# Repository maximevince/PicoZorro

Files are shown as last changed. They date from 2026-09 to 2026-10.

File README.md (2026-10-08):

# PicoZorro

An RP2350 microcontroller on the Amiga **Zorro II** bus. PIO state machines
speak the bus protocol, XRDY inserts wait states while the firmware fetches
the data, and the card's registers appear in the Amiga's address space
through Autoconfig. No CPLD, no FPGA, no level shifters. Open hardware,
open firmware, open drivers.

The first card is the **PicoZorro One**: Ethernet, a USB host port and an
MP3 decoder for an A2000-class Zorro II slot. Its through-hole version, the
**PicoZorro One TH**, is built from off-the-shelf modules and a handful of
through-hole parts, so that anyone with a soldering iron can make one.

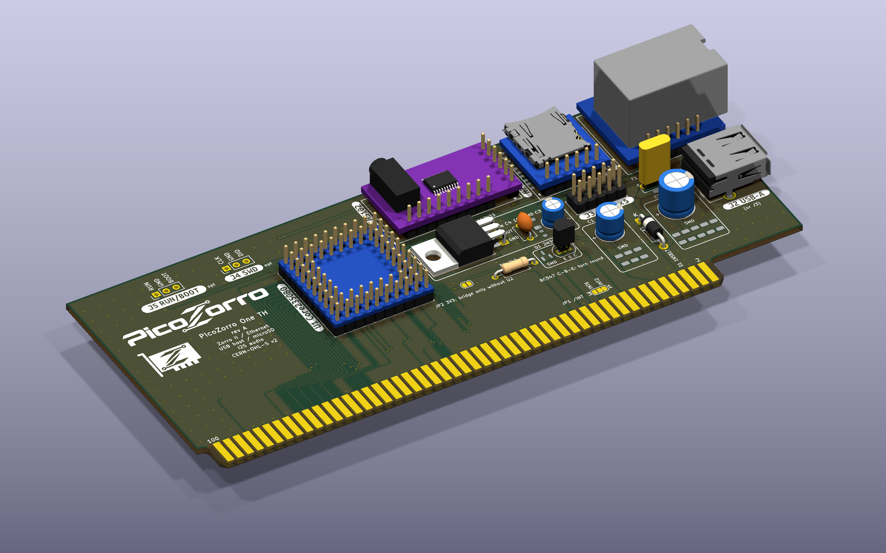
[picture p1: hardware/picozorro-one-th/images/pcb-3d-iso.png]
PicoZorro One TH, rev A


| What | How | Amiga side |
|---|---|---|
| Ethernet 10/100 | W5500 module on SPI | `picozorro.device`, a SANA-II driver (Roadshow, AmiTCP, ...) |
| USB host (full speed) | the RP2350's USB port | `picozorrousb.device` for Poseidon |
| MP3 / MP2 decoding | minimp3 on the card | `mpega.library`, a drop-in replacement for the 68k one |
| Boot ROM | the drivers served from the card | nothing to install: Kickstart loads them at boot |
| Firmware updates | A/B partitions in the module's flash | `pzflash` on the Amiga |

## One TH: two builds, one board

The One TH PCB carries two parts lists. Every through-hole part has an SMD
alternate on the same nets, in the same footprint area, and only one of
the two is ever fitted. Same Gerbers, same firmware, same Amiga software.

| DIY build (all through-hole) | JLC build (SMD set assembled by JLCPCB) |
|---|---|
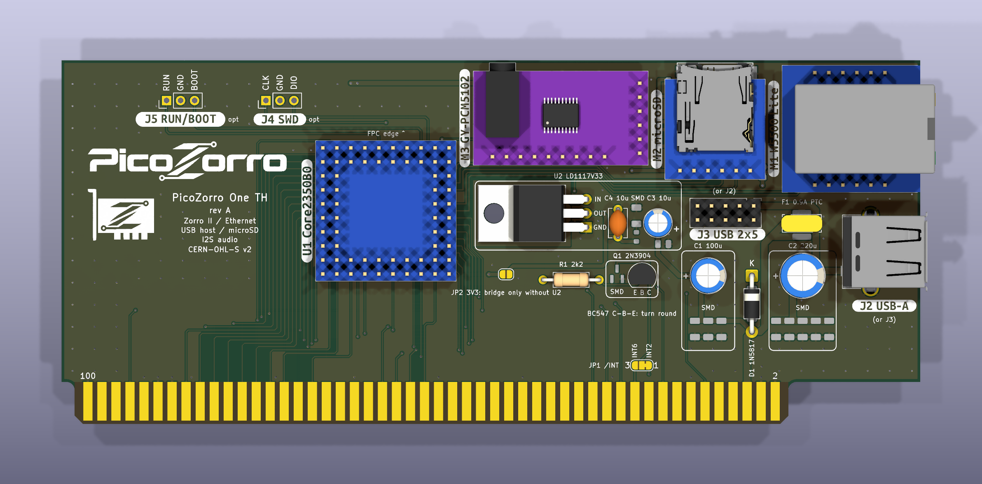
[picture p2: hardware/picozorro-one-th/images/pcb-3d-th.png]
One TH, DIY build
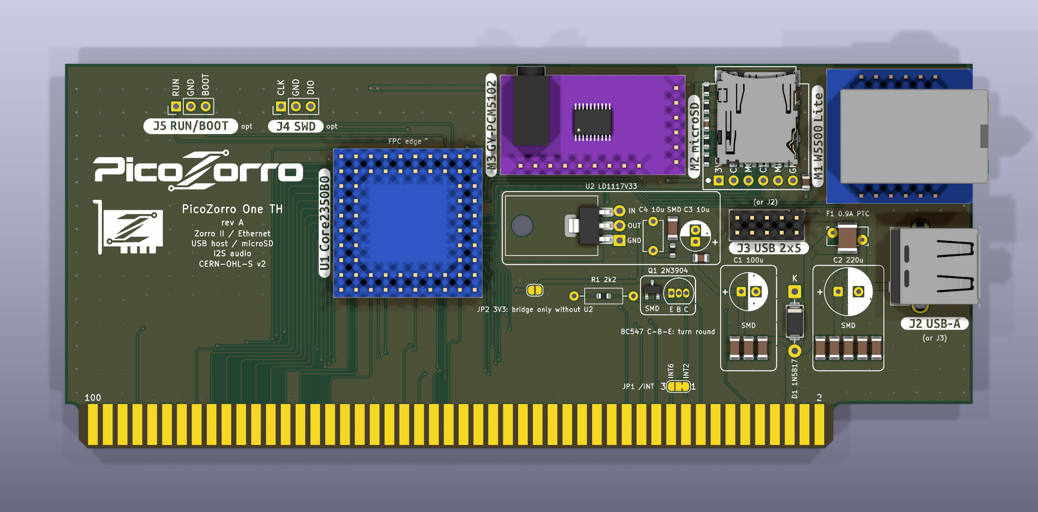
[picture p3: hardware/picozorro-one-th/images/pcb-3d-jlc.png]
One TH, JLC build
|  |  |
| KiCad's default variant. You solder everything: 1N5817, radial PTC, 2N3904, axial resistor, LD1117V33 in TO-220, electrolytics, a microSD breakout. | KiCad variant `JLC`. JLCPCB places SS14, 1812 PTC, MMBT3904, 0603 resistors, an AMS1117-3.3 (SOT-223) and banks of 22 uF MLCCs, plus a Hirose push-push microSD socket. You solder only the modules on their headers and the USB connector (J2 or J3). |
| Parts list: `fab/picozorro-one-th-parts.csv` | BOM and placement: `fab/jlc/picozorro-one-th-bom-jlc.csv`, `fab/jlc/picozorro-one-th-cpl-jlc.csv` |

Both builds take the same bought modules (Core2350B0, W5500 "Lite", the
optional GY-PCM5102 DAC). The silk frames each through-hole / SMD pair
under one label, so the board reads the same either way. Order options,
the full part-by-part table and the LCSC numbers are in
`hardware/picozorro-one-th/README.md` and `fab/order-notes.txt`.

## Status

- Firmware and drivers run on a prototype (a Core2350B module on a carrier
  board) in an Amiga: Ethernet, USB mass storage, MP3 playback.
- The **PicoZorro One TH** board is designed, routed and passes ERC/DRC.
  It has **not been built yet**. Do not order boards until this says so.
- The default firmware build is the One's image (features `xrdy-direct`,
  `int-nfet`, `usb-host`); the One TH and the One SMD share one pin map
  and one image. The four pins that differ from the prototype
  (microSD chip select, I2S) are unused, and the text log on GPIO46 lands
  on the DAC's bit-clock pin, which is harmless while no DAC is fitted.
- microSD and the I2S DAC are on the board for later; no firmware uses
  them yet.

## Repository

| Path | What |
|---|---|
| `hardware/picozorro-one-th/` | KiCad project, fabrication files, parts list and design notes of the One TH |
| `hardware/lib/` | the PicoZorro KiCad library (the Zorro II edge connector) |
| `hardware/EDGE_CONNECTOR.md`, `hardware/PINMAP.md` | edge-connector orientation with its evidence; the GPIO map |
| `firmware/` | RP2350 firmware in Rust on embassy: `pz-core` (Autoconfig, register window, network model, host tests), `pz-hal`, `pz-app` (the `picozorro` image, `hello`, `nic-demo`, `bus-listen`) |
| `amiga/` | the Amiga drivers, `mpega.library`, `pzflash`, the boot ROM, test and diagnostic tools; built with bebbo's GCC in docker |
| `tools/` | firmware image tools: update file, boot image, flashing |
| `docs/` | the register interface (`REGISTERS.md`, `REGISTERS-USB.md`, `REGISTERS-MPEG.md`), firmware updates (`UPDATE.md`), Zorro II electrical facts |

## From a bare board to a network

1. Build the card: `hardware/picozorro-one-th/README.md` (parts list,
   fabrication files, what to check before the first power-up).

   Steps 2 and 3 can be skipped: each
   [release](https://github.com/maximevince/PicoZorro/releases) carries
   `picozorro-install.uf2`, `picozorro.pzf` and the Amiga software, built
   by CI (`.github/workflows/build.yml`).
2. Build the Amiga software once, it goes into the firmware's boot image:

       make -C amiga toolchain   # once: pulls the image, fetches NDK 3.2 and the Poseidon headers
       make boot                 # drivers + boot ROM -> firmware/boot.img

3. Build and install the firmware, module on the bench, not in the Amiga:

       make fw-uf2               # firmware/picozorro-install.uf2

   Hold BOOTSEL while plugging the module's USB into the PC and copy
   `picozorro-install.uf2` onto the USB drive that appears. With an SWD
   probe, `make fw-install` does the same over SWD. This writes the A/B
   partition layout, so later updates come from the Amiga
   (`docs/UPDATE.md`), no cable needed. The UF2 route has not been
   exercised on a module yet; the SWD route has.
4. Card in the slot, Amiga on. Kickstart finds the card (manufacturer 2011,
   product $5A), loads `picozorro.device`, `picozorrousb.device` and
   `mpega.library` from it. Point your TCP/IP stack at `picozorro.device`
   unit 0 and Poseidon at `picozorrousb.device`: `amiga/README.md`.

Other targets: `make` (host tests + every firmware binary), `make amiga`,
`make fw-uf2 BIN=hello` (a first-light image as UF2), `make check-one-th`
(ERC + DRC). Needs: rustup (stable; the toolchain file adds the target),
arm-none-eabi-gcc (the MP3 decoder is C), picotool, probe-rs with RP2350
support for SWD, cargo-binutils for the update and install files; for `make amiga`:
docker, lha (or 7z), curl. Details in `firmware/README.md` and `amiga/README.md`.

## Safety

The card sits on the CPU bus of a machine that is not made any more.
Open-collector lines (XRDY, /INT2, /INT6) are never driven high. The
edge-connector orientation is documented with its evidence in
`hardware/EDGE_CONNECTOR.md`; check it against your board before powering
anything.

## Why the RP2350 sits on the 5 V bus without level shifters

The Zorro II bus is 5 V TTL. The RP2350's GPIO0-39 are fault-tolerant pads:
Raspberry Pi specifies them to 5.5 V **as long as IOVDD (the chip's 3.3 V)
is powered**. With IOVDD at 0 V the same pad is only rated to 3.63 V, and the
datasheet says a pad above that with IOVDD off will be damaged. So the whole
question is the first milliseconds after switch-on: can the bus be above
3.63 V before the card's 3.3 V regulator has come up?

Reasoning first: the bus drivers and pull-ups are fed from the same +5 V
rail that feeds the card's regulator, so no bus line can be ahead of that
rail. Below regulation an LDO just passes its input minus a drop, so IOVDD
follows the rail closely. The datasheet's limit only bites if the regulator
*delays* its start by more than the time the rail needs to travel from where
the LDO can start (about 2.3 V) to 3.63 V.

Then measured, with a logic analyser's analog channels:

- An Amiga's Zorro +5 V rises to 5.1 V in 3.4 ms; **2.3 V to 3.63 V takes
  about 1 ms**, 3.63 V to 4.2 V another 0.5 ms.
- The Core2350B's regulator (ME6217, 3.3 V), hit with a hard 5 V step on its
  input as the worst case: **3V3 reaches 3 V about 50 us later.**

50 us against 1 ms is a 20x margin, and on the real ramp the regulator does
not even see a step. IOVDD is therefore always above 1.8 V when the bus
passes 3.63 V and above 2.5 V when it passes 4.2 V, which is what the
datasheet's rating table asks for. The silicon on the module is an A4
stepping, the one Raspberry Pi qualified as 5 V tolerant; the erratum that
made A2 parts leak (RP2350-E9) is fixed from A3 on.

What this does **not** cover: hot-plugging a card into a live machine, or a
card whose 3.3 V rail is dead while the bus is up. Both put 5 V on unpowered
pads. Don't.

## Licence

Copyleft on purpose: forks stay open.

- Firmware, tools and the Amiga software: **GPL-3.0-or-later**
  (`LICENSES/GPL-3.0-or-later.txt`). The Rust dependencies (embassy and
  friends, MIT / Apache-2.0) are compatible. Vendored code keeps its own
  licence: `firmware/vendor/`.
- Hardware (`hardware/`): **CERN-OHL-S-2.0**, strongly reciprocal
  (`LICENSES/CERN-OHL-S-2.0.txt`).
  Three of the 3D models in `hardware/picozorro-one-th/3d/` embed parts of
  the KiCad library and are CC BY-SA 4.0 with KiCad's exception
  (`3d/SOURCES.txt`).
- Documentation: **CC BY-SA 4.0** (`LICENSES/CC-BY-SA-4.0.txt`).

Copyright Maxime Vincent.

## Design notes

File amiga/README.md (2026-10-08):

# Amiga software

Drivers, library and tools for the PicoZorro card, plain 68000 code for
AmigaOS 2.04 (V37) and up.

| Component | What it is |
|---|---|
| `picozorro.device` | SANA-II network driver for the card's Ethernet, for Roadshow, AmiTCP and other SANA-II stacks. `s2test` checks it command by command without a network (`ENV:PZNET` = `loop`). |
| `picozorrousb.device` | USB host-controller driver for Poseidon (legacy `IOUsbHWReq` interface): a root hub with one port, control, bulk and interrupt transfers. `usbtest` enumerates a device without Poseidon; `stortest` reads (and optionally writes) a USB stick through Poseidon's `usbscsi.device`. |
| `mpega.library` | Drop-in `mpega.library` 2.x: MP3 / MP2 decoded on the card, the PCM returned as the original library returns it, for players that use it. `mpegtest` drives it as a player does. |
| `pzflash` | Firmware update from the Amiga, see `docs/UPDATE.md`. |
| `bootrom` | The card's boot ROM (`boot.bin`, 256 bytes at most): Kickstart runs it at boot and it loads the drivers and the library from the card, so they need no files on disk. `tools/mkboot.py` puts it and the modules into the firmware's boot image (`make boot` at the top). |
| `pztest` | Finds the card and checks its scratch register with word and byte accesses. |
| `pztools/pzbench` | Zorro II bandwidth to the card's register window, per access pattern. |
| `pztools/pzload` | CPU load meter (window, optional log file). |
| `pztools/memdump` | Copies a range of the address space to a file (expansion ROMs, the card's registers). |
| `pztools/devinfo` | Mount parameters of every filesystem device. |
| `pztools/memcheck` | Walks exec's free memory lists and task lists without validating calls, for tracking down memory corruption. |

`common/` holds what the drivers share: `compiler.h` (register arguments)
and the developer links below.

## Building

The tree builds with bebbo's m68k-amigaos-gcc and vasm from a docker image
pinned by digest (`common/gcc.mk`). Once:

    make toolchain

pulls the image and fetches into `.toolchain/` what it does not carry: the
NDK 3.2 R4 from Aminet (`http://aminet.net/dev/misc/NDK3.2.lha`, for the
SANA-II and Roadshow headers; needs `lha` or `7z`) and Poseidon's headers from
`github.com/rondoval/poseidon-backport` at a pinned commit. Then:

    make            # everything
    make clean

A local bebbo install works too: `make AMIGA_GCC=m68k-amigaos-gcc
AMIGA_VASM=vasmm68k_mot`. `make DEBUG=1` in a driver's directory builds it
with log lines on the serial port. `make PROF=1` in `picozorrousb.device`
builds the driver with E-clock timestamps around every interrupt IN report;
`pzusbprof` (built there too) prints them, `pzusbprof reset` zeroes them.

## Installing

With the card's boot ROM on (the default with a boot image in the
firmware), Kickstart loads `picozorro.device`, `picozorrousb.device` and
`mpega.library` from the card at boot; `pzflash BOOTROM ON|OFF` switches it
from the next reset. Installed from disk instead, or to run a newer build:

- `picozorro.device` to `DEVS:Networks/`. Roadshow: an interface file such
  as `DEVS:NetInterfaces/PicoZorro` with
  `device=picozorro.device`, `unit=0`, `configure=dhcp`. Other stacks take
  the same device name and unit 0.
- `picozorrousb.device` to `DEVS:USBHardware/`; select it, unit 0, in
  Poseidon's Trident prefs. `usbtest` opens it from `DEVS:`.
- `mpega.library` to `LIBS:`.
- `pzflash`, `pztest` and the tools anywhere in the path.

The drivers look for the card through expansion.library (manufacturer
2011, product $5A) and take its interrupt on /INT2. With the card's
interrupt on /INT6, set `ENV:PZNET` and `ENV:PZUSB` to `pz 6`
(`SetEnv SAVE PZNET "pz 6"`). `ENV:PZUSB` also takes `minpoll=N` after the
backend (`pz minpoll=4`): the floor for the poll interval of interrupt
endpoints in ms, default 10, 0 for none.

## Developer backends

Besides the card on the Zorro bus (backend `pz`), the drivers can reach the
card's registers, or a stand-in, over other links: `bp` (the register
window over a serial line, `common/bpclient.c` and `common/serlink.c`, to a
module running `picozorro` with the `uart-backplane` feature), `uae` (a
lower SANA-II device under FS-UAE for picozorro.device, a UDP tunnel for
picozorrousb.device), `ser` (picozorrousb.device's tunnel over a serial
line) and `loop` (picozorro.device, frames come straight back). They are
selected with `ENV:PZNET`, `ENV:PZUSB`, `ENV:PZMPEGA` and `pzflash BP`, and
let the drivers be developed against FS-UAE or a bench PC; the test bed
itself is not published yet.

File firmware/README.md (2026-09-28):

# PicoZorro firmware (Rust, embassy)

The firmware of the PicoZorro cards: an RP2350B serves the Zorro II bus from
PIO and core 1, and runs the Ethernet chip, the USB host and the MPEG audio
decoder on core 0. Cargo workspace:

| Crate | What |
|---|---|
| `pz-core` | `no_std`, no dependencies: Autoconfig ROM and slave (`autoconfig`, `slave`), register window (`window`), network model (`nic`: rings, STATS, MCAST), USB window (`usb`), MPEG registers (`mpeg`), firmware update registers (`update`), boot ROM and boot stream (`boot`), pin map (`pins`: one map for every board), MAC rule (`mac`). Runs on the host: `cargo test-host`. |
| `pz-hal` | embassy-rp pieces the images share: `chip` (the Ethernet chip on SPI1, features `nic-w5500` / `nic-enc28j60` / `nic-poll`, which `pz-app` forwards), `usb::cdc_with_reset` (CDC ACM plus the picotool reset interface), `usb_host` (the RP2350 as USB host for Poseidon, feature `usb-host`), `backplane` (see "Developer features"). |
| `pz-app` | The RP2350B images, below. |

Images (`pz-app` binaries):

| Binary | What |
|---|---|
| `picozorro` | The card's firmware. Core 1: the bus slave (`zbus.rs`, from RAM). Core 0: the Ethernet chip if one answers on SPI1 (none: bus slave only, link down, TX frames dropped), the USB host or the USB log, the MPEG decoder, the firmware update and boot stream tasks, a text log on GPIO46 (115200 8N1). |
| `hello` | First light without a probe: `log` over USB CDC, chip stepping, package, OTP chip ID and MAC, LED heartbeat, picotool reset interface. |
| `nic-demo` | Ethernet chip check on SPI1 (W5500 by default, ENC28J60 with `nic-enc28j60`): DHCP, ping, TCP echo on port 7, defmt over RTT. |
| `bus-listen` | Passive bus listener for a card's first power-up in an Amiga: drives nothing on the bus, reports the bus pins and /AS statistics once per second over the UART and USB CDC. |

## Build

Needs rustup (the toolchain file installs stable with the
`thumbv8m.main-none-eabihf` target) and `arm-none-eabi-gcc` for the MPEG
decoder (minimp3 is C).

    cargo build --release                       # every image, default features
    cargo test-host                             # pz-core's tests on the host

The default features build the PicoZorro One's image: XRDY from the GPIO,
/INT through its transistor, the USB port as host. The One TH and the One
SMD share one pin map and one image.

For bring-up, the same image with the USB port as a CDC log instead of the
USB host (`usb-log`):

    cargo build --release --bin picozorro --no-default-features \
        --features nic-w5500,mpeg,oc240,xrdy-direct,int-nfet,usb-log

The ELFs land in `target/thumbv8m.main-none-eabihf/release/`.

`build.rs` embeds a boot image if there is one (`firmware/boot.img`, or the
path in `PZ_BOOT_IMG`), made by `tools/mkboot.py` from the Amiga modules;
without one the card has no boot ROM. `PZ_VERSION` overrides the version
string (default: crate version and git short hash).

## Flash

With an SWD probe (Raspberry Pi Debug Probe, J-Link, ...) and probe-rs 0.25
or later (`cargo install probe-rs-tools --locked`), `cargo run` flashes and
streams the defmt log over RTT:

    cargo run --release --bin picozorro [--features ...]

Without a probe, as a UF2 file: hold BOOTSEL while the module powers up,
it shows up as a USB drive, copy the file onto it. `make fw-uf2` (top
level) writes `firmware/picozorro-install.uf2`, which installs `picozorro`
partitioned (`docs/UPDATE.md`); `make fw-uf2 BIN=hello` writes a plain UF2
of any other image. Or over USB with picotool:

    picotool load -f -x -t elf target/thumbv8m.main-none-eabihf/release/picozorro

`-f` reboots an image that has the reset interface (`hello`, `bus-listen`,
`picozorro` with `usb-log`) into BOOTSEL first; otherwise hold BOOTSEL while
the module powers up. picotool needs access to the RP2350's USB device
(VID 2e8a): a udev rule such as

    SUBSYSTEM=="usb", ATTRS{idVendor}=="2e8a", MODE="0660", TAG+="uaccess"

in `/etc/udev/rules.d/99-picotool.rules`, or sudo.

`cargo run`, `picotool load` and a plain UF2 write the image to the start
of flash. The A/B partition layout that firmware updates from the Amiga need
is described in `docs/UPDATE.md`.

## Features (`pz-app`)

Default (the PicoZorro One): `nic-w5500`, `mpeg`, `oc240`, `xrdy-direct`,
`int-nfet`, `usb-host`. The other features are alternatives for other
wiring or for bring-up; `usb-log` and `nic-enc28j60` replace a default, so
they go with `--no-default-features` and the rest of the list.

| Feature | What |
|---|---|
| `nic-w5500` | W5500 Ethernet chip on SPI1. |
| `nic-enc28j60` | ENC28J60 instead (`nic-demo`; use with `--no-default-features`). |
| `nic-poll` | W5500 without /INT: the RX size is polled every 500 us; frees GPIO39. |
| `xrdy-direct` | XRDY driven from GPIO27 (the PicoZorro One). Without it: an on-board gate pulls XRDY, the PIO drives /ARM. |
| `int-nfet` | /INT through a transistor (N-MOSFET or NPN): GPIO45 push-pull, high asserts (the PicoZorro One). Without it: an open-drain buffer, low asserts. |
| `mpeg` | MPEG audio decoder for mpega.library (`docs/REGISTERS-MPEG.md`). Needs `arm-none-eabi-gcc`. |
| `usb-host` | The USB port as host for Poseidon (`docs/REGISTERS-USB.md`). Not with `usb-log`. |
| `usb-prof` | `usb-host` plus a timing profile and flight recorder of USB transfers, read over SWD. |
| `write-guard` | `usb-host` refuses writes to the mass-storage sticks listed in `pz_hal::usb_host`. |
| `usb-log` | The USB port as a device instead of `usb-host`: CDC ACM text log plus the picotool reset interface, for bring-up. |
| `oc240` | clk_sys 240 MHz at 1.15 V (above the RP2350's 150 MHz rating). Without `oc240` / `oc300`: 150 MHz. |
| `oc300` | clk_sys 300 MHz at 1.25 V. |
| `bus-prof` | Core 1 cycle counts per bus cycle and loop pass in the log. |
| `bench-host` | Developer build, see below. |
| `uart-backplane` | Developer build, see below. |

## Developer features

`bench-host`, `uart-backplane` and pz-hal's `backplane` module are links
that let the firmware run without an Amiga: `bench-host` has core 1 play
the Amiga driver for network tests from a PC, `uart-backplane` serves the
register window over UART0 (GPIO0/1) so that FS-UAE or a PC tool can drive
the card's models. Neither image is for a card in an Amiga (GPIO0/1 are bus
data lines). The test bed they connect to is not published yet.

## embassy

The embassy crates come from embassy git main, for the RP2350 USB host
driver that no release has yet, through a fork
(`https://github.com/maximevince/embassy`) with embassy-rp fixes for the
USB host and BufferedUart. The workspace `Cargo.toml` swaps them in with
`[patch.crates-io]`; the crates keep their crates.io version requirements.
On main, embassy-net runs on the xarxa stack: sockets have no buffers of
their own and take packets from a global pool.

`vendor/embassy-net-wiznet` is main's W5500 driver plus PicoZorro's
additions (MAC filter switch, PHY state, interrupt wake-up count, recovery
of a chip that lost its set-up), see its `CHANGELOG.md`. `vendor/minimp3`
is lieff/minimp3, unchanged. `pz-app/memory.x` and `build.rs` follow
embassy's `examples/rp235x`.

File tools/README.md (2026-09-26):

# Tools

PC-side helpers for building and installing PicoZorro (Python 3, POSIX sh).

| Tool | What it does |
|---|---|
| `mkpzf.py` | Makes a firmware update file (`.pzf`) from the firmware ELF, for `pzflash` on the Amiga (`make fw-pzf`, `docs/UPDATE.md`). With `--bin --no-tbyb`, the plain image for an SWD install; with `--uf2 pt.bin`, the install UF2 for a drop on the module in BOOTSEL mode (`make fw-uf2`). Needs `rust-objcopy` (cargo-binutils). |
| `mkboot.py` | Builds the firmware's boot image from the boot ROM (`amiga/bootrom/boot.bin`) and the Amiga drivers it loads at boot (`make boot`). |
| `pz_install.sh` | Installs the firmware with the A/B partition table, so it can be updated from the Amiga afterwards (`make fw-install`), over SWD with `probe-rs`. Needs `picotool` for the partition table. Without a probe, `make fw-uf2` writes the same content as a UF2 file. |

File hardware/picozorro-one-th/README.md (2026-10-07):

# PicoZorro One TH

The PicoZorro One is the Zorro II network and USB card of the PicoZorro
project. The One TH is its through-hole version: bought modules and a
handful of through-hole parts on a bare two-layer PCB. Every through-hole
part also has an SMD alternate on the same board, so the same PCB can be
assembled by JLCPCB instead (see "Two builds" below).

- RP2350B: a Waveshare Core2350B0 module (B0 variant, no PSRAM) on four
  2x8 pin strips. Its PIO state machines speak the Zorro II bus directly.
- Ethernet: a W5500 "Lite" module (USR-ES1, WIZnet WIZ850io pinout) on SPI1.
- USB host: the RP2350's own USB port, to a type A receptacle or a PC-style
  2x5 internal header.
- Optional: microSD on SPI1 (a breakout, or a soldered socket on the JLC
  build) and a GY-PCM5102 I2S DAC breakout.

3D render of the component side, DIY build

## Status

Rev A. The schematic and the routed board pass KiCad ERC and DRC with zero
violations, DRC with schematic parity (`make check-one-th` at the top of the
repository). **The board has not been built or tested in an Amiga. Do not
order boards yet.** The open points are listed at the end of this file.

## Two builds: DIY through-hole and JLC-assembled

One PCB, two builds. The **DIY build** (KiCad's default variant) fits every
part through-hole, soldered by hand. The **JLC build** (KiCad variant `JLC`)
has JLCPCB place an SMD set, almost all JLC Basic parts; the builder then
solders only the modules on their headers and J2 (or J3).

Each through-hole part and its SMD alternate sit on the same nets and share
the footprint area; the two are never both fitted. The SMD alternate of a
part has the part's number times 100 plus 1, 2, ... as its reference (D101 is
D1's, C101-C103 are C1's bank), because KiCad cannot give one symbol two
footprints. The board hides those references; silk frames group each pair
under one label, and the JLC files name them "D1 (SMD)".

3D render of the component side, JLC build

## Files

| Path | What |
|---|---|
| `picozorro-one-th.kicad_pro`, `.kicad_sch`, `.kicad_pcb`, `.kicad_dru` | KiCad 10 project with the variant `JLC`; the edge-connector symbol and footprint come from `../lib` |
| `fab/gerbers/`, `fab/picozorro-one-th-gerbers.zip` | Gerber and Excellon drill files, the same for both builds |
| `fab/picozorro-one-th-parts.csv` | parts list of the DIY build (the SMD alternates show DNP) |
| `fab/jlc/picozorro-one-th-bom-jlc.csv`, `fab/jlc/picozorro-one-th-cpl-jlc.csv` | JLC BOM (the SMD set with LCSC numbers; the through-hole alternates as DNP) and placement file (SMD set only, rotations corrected for JLC) |
| `fab/order-notes.txt` | the options to pick in the order form, and what the builder solders in each build |
| `3d/` | STEP models of the modules and the PTC that the board references; origins and licences in `3d/SOURCES.txt` |
| `images/` | schematic (PDF, PNG), copper and silkscreen views, 3D renders: `pcb-3d-th.png` (DIY build), `pcb-3d-jlc.png` (JLC build, same view), `pcb-3d-iso.png` (DIY build, isometric) |

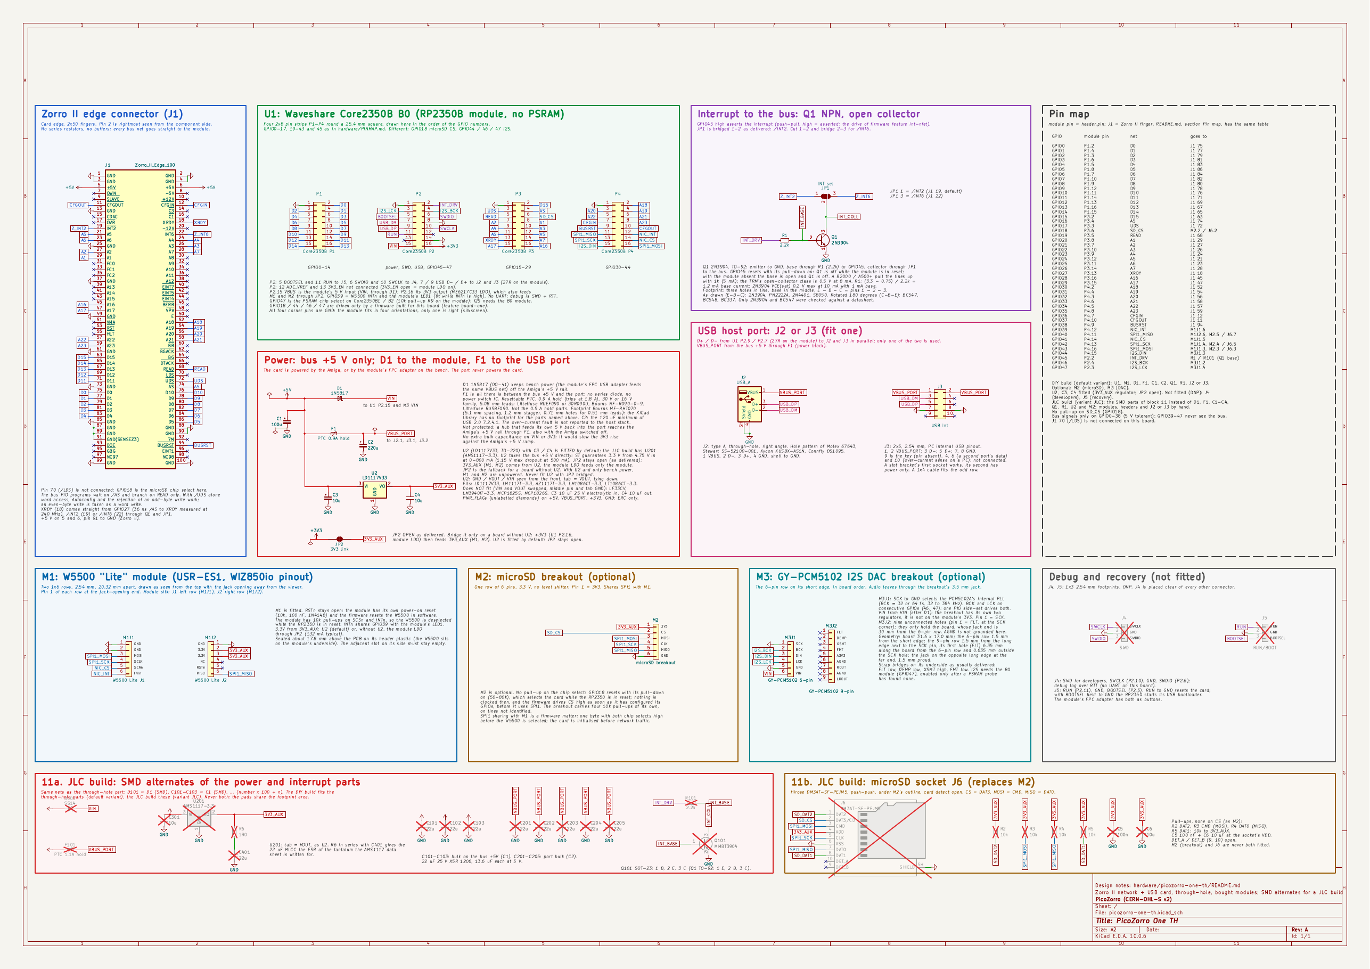
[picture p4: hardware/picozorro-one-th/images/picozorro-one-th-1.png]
Schematic


## What the builder solders

DIY build, everything by hand. The last column names the SMD alternate the
JLC build fits instead (LCSC part number in brackets; JLC Basic parts unless
marked Extended).

| Ref | Part | Value / type | Package | Fitted (DIY) | JLC build alternate |
|---|---|---|---|---|---|
| U1 (P1-P4) | Waveshare Core2350B0 module (no PSRAM) | - | four 2x8 2.54 mm pin strips | yes | same, by hand |
| M1 | W5500 "Lite" module (USR-ES1, WIZ850io pinout) | - | two 1x6 2.54 mm rows | yes | same, by hand |
| M2 | microSD breakout, 3.3 V, no level shifter | - | one 1x6 2.54 mm row | optional | J6, Hirose DM3AT-SF-PEJM5 push-push socket (C114218, Extended), with R2-R5 and C5, C6 |
| M3 | PCM5102A DAC breakout "GY-PCM5102" | - | 1x6 row (signals) + 1x9 row (holding only) | optional | same, by hand (optional) |
| D1 | Schottky diode | 1N5817 | DO-41, 10.16 mm | yes | D101, SS14, SMA (C2480) |
| F1 | resettable PTC fuse, 30 V (or 16 V) family | 0.9 A hold, e.g. Littelfuse RUEF090 | radial, 5.08 mm leads | yes | F101, 1.1 A hold, 1812, Littelfuse 1812L110/33MR (C142747, Extended) |
| C1 | electrolytic capacitor, bus +5 V | 100 uF | radial, D6.3 mm, 2.5 mm pitch | yes | C101-C103, 3 x 22 uF 25 V X5R 1206 (C12891) |
| C2 | electrolytic capacitor, USB port | 220 uF | radial, D8 mm, 3.5 mm pitch | yes | C201-C205, 5 x 22 uF 25 V X5R 1206 (C12891) |
| U2 | 3.3 V regulator for 3V3_AUX | LD1117V33 | TO-220, lying down | yes | U201, AMS1117-3.3, SOT-223, tab = VOUT (C6186) |
| C3 | U2 input capacitor | 10 uF 25 V electrolytic | radial, D5 mm, 2 mm pitch | yes | C301, 10 uF 25 V X5R 0805 (C15850) |
| C4 | U2 output capacitor | 10 uF | disc, 5 mm pitch | yes | R6 1.0 ohm 0603 (C22936) in series with C401 22 uF 1206 (C12891) |
| Q1 | NPN transistor | 2N3904 | TO-92, E-B-C | yes | Q101, MMBT3904, SOT-23, 1 B / 2 E / 3 C (C20526) |
| R1 | resistor, GPIO45 to Q1 base | 2.2 k | axial, DIN0207, 10.16 mm | yes | R101, 2.2 k 0603 (C4190) |
| J2 | USB 2.0 type A receptacle, right angle | Molex 67643 pattern | through-hole | one of J2 / J3 | same, by hand |
| J3 | PC internal USB header | 2x5, pin 9 absent | 2.54 mm header | one of J2 / J3 | same, by hand |
| J4 | SWD header: SWCLK / GND / SWDIO | - | 1x3 2.54 mm | no (developers) | same |
| J5 | recovery header: RUN / GND / BOOTSEL | - | 1x3 2.54 mm | no (recovery) | same |

The JLC build adds, with J6 only: R2-R5, 10 k 0603 pull-ups on DAT2, CMD
(MOSI), DAT0 (MISO) and DAT1 (C25804); C5 100 nF 0603 (C14663) and C6
10 uF 0805 (C15850) at J6's VDD.

U1 must be the B0 variant in both builds: on the B1 / B2 modules GPIO47 is
the PSRAM chip select, and this board needs GPIO47 for the I2S word clock.
The microSD chip select (GPIO18) works on any variant.

The parts lists are `fab/picozorro-one-th-parts.csv` (DIY) and
`fab/jlc/picozorro-one-th-bom-jlc.csv` (JLC).

F1 alternatives: Littelfuse RUEF090 or 30R090U, Bourns MF-R090-0-9,
Littelfuse RUSBF090 (0.07-0.12 ohm new, 0.22 ohm at most after a trip;
holds 0.57-0.61 A at 60 C). Not the 0.5 A hold parts: they hold 0.36 A at
50 C and drop up to 0.59 V. The footprint is KiCad's
`Fuse_Bourns_MF-RHT070` (5.1 mm lead spacing with the 1.2 mm stagger of a
radial PTC's leads, 0.71 mm holes for 0.51 mm leads); the KiCad library
has no footprint for the parts named above.

Q1 alternatives: the footprint is three holes in line, base in the middle,
emitter - base - collector as pins 1-2-3.

| Part | Pin order 1-2-3 | Fits |
|---|---|---|
| 2N3904, PN2222A, 2N4401, S8050 | E-B-C | as drawn |
| BC547, BC548, BC337 | C-B-E | rotated 180 degrees (silkscreen: "BC547 C-B-E: turn round") |

Only the 2N3904 and the BC547 were checked against a data sheet; check the
others before fitting.

U2 alternatives (pin order GND / VOUT / VIN seen from the front, tab =
VOUT): LD1117V33, LM1117T-3.3, AZ1117T-3.3, LM1086CT-3.3, LT1086CT-3.3.
They do not fit with VIN and VOUT swapped, middle pin GND, tab GND: LF33CV,
LM3940IT-3.3, MCP1825S, MCP1826S. The silkscreen names the three holes.
C3 is an electrolytic: mind its polarity.

## Solder jumpers

| Jumper | As delivered | Change |
|---|---|---|
| JP1 | bridged 1-2 by a trace: Q1 collector to /INT2 (J1 pin 19) | cut 1-2 and bridge 2-3 for /INT6 (J1 pin 22) |
| JP2 | **open** in both builds: U2 (DIY) or U201 (JLC) supplies 3V3_AUX | fallback for a board without U2: bridge it, and the module's 3V3 (U1 P2.16) feeds 3V3_AUX. Never bridge it with U2 or U201 fitted |

## Pin map

The PicoZorro GPIO map (`../PINMAP.md`) applies to GPIO0-17, 19-43 and 45.
Four pins differ on this board:

| GPIO | Module pin | Shared map | This board |
|---|---|---|---|
| 18 | P3.6 | /LDS | microSD chip select |
| 44 | P4.15 | /ARM | I2S data (DIN) |
| 46 | P2.4 | UART0 TX | I2S bit clock (BCK) |
| 47 | P2.3 | not connected / PSRAM chip select | I2S word clock (LCK), B0 module only |

The whole map:

| GPIO | Signal | Goes to |
|---|---|---|
| 0-15 | D0-D15 | J1 |
| 16 | /AS | J1 74 |
| 17 | /UDS | J1 72 |
| 18 | SD_CS | M2 pin 2 / J6 DAT3 |
| 19 | READ | J1 68 |
| 20-26 | A1-A7 | J1 |
| 27 | XRDY | J1 18, direct |
| 28-35 | A16-A23 | J1 |
| 36 | /CFGIN | J1 12 |
| 37 | /CFGOUT | J1 11 |
| 38 | /BUSRST | J1 94 |
| 39 | NIC_INT | M1 INTn (the module's LED1 is on the same pin, lit while INTn is high) |
| 40 | SPI1 MISO | M1, M2 / J6 DAT0 |
| 41 | NIC_CS | M1 SCSn |
| 42 | SPI1 SCK | M1, M2 / J6 CLK |
| 43 | SPI1 MOSI | M1, M2 / J6 CMD |
| 44 | I2S_DIN | M3 |
| 45 | INT_DRV | R1 / R101, Q1 / Q101 base |
| 46 | I2S_BCK | M3 |
| 47 | I2S_LCK | M3 |

Bus signals use only GPIO0-38 (5 V tolerant); GPIO39-47 never see the bus.
The bus nets go straight from the edge fingers to the module pins: no series
resistors, no buffers. XRDY comes from GPIO27 directly (36 ns from /AS to
XRDY measured at 240 MHz). The edge connector (J1) has +5 V on pins 5 and
6, all GND pins connected and pin 91 tied to GND.

There is no UART: debug is SWD with RTT on J4.

**/LDS (J1 pin 70) is not connected.** The bus PIO programs wait on /AS and
branch on READ only; the strobes are two bits of the sampled word, used by
the register model to tell word from byte access. With /UDS alone, word
access, Autoconfig (its writes are /UDS-only bytes on D15-D8) and the
rejection of an odd-byte write (/UDS high) work; an even-byte write cannot be
told from a word write and is taken as a word write.

**GPIO47 and the module variant.** On the Core2350B B1 / B2 modules the PSRAM
chip select sits directly on GPIO47 with a 10 k pull-up (R9); R11 (0 R) only
links the net to header pin P2.3. Driving GPIO47 there selects the PSRAM
during flash access. I2S therefore needs the B0 module, and the firmware
must not drive GPIO47 unless a PSRAM probe has found none.

### Firmware

The default firmware build is this board's image: its features
`xrdy-direct` (GPIO27 pulls XRDY) and `int-nfet` (GPIO45 push-pull, high
asserts /INT) match the bus side. The One TH and the One SMD share one pin
map and one image. GPIO18 / 44 / 46 / 47 may only be driven by a firmware
built for this board. The microSD and I2S
drivers are not written yet. When they are:

- SPI1 is shared. The SD card releases its data output one clock after its
  chip select rises, so the firmware clocks one byte with both chip selects
  high before selecting the W5500; each device gets its own SCK rate.
- An SD card that has not been put into SPI mode still listens to the
  command line. The firmware initialises the card before network traffic
  starts; a card inserted later sees W5500 traffic first.
- I2S is enabled only after a PSRAM probe has found none.

## Power

```
J1 +5V --+-- C1 --GND
         |
         +-- D1 -->|-- VIN ---- U1 P2.15 (VBUS: module LDO input)
         |                 +--- M3 VIN
         |
         +-- F1 ---+--- VBUS_PORT --- J2.1, J3.1, J3.2
         |         +--- C2 --GND
         |
         +-- C3 --- U2 --- C4 --- 3V3_AUX --- M1, M2 / J6

U1 P2.16 (3V3, module LDO output) --- JP2 (open; bridged only without U2) --- 3V3_AUX
```

JLC build: D101, F101 and U201 (C301 at its input, R6 + C401 at its output)
in place of D1, F1 and U2 (C3, C4); the bulk is two MLCC banks, C101-C103 on
the bus +5 V for C1 and C201-C205 on VBUS_PORT for C2 (40.9 and 68.2 uF
effective at 5 V). JP2 stays open in both builds.

- **D1** (Schottky) keeps bench power off the Amiga's +5 V rail: the
  module's FPC USB adapter feeds the same VBUS net.
- **F1** (PTC) is all there is between the bus +5 V and the USB port, as on
  PC motherboards (Intel 815E reference board; Intel, "Power Delivery Design
  Issues for Hi-Speed USB on Motherboards") and the fuse-only hobby host
  boards. No series diode (with a Schottky the port sat at about 4.45 V), no
  power switch IC.
- The card is powered by the Amiga, or by the FPC adapter on the bench. The
  port never powers the card.
- Not protected: a hub that feeds its own 5 V back into the port reaches the
  Amiga's +5 V rail through F1, also with the Amiga switched off. USB 2.0
  section 7.2.1 forbids a device to source current on its upstream port.

Port voltage from a 5.0 V rail at 500 mA: 5.0 - 0.06 (F1 new, 0.11 after a
trip) = 4.94 V (4.89 V). USB 2.0 Table 7-7 asks for 4.75 V at a high-power
port, so the rail may sag to 4.86 V. Section 7.2.1.2.1 asks for
resettable over-current protection below 5.0 A: F1 trips at 1.8 A (Intel's
guide sizes a single-port fuse at 1.5 A trip or more). The fault is not
reported to the host stack: there is no pin for it.

### Bulk: C1 and C2

USB 2.0 section 7.2.4.1 asks for no less than 120 uF of low-ESR capacitance
on the downstream VBUS "per hub", to keep the power of the other ports
within 330 mV when a device is plugged in (load model 10 uF with 44 ohm).
This card has one port: the only other load on that VBUS is the card's own
+5 V entry (D1 to VIN, U2) and, behind it, the Amiga rail. So both stay: C1
at the entry, C2 at the port, F1 between them (on a microsecond scale the
PTC is a plain resistor that isolates the two).

A hot-plug simulation (1 m cable, assumed rail and ESR values, not a
measurement) puts the entry droop at 0.23 / 0.15 V (PTC 0.1 / 0.3 ohm) with
the JLC build's ceramic banks, the smallest of the arrangements tried at
0.3 ohm, matched only by a low-ESR polymer 220 uF at the entry (0.22 /
0.17 V). The DIY build's two electrolytics give 0.43 / 0.29 V; a single
ordinary electrolytic at the entry (0.15 ohm ESR) 0.61 / 0.45 V, worse than
either split. The port itself dips 0.4 to 3 V for microseconds whatever is
fitted: no arrangement holds it within 330 mV with a stick plugged straight
in. Both builds lay the two groups out alike: the electrolytic on top, its
MLCC row under it in the 15 mm band.

### 3.3 V

3V3_AUX (M1, M2 / J6) has its own regulator, **U2, fitted in both builds**;
JP2 stays open and the module's LDO feeds only the module. The loads: M1
132 mA typical (W5500 data sheet section 5.4; the WIZ850io module 141 mA),
M2 up to 100 mA, the maximum averaged over 1 s in SPI mode (SD Physical
Layer Simplified Specification v3.01, Table 3-4 note 7; SanDisk's manual
gives 65 mA read and 75 mA write at most). The simplified specification
gives no peak or inrush figure. That is about 0.22 A typical, 0.24-0.27 A
at those ceilings. M3 is not on this rail: its VIN comes from VIN and it has
its own two regulators.

U2 takes the bus +5 V directly, not behind D1. DIY build: LD1117V33. ST
guarantees 3.235-3.365 V out for Vin 4.75-10 V at 0-800 mA (TJ 0-125 C,
LD1117 data sheet DocID2572 Rev 38, Table 6), dropout 1.15 V at most at
500 mA: it regulates from 4.45 V, a 0.30 V margin at the bus's 4.75 V
minimum. The JLC build fits U201, an AMS1117-3.3 (SOT-223, the same pin
order, tab = VOUT) under U2's footprint, its tab on the same 3V3_AUX copper
area. Its only guaranteed dropout is 1.3 V at 800 mA, so it needs 4.60 V: a
margin of about 0.15 V. R6 (1.0 ohm) in series with C401 (22 uF) at its
output gives the ceramic the ESR of the tantalum the AMS1117 data sheet is
written for. Dissipation in either build: (5.25 V - 3.3 V) x 0.3 A = 0.59 W
at most.

- C3, 10 uF at the input in both builds (DIY: 25 V radial electrolytic;
  JLC: C301, 0805 X5R): one value that satisfies the LD1117 (100 nF), the
  LM1117 and AZ1117 (10 uF) and the AMS1117 application circuit (10 uF). C4,
  10 uF at the output (ST's figure; ST gives no ESR window).
- With U2 fitted and the card on bench power only, M1 and M2 are unpowered
  while the module runs.

The module's regulator is the fallback (JP2 bridged on a board without
U2), not the default: the ME6217C33M5G data sheet gives 800 mA as a typical
IOUT(max) (and as the absolute maximum), no minimum, and notes it may not be
reached because of package dissipation; it gives no thermal resistance. Its
sibling ME6207 rates the SOT-23-5 package at 250 mW. The W5500 alone puts
0.25-0.41 W into it, with an SD card 0.45-0.66 W. Measured with a thermal
camera, module plus W5500 on the module's 3V3, room 20 C: nothing on the
module above 40 C (no SD card in that measurement).

There is no extra bulk capacitance on VIN or 3V3: it would slow the 3V3
rise against the Amiga's +5 V ramp.

## /INT driver

Q1, an NPN transistor, drives the interrupt line open collector: emitter to
GND, base through R1 (2.2 k) to GPIO45, collector through JP1 to /INT2
(default) or /INT6. GPIO45 high asserts the interrupt. GPIO45 resets with
its pull-down on, so Q1 is off while the module is in reset; with the module
absent the base is open and Q1 is off. GPIO45 is not 5 V tolerant, so it
cannot pull the bus line itself.

Sizing: a B2000 and an A500+ pull both lines up with 1 k (5 mA at 5 V); the
Technical Reference Manual's open-collector drive class is 0.5 V at 8 mA,
so the driver must sink at least 8 mA. R1 gives (3.3 - 0.75) / 2.2 k =
1.2 mA of base current. The 2N3904 is specified at VCE(sat) 0.2 V maximum
for 10 mA with 1 mA into the base, the BC547 at 0.25 V maximum (0.09 V
typical) for 10 mA with 0.5 mA: both operating points are covered with
margin.

A transistor and not a MOSFET: the through-hole MOSFETs hobby shops carry
(2N7000, BS170) have gate thresholds up to 3 V and are not specified at
3.3 V drive; the one that is (TN0702) is a distributor-only part. Small NPN
types are sold everywhere.

Simulated with ngspice (vendor models, 1 k to 10 k pull-ups, 4.75 to
5.25 V, 0 to 70 C, GPIO45 down to 3.0 V, R1 +5 %): /INT sits below 90 mV
with a 2N3904 and below 40 mV with a BC547B, also at a forced 8 mA;
GPIO45 sources 1.15 mA at most. Assertion takes under 125 ns into 1 nF.
Release is the pull-up RC plus the transistor's storage time: 0.25 to
0.5 us for the 2N3904, 1.4 to 2.2 us for the BC547B, so 10 k with 500 pF
reaches 2.0 V after 3.2 us (2N3904) or 4.9 us (BC547B). The 2N3904 is the
default for that reason.

## Modules

**M1, W5500 Lite.** Two 1x6 rows, 2.54 mm pitch, 20.32 mm apart; module
23.0 x 25.0 mm; pin 1 of each row at the jack-opening end, 6.4 mm from that
edge; the jack overhangs that edge by 2.5-2.7 mm. Seen from the top with the
jack opening away from the viewer (module silk J1 left, J2 right, jack
HR961160C):

| Left row (J1) | | Right row (J2) | |
|---|---|---|---|
| 1 GND | GND | 1 GND | GND |
| 2 GND | GND | 2 3.3V | 3V3_AUX |
| 3 MOSI | GPIO43 | 3 3.3V | 3V3_AUX |
| 4 SCLK | GPIO42 | 4 NC | - |
| 5 SCNn | GPIO41 | 5 RSTn | not connected |
| 6 INTn | GPIO39 | 6 MISO | GPIO40 |

RSTn stays open: the module has its own power-on reset (10 k, 100 nF,
1N4148) and the firmware resets the chip in software. The module has 10 k
pull-ups on SCSn and INTn, so the W5500 is deselected while the RP2350 is
in reset.

**M2, microSD breakout.** One 1x6 row: 3V3 (pin 1, to 3V3_AUX), CS (GPIO18),
MOSI (GPIO43), CLK (GPIO42), MISO (GPIO40), GND. Board 18 x 18 mm (18.1 mm
over its scored edges); the socket, 13.7 mm wide, overhangs the edge
opposite the pin row by 3 mm and the card enters from there. No pull-up on
the chip select: GPIO18 resets with its pull-down on (about 50-80 k), which
selects the card while the RP2350 is in reset; nothing is clocked then, and
the firmware drives the chip select high as soon as it has configured its
GPIOs, before it uses SPI1. The breakout carries four 10 k pull-ups of its
own, on lines not identified.

**J6, microSD socket (JLC build).** A Hirose DM3AT-SF-PEJM5 push-push socket
(KiCad `Connector_Card:microSD_HC_Hirose_DM3AT-SF-PEJM5`) under M2's
outline, on M2's nets, the card entering over the top edge as with M2: CS =
DAT3 (GPIO18), MOSI = CMD, CLK, MISO = DAT0, VDD = 3V3_AUX. 10 k pull-ups R2
(DAT2), R3 (CMD / MOSI), R4 (DAT0 / MISO), R5 (DAT1), none on CS; C5 100 nF
and C6 10 uF at VDD. Card detect (pins 9, 10) is not connected: no GPIO is
free. M2 and J6 are never both fitted.

**M3, GY-PCM5102.** The 6-pin row on its short edge: SCK to GND (selects the
PCM5102A's internal PLL), BCK to GPIO46, DIN to GPIO44, LCK to GPIO47, GND,
VIN to VIN. Pin 1 is SCK. The 9-pin row (FLT, DEMP, XSMT, FMT, A3V3, AGND,
ROUT, AGND, LROUT from the SCK corner) gets nine unconnected holes: it only
holds the board. Audio leaves through the breakout's 3.5 mm jack. The four
strap bridges on its underside stay as usually delivered: FLT low, DEMP
low, XSMT high, FMT low. BCK and LCK are on consecutive GPIOs so one PIO
side-set drives both; PLL mode accepts BCK = 32 fs or 64 fs from 32 kHz to
384 kHz. Geometry, from a third-party footprint (sstojos,
zynthian-miniature) cross-checked against board photos: board 31.6 x
17.0 mm; the 6-pin row 1.5 mm from the short edge; the 9-pin row 1.5 mm
from the long edge next to the SCK pin, its first hole (FLT) 6.35 mm along
the board from the 6-pin row and 0.635 mm outside the SCK hole.

## USB host port, debug and recovery

- The module's USB pins (D+ on P2.9, D- on P2.7, 27 R on the module) go to J2
  and J3 in parallel; only one of the two is fitted.
- **J2**: through-hole type A, right angle, the hole pattern shared by Molex
  67643, Stewart SS-52100-001, Kycon KUSBX-AS1N and Connfly DS1095. 1
  VBUS_PORT, 2 D-, 3 D+, 4 GND, shell to GND.
- **J3**: 2x5, pin 9 absent (key). 1 and 2 VBUS_PORT, 3 D-, 5 D+, 7 and 8
  GND; 4, 6 (a second port's data) and 10 (over-current sense on a PC) not
  connected. A PC slot bracket's first socket works, its second has power
  only. A 1x4 cable fits the odd row.
- **J4** (SWD): SWCLK (P2.10), GND, SWDIO (P2.6), placed clear of every
  other connector.
- **J5**: RUN (P2.11), GND, BOOTSEL (P2.5). RUN to GND resets the card; with
  BOOTSEL held to GND the RP2350 starts its USB bootloader. The module's FPC
  adapter has both as buttons.

## Mechanical

- Plain rectangle, no nose, bracketless, two layers, 1.6 mm FR-4.
  155.5 x 65.92 mm including the 7.62 mm tongue; the body is 58.3 mm above
  the shoulder, the low-profile PC card envelope.
- Edge connector: 2 x 50 gold fingers at 2.54 mm, orientation and geometry
  in `../EDGE_CONNECTOR.md`. ENIG with a 0.5 x 45 degree bevel on the
  finger edge is recommended; HASL works. The finger area is one open
  solder-mask window by design. JLC's Economic PCBA offers no gold fingers:
  ENIG without the bevel there, or Standard PCBA for hard-gold bevelled
  fingers.
- All parts go on the component side. The pin 1 / 2 end faces the rear panel
  on the Denise; the RJ45 and the USB-A socket go to that end. Tall parts
  sit high on the card, away from the fingers, to clear an accelerator; the
  15 mm band above the fingers holds only lying axial parts and the solder
  jumpers.
- Heights above the PCB: M1 about 17.8 mm (2.54 mm header plastic + 1.6 mm
  PCB + 13.61 mm jack; the header plastic cannot be left out, the W5500 sits
  on the module's underside); U1 on its header plastic (parts on its
  underside); U2 lying down.
- **The tall parts do not clear a neighbouring card.** Free height to the
  next card's PCB is 13.6 mm on the Denise and 18.7 mm in an A2000, before
  that card's solder-side leads. M1 needs the adjacent slot on its side
  empty in every machine.

| Target | Body height | Length | Slot pitch |
|---|---|---|---|
| Enterlogic A-NIC outline | 45.1 | 155.5 | - |
| Denise, low-profile PC card envelope | 58.3 max | about 168 | 15.24 |
| Denise, full-height PC card envelope | 100.6 max | about 171 over the board | 15.24 |
| A2000 and the Zorro II form factor | 114.5 max | 337.19 max | 20.32 |

On the Denise the card's shoulder rests 13.97 mm above the motherboard
(EDAC 745-100-520-206, notched ends), and the card goes into the slot next
to the CPU (CN4). Mini-ITX guarantees only 57 mm of free height over that
slot, which is a 43.0 mm body; the One TH relies on the case for the rest.

## First power-up

1. Before soldering the module: confirm the edge connector's orientation
   against `../EDGE_CONNECTOR.md` on the bare board (pins 2 and 4 are GND,
   pin 6 is +5 V; they sit at the rear/bracket end). Then, with the strips
   soldered and nothing else fitted, check for shorts between +5 V, 3V3
   and GND.
2. On the bench, not in the Amiga: build `hello` as a UF2 (`make fw-uf2
   BIN=hello` at the top of the repository), hold BOOTSEL (J5, or the FPC
   adapter's button) while the module powers up from its FPC adapter, and
   copy `firmware/hello.uf2` onto the USB drive that appears. Its USB CDC
   log shows the chip's stepping and MAC. D1 keeps this bench power off
   the bus pins.
3. First time in the Amiga: `bus-listen` the same way (`make fw-uf2
   BIN=bus-listen`, `firmware/bus-listen.uf2`). It drives nothing on the
   bus and prints the bus pins and the /AS statistics once a second on the
   USB CDC log, so a wrong finger shows up before anything is driven.
4. Then the card's firmware: `make fw-uf2`, drop
   `firmware/picozorro-install.uf2` the same way (or `make fw-install` with
   an SWD probe; `docs/UPDATE.md`), and `pztest` on the Amiga finds the
   card and exercises its scratch register.

## Open points

- U2 / U201 temperature at the full 3V3_AUX load (0.59 W at most, TO-220 or
  SOT-223 on the 3V3_AUX copper area). The ME6217 with M1 and an SD card on
  it applies only to a board without U2 (JP2 bridged): 40 C at most with M1
  alone, and by its data sheet not a sound default.
- The 3V3_AUX rise from U2 / U201 against the module's 3V3 and the Amiga's
  +5 V ramp. Measured only for the bare module: 18.6 us.
- The hot-plug droop figures (Power, Bulk) are a simulation with assumed
  cable, rail and electrolytic ESR values, not a measurement.
- JLC build: U201's loop with R6 + C401 next to C6 and the W5500 module's
  own ceramics (to be checked with a scope on the first board); the port
  droop with the MLCC banks at hot-plug; the CPL rotations (corrections of
  kicad-jlcpcb-tools, to be checked in JLC's DFM preview); the 3V3_AUX rise
  from U201 against the module's 3V3.
- Q101: an MMBT3904 in place of the simulated 2N3904 (a PMBT3904 model was
  among those simulated).
- /LDS: the firmware ignoring /LDS is tested on a Denise (register test,
  network, USB and Autoconfig after a reset unchanged), but not yet with
  the pin physically unconnected.
- Q1 on the bus: the NPN driver is simulated only. The firmware's
  `int-nfet` drive was run against a 2N7002 MOSFET, not an NPN transistor.
- GY-PCM5102: no maker document. Pin order confirmed from the silkscreen;
  the geometry is a third party's footprint that agrees with photo
  measurements to about 0.2 mm, not a measurement on a board.
- F1: the footprint is that of another radial PTC family; any PTC close to
  the rating fits those holes.
- microSD breakout: no maker document. Pin order, 3V3 end, socket overhang,
  board size and socket width are measured; the position of the row and of
  the socket along their edges (socket centred) is assumed; the lines of its
  four pull-ups are unknown.
- Whether R9 / R11 are fitted on the B0 module (expected: yes, so GPIO47
  has a 10 k pull-up and reaches P2.3).
- B2000 pull-ups are from drawing 312726 rev 2 only; the Denise's own /INT
  pull-ups are not measured.
- The free space next to CN4 on the Denise with an accelerator fitted (the
  TF536), at the height where the modules sit. Denise positions were
  measured on a board render; the PC envelope figures are PCI Express (CEM
  3.0 Fig 9-26); A3000 / A4000 limits beyond the form factor are not
  checked; Commodore gives no component-height limits.
- The release time of /INT against Exec clearing INTREQ after the server
  chain is not measured.
- Firmware for microSD and I2S does not exist yet.

## Sources

- Core2350B schematic: https://files.waveshare.com/wiki/Core2350B0/Core2350B.pdf
- WIZ850io: https://docs.wiznet.io/Product/ioModule/WIZ850io
- USR-ES1 manual (copy): https://iarduino.ru/lib/273f9e795d4abeaeecb3b027cae523ba.pdf
- HR961160C jack: https://wmsc.lcsc.com/wmsc/upload/file/pdf/v2/lcsc/2410122008_HANRUN-Zhongshan-HanRun-Elec-HR961160C_C55683.pdf
- ME6217: https://www.lcsc.com/product-detail/C427602.html
- 2N3904: https://www.onsemi.com/pdf/datasheet/2n3903-d.pdf
- BC547: https://www.onsemi.com/pdf/datasheet/bc546-d.pdf
- 2N7000 (why not): https://www.onsemi.com/download/data-sheet/pdf/nds7002a-d.pdf
- 1N5817: https://www.onsemi.com/download/data-sheet/pdf/1n5817-d.pdf
- Intel, Power Delivery Design Issues for Hi-Speed USB on Motherboards: https://www.usb.org/sites/default/files/power_delivery_motherboards.pdf
- Intel 815E Platform Design Guide (reference board sheet 21): https://download.intel.com/design/chipsets/designex/29823401.pdf
- RUEF: https://www.littelfuse.com/assetdocs/resettable-ptc-ruef-datasheet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
- MF-R: https://www.bourns.com/docs/Product-Datasheets/mfr.pdf
- LD1117 (DocID2572 Rev 38, Table 6): https://www.st.com/resource/en/datasheet/ld1117.pdf
- AMS1117: http://www.advanced-monolithic.com/pdf/ds1117.pdf
- ME6217 data sheet V02: https://datasheet.lcsc.com/datasheet/pdf/3d38df48f5744f9f5473666520a2674d.pdf
- ME6207 data sheet V04 (SOT-23-5 dissipation, p. 4): https://datasheet.lcsc.com/datasheet/pdf/bd2fb8a7d19717c941ded5ee758d36c9.pdf
- SD Physical Layer Simplified Specification v3.01 (Table 3-4): https://www.cs.utexas.edu/~simon/378/resources/Part_1_Physical_Layer_Simplified_Specification_Ver_3.01_Final_100518.pdf
- LF33: https://www.st.com/resource/en/datasheet/lfxx.pdf
- PCM5102A: https://www.ti.com/lit/ds/symlink/pcm5102a.pdf
- GY-PCM5102 (community drawing): https://macsbug.wordpress.com/2021/02/19/web-radio-of-m5stack-pcm5102a-i2s-dac/
- GY-PCM5102 footprint (third party): https://github.com/sstojos/zynthian-miniature/blob/main/GY-PCM5102.kicad_mod
- SanDisk SD Card Product Manual v1.9: https://www.convict.lu/pdf/ProdManualSDCardv1.9.pdf
- Kingston SDCIT: https://www.kingston.com/datasheets/SDCIT-specsheet-8gb-32gb_us.pdf
- USB-A receptacle (Stewart SS-52100-001): https://belfuse.com/resources/drawings/stewartconnector/dr-stw-ss-52100-001.pdf
- Intel Front Panel I/O Connectivity Design Guide rev 1.1 (copy): https://cdn.hackaday.io/files/1626526958903168/600569-fpio-dg-rev1p1.pdf
- USB 2.0 specification: https://www.usb.org/document-library/usb-20-specification
- Commodore B2000 schematic 312726 rev 2, A500+ service manual, A500/A2000
  Technical Reference Manual (Zorro II form factor: figures A-4 to A-6)
- PCI Express CEM 3.0 Fig 9-26; Mini-ITX Addendum 2.0 Fig 5; EDAC 745
  series ordering guide p. 2

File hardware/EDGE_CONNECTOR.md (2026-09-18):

# Zorro II card edge: orientation and geometry

A mirrored edge connector puts +5 V on signal pins, so this is written down
with its evidence.

## Orientation
Viewed from the **component side with the fingers pointing down**:
- **pin 2 is the rightmost finger, pin 100 the leftmost**; even pins are on
  the component side;
- odd pins are on the solder side, pin 1 directly behind pin 2;
- the right end is the rear/bracket end of the machine (on the Denise: the
  rear I/O end, where Enterlogic's A-NIC card has its RJ45).

Evidence:
1. Commodore A500/A2000 Technical Reference Manual, appendix A, drawing A-5
   "Amiga 2000 Form Factor" (printed rotated on the page): labelled
   COMPONENT SIDE, it shows PIN 2 165.735 mm from the bracket-end edge and
   PIN 100 further away; the bracket end is on the right when the drawing is
   turned upright.
2. The front copper artwork of Enterlogic's A-NIC card: the two rightmost
   component-side fingers tie straight into the ground pour (pins 2, 4 =
   GND) and the third has a decoupling capacitor next to it (pin 6 = +5 V).
   With pin 100 on the right that pattern would be GND, n/c, n/c.

## Geometry (TRM drawing A-5, mm)
- 50 fingers per side, pitch 2.54, row length 49 x 2.54 = 124.46
- tongue width 129.26 +/- 0.1 (so 2.40 from tongue edge to first/last finger centre)
- tongue depth 7.62; 1.5 x 45 deg corner chamfers; 0.5 x 45 deg edge bevel
- shoulder radius R1.5
- finger width: the drawing shows 1.6; the footprint uses 1.65 mm from the
  mating-board drawing of the TE 2-5530843-2 connector (.065 +/- .002 in),
  and a 1.6 mm board (the EDAC 745 series accepts 1.37 to 1.78 mm). Sources
  and the full dimension table: `lib/README.md`.

## Card outline
Enterlogic's A-NIC, a mini-Zorro card known to fit the Denise, is 155.5 x
54.3 mm, bracketless, with its I/O at the right (rear) end. The PicoZorro
One TH keeps the 155.5 mm length and the I/O end; its body is taller
(58.3 mm above the shoulder, 65.92 mm with the tongue).

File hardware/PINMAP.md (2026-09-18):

# PicoZorro pin map

One GPIO map is shared by the firmware and the boards:
`firmware/pz-core/src/pins.rs` and `firmware/pz-hal/src/chip.rs` hold the
numbers and must match this file. The PicoZorro One TH follows it except on
four pins (GPIO18, 44, 46, 47), listed in the last section.

Rules behind the map:
- 5 V bus signals only on GPIO0-39 (5 V tolerant). GPIO40-47 are 3.3 V only.
- One PIO block sees 32 pins, window base 0 or 16. GPIO16-31 is visible to
  both windows, so strobes and register-select address bits live there.
- D0-15 + strobes + A1-A7 are contiguous from GPIO0, so block A captures the
  whole cycle with one `in pins, 27`.
- A16-A23 + /CFGIN are contiguous, so block B matches the address (and the
  "my turn in the config chain" condition) with one 9-bit compare.
- XRDY sits in the shared window (GPIO27) so block A can observe it.

| GPIO | RP2350B pin | Signal | Zorro pin | Dir | Notes |
|---|---|---|---|---|---|
| 0-15 | 77-80, 1-4, 6-9, 11-14 | D0-D15 | 75,77,79,81,83,86,84,82,80,78,76,71,69,67,65,63 | I/O | driven only in own read cycles |
| 16 | 16 | /AS | 74 | in | |
| 17 | 17 | /UDS | 72 | in | |
| 18 | 18 | /LDS | 70 | in | One TH: microSD chip select |
| 19 | 19 | READ | 68 | in | high = read |
| 20-26 | 20-23, 25-27 | A1-A7 | 29,27,26,24,21,23,28 | in | register select |
| 27 | 28 | XRDY | 18 | OD out | open drain by direction switching, value 0 |
| 28-35 | 36-40, 42-44 | A16-A23 | 45,47,52,54,56,58,57,59 | in | base address compare |
| 36 | 45 | /CFGIN | 12 | in | 9th compare bit |
| 37 | 46 | /CFGOUT | 11 | out | push-pull |
| 38 | 47 | /BUSRST | 94 | in | reset input (not pin 53) |
| 39 | 48 | NIC_INT / LED | - | in | W5500 INTn (push-pull, active low); the Core2350B's LED1 is on the same pin |
| 40 | 49 | NIC_MISO | - | in | SPI1 RX |
| 41 | 52 | NIC_CS | - | out | SPI1 CSn |
| 42 | 53 | NIC_SCK | - | out | SPI1 SCK |
| 43 | 54 | NIC_MOSI | - | out | SPI1 TX |
| 44 | 55 | /ARM | - | out | One TH: I2S data |
| 45 | 56 | /INT | 19 or 22 | out | through a driver only: GPIO45 is not 5 V tolerant. One TH: NPN transistor, high asserts, /INT2 or /INT6 by jumper |
| 46 | 57 | UART0_TX | - | out | debug log, TX only, function F11. One TH: I2S bit clock |
| 47 | 58 | - | - | - | on the Core2350B B1 / B2 the module's PSRAM /CS: never drive it. One TH: I2S word clock (B0 module only) |

Not connected on the card: /OVR, /DTACK, /SLAVE, /OWN, /BR, /BG, /BGACK,
/GBG, FC0-2, E, /VPA, /VMA, /BERR, /HLT, /RST (53), A8-A15, 7M, CDAC, /C1,
/C3, -5 V, -12 V, +12 V. Pin 91 tied to GND (required of Zorro II cards).

## PicoZorro One TH

Four pins differ from the map above
(`picozorro-one-th/README.md` has the board's full table):

| GPIO | Module pin | Shared map | PicoZorro One TH |
|---|---|---|---|
| 18 | P3.6 | /LDS | microSD chip select |
| 44 | P4.15 | /ARM | I2S data (DIN) |
| 46 | P2.4 | UART0 TX | I2S bit clock (BCK) |
| 47 | P2.3 | not connected (PSRAM chip select on B1 / B2 modules) | I2S word clock (LCK), B0 module only |

/LDS is not connected on the One TH. The firmware decides word and byte
access on /UDS alone on every board, so an even-byte write is taken as a word
write. There is no UART: debug is SWD with RTT. XRDY comes straight from
GPIO27, /INT goes through an NPN transistor on GPIO45, W5500 INTn is on
GPIO39. GPIO18 / 44 / 46 / 47 are driven only by a firmware built for this
board.

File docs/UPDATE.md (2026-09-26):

# Firmware updates from the Amiga

The card's firmware is updated from the Amiga, with no cable to a PC: the
module's flash holds two image slots (A/B), `pzflash` writes the new image
into the slot that is not running, and the RP2350's bootrom runs it on trial
until `pzflash` confirms it. An image that is not confirmed is dropped by
the bootrom, and the card boots the old one again.

## In short

On the PC (firmware toolchain, see `firmware/README.md`):

    make fw-pzf                  # firmware/picozorro.pzf

On the Amiga, with the `.pzf` copied over:

    pzflash INFO                 # running version, slot, trial state
    pzflash UPDATE picozorro.pzf # FLASH, ACTIVATE, CONFIRM in one go

`pzflash` is built in `amiga/pzflash` (`make -C amiga`). The module must
have been installed partitioned once (below); `pzflash INFO` says "not
partitioned (no updates)" otherwise.

## How it works

- Flash: an A/B pair of 2 MiB partitions (`firmware/pt.json`: A at 64 KiB,
  B at 2112 KiB), the partition table in sector 0 (made by `picotool
  partition create`). The bootrom maps the booted partition to 0x10000000
  (RP2350 datasheet 5.1.19), so one image runs from either slot;
  `firmware/pz-app/memory.x` limits the image to 2 MiB.
- The module runs from one slot and writes the update into the other,
  with the bootrom's low-level flash functions (storage offsets,
  datasheet 5.4.8.10/11) from a RAM function, interrupts off. The first
  sector (the IMAGE_DEF) is written last, after the rest is in flash and
  the stream's CRC-32 matched; then the whole image is read back through
  the untranslated XIP window (0x1c000000, datasheet 4.4) and its CRC-32
  compared. A partial image never carries a block the bootrom would pick.
- ACTIVATE: `reboot(REBOOT_TYPE_FLASH_UPDATE, .., XIP_BASE + start of the
  new slot)` (datasheet 5.4.8.24; the pico-examples OTA example passes
  the address the same way). The new image carries the try-before-you-buy
  flag (set by `tools/mkpzf.py` in its IMAGE_TYPE item, picobin.h
  `PICOBIN_IMAGE_TYPE_EXE_TBYB_BITS`), so the bootrom runs it on trial
  under the watchdog (datasheet 5.1.17).
- On trial the image says so (STATUS.BUY_PENDING, from `get_sys_info`
  BOOT_INFO, pico-sdk `BOOT_TBYB_AND_UPDATE_FLAG_BUY_PENDING`) and keeps
  the watchdog fed for 120 s. CONFIRM calls `explicit_buy` (datasheet
  5.4.8.4): the bootrom clears the flag and erases the first sector of the
  old slot, so the new image stays. No CONFIRM: the watchdog fires, the
  bootrom prefers the non-TBYB old image, and the module is back where it
  was.
- Across the update reboot the new image keeps the Autoconfig base: the
  old one leaves it in watchdog SCRATCH0/1 (the bootrom uses SCRATCH2-7
  for reboot parameters), the new one starts configured there, so the
  Amiga can talk to it without a reset. The bus build does this only when
  /BUSRST is high at boot and the stash is there; any other boot waits
  for /BUSRST. If the Amiga cannot reach the card after the reboot,
  reboot the Amiga for a fresh Autoconfig.

## First install and recovery

The A/B layout is written once from a PC. Without a probe, as a UF2 file:

    make fw-uf2                  # firmware/picozorro-install.uf2

Hold BOOTSEL while plugging the module's USB into the PC: the RP2350's ROM
bootloader shows up as a USB drive. Copy `picozorro-install.uf2` onto it.
The file writes the partition table at flash offset 0, the image (TBYB
off) into partition A and erases the first sector of B. Its blocks carry
the UF2 family `absolute`, which the bootrom writes at the addresses in the
file whatever the flash held before (datasheet 5.1.18, 5.5.3;
`firmware/pt.json` allows `absolute` downloads in the unpartitioned space,
so this also works on a module that is already partitioned). The bootrom
reboots when the copy is complete and the module starts from A. After that
every update goes through `pzflash`.

With an SWD probe, `make fw-install` (`tools/pz_install.sh`, probe-rs)
writes the same three pieces. The SWD route is the one in use; the UF2
route has not been exercised on a module yet.

`probe-rs run <elf>` (`make fw-run`) and `picotool load <elf>` (`make
fw-load`) write a flat image at offset 0 and so remove the partition table;
the install UF2 or `make fw-install` put table and image back.

A plain UF2 (`make fw-uf2 BIN=hello`, family `rp2350-arm-s`) dropped on a
partitioned module does not land at offset 0: the bootrom stores it in the
A/B partition that would not be chosen at the next boot (datasheet 5.5.3,
5.5.3.1), boots it with a flash update boot, and, as the image carries no
TBYB flag, erases the first sector of the other partition (datasheet
5.1.16). The partition table stays and the dropped image replaces the
running one; a `picozorro` image dropped that way still takes updates from
`pzflash`.

Recovery when no image runs: the RP2350's ROM bootloader is always there.
Hold BOOTSEL while the module powers up and drop `picozorro-install.uf2`
again (or `make fw-install` over SWD). RP2350 chips of stepping A2 (`hello`
prints the stepping) have erratum RP2350-E10: their bootrom does not set up
the flash before it reads the partition table, and UF2 drops onto a
partitioned module can fail. A module without a partition table (new, or
flashed flat) is not affected; on an A2 a partitioned module is reinstalled
over SWD.

## Registers ($C0-$FE of the A16 = 1 window)

Model: `pz_core::update` (host tests). General rules as `docs/REGISTERS.md`
(16-bit, big-endian, byte access refused).

| Offset | Name | Access | Meaning |
|---|---|---|---|
| $C0 | UPD_CTRL | W | command: 1 BEGIN, 2 ABORT, 3 COMMIT, 4 ACTIVATE, 5 CONFIRM, 6 BOOTROM_OFF, 7 BOOTROM_ON |
| $C2 | UPD_STATUS | R | state and flags, below |
| $C4, $C6 | UPD_SIZE | RW | image length in bytes, high word first; set before BEGIN |
| $C8, $CA | UPD_CRC | RW | CRC-32 (zlib) of the image; set before BEGIN / COMMIT |
| $CC | UPD_DATA | W | data port, word k = bytes 2k, 2k+1; an odd last byte on D15-D8 |
| $D0, $D2 | UPD_DONE | R | bytes in flash so far |
| $D4, $D6 | UPD_RESULT | R | CRC-32 of the image as read back from flash |
| $D8 | UPD_SLOT_KB | R | size of a slot in KiB (0: not partitioned) |
| $DA | UPD_ERROR | R | error code when the state is error |
| $E0-$EE | FW_VERSION | R | running firmware, 16 ASCII bytes, NUL-padded |

UPD_STATUS: bits 3-0 state (0 idle, 1 receiving, 2 verifying, 3 ready,
4 rebooting, 5 error); bit 4 SPACE (the data port takes the next 4 KiB
sector); bit 5 BUSY (a command is being carried out: wait until clear);
bit 6 REFUSED (a write was refused since the last BEGIN); bit 8 SLOT_B
(running from B); bit 9 BUY_PENDING (on trial: CONFIRM keeps this image);
bit 10 PARTITIONED (an A/B pair exists: updates possible); bit 11 BOOTROM
(the card's boot ROM is on).

UPD_ERROR: 1 not partitioned, 2 bad size, 3 flash (read-back CRC wrong),
4 CRC mismatch (stream), 5 sequence (command not allowed now), 6 not an
image (no IMAGE_DEF in the first sector), 7 confirm failed, 8 short.

Sequence (what `pzflash` does): SIZE, CRC, BEGIN, wait !BUSY; per 4 KiB
sector: wait SPACE, write the sector's words to DATA; COMMIT, wait !BUSY,
state ready and RESULT = CRC; ACTIVATE, wait for the module to answer
again (FW_VERSION changes, BUY_PENDING set); CONFIRM, wait !BUSY.

SPACE is lock-step on purpose: the next sector only after the last one is
in flash. While the module erases and programs, core 0 has its interrupts
off; over the UART backplane the module's UART loses bytes then, so only
idempotent STATUS polls may fall into that window (they are retried). On
the bus it costs nothing measurable.

## Files and tools

- `.pzf` (`tools/mkpzf.py`): 64-byte header (magic `PZF1`, length, CRC-32,
  flags, the version string found after the image's `PZVERSN:` tag), then
  the image with the TBYB flag set. `make fw-pzf` builds one.
- `pzflash` (Amiga, `amiga/pzflash`): `pzflash [BP [baud [unit [device]]]]
  INFO | FLASH <file> | ACTIVATE | CONFIRM | UPDATE <file> | BOOTROM
  ON|OFF`. Without BP it uses the card on the bus (FindConfigDev, board
  base + $10000); with BP the same registers over the UART backplane. It
  checks the file's CRC before touching the module. BOOTROM switches the
  card's boot ROM, from the next Amiga reset.
- Version string: `PZ_VERSION` at build time, else `<crate version>-<git
  short hash>` (`firmware/pz-app/build.rs`).

## Core 1 and flash

During an erase or program XIP is off, and a flash access from core 1
bus-faults (datasheet 5.4.8.9). embassy-rp's `Flash` avoids that by
pausing core 1 (`flash.rs` `in_ram` -> `pause_core1`), which would stop the
bus slave; so the update path uses the bootrom functions itself and core 1
keeps running. For that, core 1's bus loop must stay in RAM:

- pz-core's bus-path functions and the Autoconfig ROM table are placed in
  `.data.zbus` on the target (`cfg_attr(... link_section)`), so the
  configured fast path stays off XIP even where the inliner keeps a
  function out of line.
- The reset path (Amiga reset or Autoconfig shut-up during an update)
  takes a handshake (`zbus::flash_exclusive` on core 0, `enter_flash_path`
  on core 1): core 1 waits while a flash write is on. The update task
  handles a pending command (an Amiga reset turns into ABORT) before it
  starts another sector.

## Status

The update path is tested over the UART backplane, from a PC and from
FS-UAE. Not verified on the Zorro bus yet: `pzflash` without BP, core 1
serving the bus while core 0 writes flash, an Amiga reset during an
update, and the new image resuming at the stashed base after the update
reboot. Signed images and rollback versions in OTP are not used.

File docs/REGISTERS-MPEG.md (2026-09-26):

# PicoZorro MPEG audio registers, version 1

The contract between the firmware's MPEG decoder and PicoZorro's
`mpega.library`. Implemented and host-tested in `pz_core::mpeg`
(`make fw-test`, Miri clean), served by `picozorro --features mpeg` and
driven by `amiga/mpega.library`; decoding is bit-exact end to end over
the UART link.

## What it does

The Amiga library does what the original mpega.library does on the 68k:
- file or hook I/O;
- ID3 skipping and header / Xing parsing for `MPEGA_STREAM`;
- seek arithmetic and time keeping.

It streams the compressed bytes into the card. The card decodes them with
minimp3 (MPEG-1/2/2.5, layers I, II, III) and hands back **one record per
frame**: the frame's header and its PCM. Output shaping happens on the
card, not the 68k, which cuts register traffic 2 to 4 times:
- rate division (freq_div 2 or 4);
- stereo to mono;
- gain (MPEGA_scale).

One frame per record keeps the original's contract: `MPEGA_decode_frame`
returns exactly one frame, or 0 for a frame that gave no samples.

## Where it sits

- **Window:** offsets $60-$9E of the A16 = 1 window, next to the USB
  registers ($00-$4A, `docs/REGISTERS-USB.md`) and the update registers
  ($C0-$FE, `docs/UPDATE.md`).
- **Access rules:** REGISTERS.md's rules apply. Registers are 16-bit at
  even offsets, big-endian, accessed with `move.w`. A byte access is an
  error (the write is ignored). Unused offsets read $FFFF. Data ports
  carry bytes in memory order.
- **Presence:** MAGIC tells whether the firmware has the decoder.
- **Bus decode:** as the USB window (REGISTERS-USB.md): board base +
  $10000 on the bus, op WINDOW 1 over the UART link.

## Map

| Offset | Name | Access | Meaning |
|---|---|---|---|
| $60 | MAGIC | RO | $4D50 ("MP") |
| $62 | VERSION | RO | $0001 |
| $64 | CTRL | W | command: 1 START, 2 STOP (reads 0) |
| $66 | STATUS | RO | bits 11-8 IN_FREE (free input chunks, 0..8), 7-0 OUT_QUEUED (records, 0..6) |
| $68 | CONFIG | RW | bits 1-0 FREQ_DIV (0: 1, 1: 2, 2: 4), bit 4 MONO; taken at START |
| $6A | SCALE | RW | gain in percent, 1..800 (anything else counts as 100); applies from the next frame decoded (MPEGA_scale) |
| $6C | SESSION | RO | low 16 bits of the session number; every START / STOP / reset opens a new one |
| $70 | IN_LEN | WO | open an input chunk of this many bytes, 0..2048; 0 = end of stream |
| $72 | IN_DATA | WO | input data port |
| $74 | IN_COMMIT | WO | any value: chunk complete |
| $80 | OUT_LEN | RO | bytes in the head record (16 + PCM), 0 = none |
| $82, $84 | OUT_DATA | RO | output data port; both offsets, so `move.l` reads two words |
| $86 | OUT_DONE | WO | any value: drop the head record |
| $90-$9A | STATS | RO | three 32-bit counters, high word first (the high-word read latches the low word) |

## A stream

1. Write CONFIG and SCALE, then CTRL = START.
   - START empties both queues and resets the decoder.
   - Read SESSION after START. A record the firmware finished just as
     START came in can still reach the queue; drop every record whose
     SESSION differs.
2. Feed input chunks while IN_FREE > 0:
   - IN_LEN = n;
   - (n + 1) / 2 words to IN_DATA (the last byte of an odd chunk sits in
     the high byte);
   - IN_COMMIT.

   Start at the first frame header (skip ID3v2 on the Amiga). The
   firmware finds sync by itself after that, but junk costs bus time.
3. After the last byte, a chunk of length 0 marks the end of the stream.
4. Read records while OUT_QUEUED > 0:
   - OUT_LEN, then OUT_LEN / 2 words from OUT_DATA, then OUT_DONE;
   - the record after an END record is the next stream's (none until the
     next START).
5. Seek: CTRL = START again, then feed from the new file position.
6. CTRL = STOP when done: queues empty, decoder idle.

The firmware decodes ahead while it has input and a free output slot.

## Record

A 16-byte header, big-endian words, then the PCM.

| Word | Meaning |
|---|---|
| 0 | FLAGS: bit 15 END (no frame: the input is used up after the end marker), bit 14 LOST (bytes skipped to find sync before this frame) |
| 1 | SAMPLES per channel in this record, after FREQ_DIV (0: the frame gave no samples) |
| 2 | CHANNELS in the PCM, 1 or 2, after MONO |
| 3 | FRAME_BYTES: compressed bytes this frame used |
| 4, 5 | the frame's 4-byte MPEG header as it was in the stream (the library takes norm, layer, mode, bitrate, rate, private / copyright / original from it) |
| 6 | SESSION: the session the record belongs to |
| 7 | reserved, 0 |

**PCM:** planar, as `MPEGA_decode_frame` returns it. First SAMPLES words
of channel 0 (left or mono), then SAMPLES words of channel 1 if CHANNELS
is 2. Signed 16-bit, big-endian.

**When records appear:**
- Every frame the decoder consumes gives a record, so the library can
  count frames for `MPEGA_time` like the original.
- An END record comes once, after the last frame of a stream that got its
  end marker.

## Output shaping (firmware, `pz_core::mpeg::shape`)

- **FREQ_DIV 2 or 4:** each output sample is the mean of 2 or 4 input
  samples. A box filter: cheaper than the original's filterbank, better
  than plain decimation.
- **MONO:** (L + R) / 2.
- **SCALE:** x · scale / 100, saturated to 16 bits.
- **Order:** mono, then rate division, then gain.

## STATS ($90-$9A)

| Offset | Counter |
|---|---|
| $90 | frames: records with samples posted |
| $94 | skipped: records with 0 samples (sync, bit reservoir) |
| $98 | in_errors: input chunks dropped (bad length, queue full, short commit) |

## Sizes

- **Input:** 8 chunks of up to 2048 bytes.
- **Output:** 6 records of up to 16 + 4608 bytes (1152 samples × 2
  channels).
- **Decoder:** minimp3 needs a contiguous buffer. The firmware copies
  chunks into a 16 KiB linear buffer and compacts it as frames are used.

## Not verified

- Real-time playback on the bus: 176 KB/s of PCM at 44.1 kHz stereo,
  against the expected 1-2 MB/s Zorro II path.
- The UART link carries ~15 KB/s, so it tests decoding to a file, not
  playback.

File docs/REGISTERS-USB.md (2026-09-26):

# PicoZorro USB register window, version 1

The contract between the firmware's USB side and `picozorrousb.device`.
Implemented and host-tested in `pz_core::usb` (`make fw-test`). Served by
`picozorro` with the cargo feature `usb-host` (the host engine is
`pz_hal::usb_host`) on the bus, and over the UART link with the
`uart-backplane` feature. Driven by `picozorrousb.device`, backend `pz` on
the bus.

## Where it sits

The second 256-byte window of the 128 KiB board, at A16 = 1 (board base +
$10000; A16 = 0 is `docs/REGISTERS.md`). The
general rules of REGISTERS.md apply unchanged: 16-bit registers at even
offsets, big-endian, `move.w`; byte access is an error (BUS_ERROR, a byte
write is ignored, a byte read has no side effects); unused offsets and
write-only registers read $FFFF; data ports carry bytes in memory order.
Over the UART link the window is chosen per batch with op WINDOW. On the
bus the decode compares A23-A17 once the board is configured and passes
A16 to the firmware with the cycle (`zbus.pio`); before configuration it
compares A23-A16, so the board answers only at $E8xxxx.

## Design: records, not per-slot registers

The window carries transfer records instead of a register block per
transfer slot: a request record (28-byte header + OUT data) goes into a
request queue, a completion record (12-byte header + IN data) comes out of
a completion queue, matched by `seq`. Why: the record is exactly what
Poseidon hands a hardware driver per transfer (device address, endpoint,
type, direction, speed / split routing, max packet size, a setup packet,
a buffer, a NAK timeout), the Amiga driver keeps one code path for every
backend, and the queues are the network window's TX / RX pattern.
Every op goes through the queues: PING, PORT_STATUS, PORT_RESET,
XFER, ABORT, FORGET, RESET_TOGGLE. A streamed bulk IN (request flag
STREAM, below) puts several completion records with one
`seq` into the completion queue, in order, the last one without MORE. A
streamed bulk OUT takes its first record as an XFER and the rest as
XFER_DATA request records with the stream's `seq`, and acknowledges each
written record with a completion record without payload.

## Map (offsets in the A16 = 1 window)

| Offset | Name | Access | Meaning |
|---|---|---|---|
| $00 | MAGIC | RO | $5055 ("PU") |
| $02 | VERSION | RO | $0001 |
| $04 | INT | R, W1C | interrupt status, bits below |
| $06 | INT_ENABLE | RW | same layout as INT |
| $08 | CTRL | W | bit 15 RESET_QUEUES; reads 0 |
| $0A | STATUS | RO | bits below |
| $10 | REQ_LEN | WO | open a request record of this many bytes (28..1052) |
| $12 | REQ_DATA | WO | request data port |
| $14 | REQ_COMMIT | WO | any value: record complete |
| $20 | CPL_LEN | RO | length of the head completion record (12..1036), 0 = queue empty |
| $22 | CPL_DATA | RO | completion data port |
| $24 | CPL_DONE | WO | any value: drop the head completion record |
| $40-$4A | STATS | RO | three 32-bit counters, high word first (snapshot rule of REGISTERS.md) |
| $60-$9E | | | MPEG decoder registers, `docs/REGISTERS-MPEG.md` (when the firmware has the decoder) |
| $C0-$FE | | | firmware update registers, `docs/UPDATE.md` (a separate model, `pz_core::update`, present without a USB model too) |

### INT ($04) and INT_ENABLE ($06)

| Bit | Name | Kind | Set when |
|---|---|---|---|
| 0 | CPL_AVAIL | level | the completion queue is not empty |
| 1 | REQ_FREE | latched | the firmware took a request (a slot came free) |
| 2 | PORT_CHANGE | latched | CONNECTED or LOW_SPEED changed |
| 4 | BUS_ERROR | latched | a rule of this contract was broken |

/INT is shared with the network window: asserted while the board is
configured and either window has (INT & INT_ENABLE) != 0.

### STATUS ($0A)

| Bits | Name | Meaning |
|---|---|---|
| 15 | CONNECTED | a device is on the root port |
| 14 | LOW_SPEED | it is low speed (0 when not connected) |
| 12-8 | REQ_FREE | free request slots, 0..16 |
| 7-0 | CPL_QUEUED | records in the completion queue, 0..16 |

### STATS ($40-$4A)

| Offset | Counter |
|---|---|
| $40 | requests: records committed |
| $44 | completions: records posted |
| $48 | req_errors: request records dropped (bad length, queue full, short commit, REQ_LEN while one is open) |

## Submitting a request

1. REQ_FREE (STATUS) > 0. A driver may keep a credit: the free count it
   last read minus the records it sent since.
2. REQ_LEN = record length. Out of range or no free slot: BUS_ERROR,
   req_errors, nothing opens.
3. ceil(len / 2) words to REQ_DATA (more: BUS_ERROR, ignored).
4. REQ_COMMIT. Fewer words than announced: the record is dropped
   (req_errors).

## Reading completions

Read CPL_LEN; if not 0, ceil(len / 2) words from CPL_DATA, then CPL_DONE
(may come early, the rest is skipped). Completions arrive in any order;
the driver matches them to its requests by `seq` and **ignores a `seq` it
does not know** (a completion racing a queue reset can slip through).
Intended use of /INT: enable CPL_AVAIL; the handler reads records until
CPL_LEN is 0. PORT_CHANGE can replace polling PORT_STATUS for the root
hub's change endpoint.

## Records

All multi-byte fields are big-endian (68000 order). Max data per record:
1024 bytes; the Amiga driver splits longer transfers at multiples of the
endpoint's max packet size and stops early on a short packet.

Request, 28-byte header + `length` bytes of OUT data:

| Off | Size | Field |
|---|---|---|
| 0 | 2 | magic `0x5055` ("PU") |
| 2 | 1 | version, 1 |
| 3 | 1 | op |
| 4 | 2 | seq, echoed in the completion |
| 6 | 1 | device address 0-127 |
| 7 | 1 | endpoint 0-15, bit 7 = IN |
| 8 | 1 | transfer type: 0 control, 1 iso, 2 bulk, 3 interrupt |
| 9 | 1 | flags: bit 0 low speed, bit 1 PRE (low speed behind a full-speed hub), bit 2 no short packet, bit 3 allow runt, bit 4 STREAM (below) |
| 10 | 2 | max packet size |
| 12 | 2 | NAK timeout in ms, 0 = wait until aborted |
| 14 | 2 | length: bytes to transfer (<= 1024); for ABORT the seq to abort |
| 16 | 1 | split hub address (PRE only) |
| 17 | 1 | split hub port (PRE only) |
| 18 | 8 | setup packet (control only); STREAM: bytes 18-21 = total length |
| 26 | 2 | poll interval in ms for interrupt transfers (0 = 1) |

Completion, 12-byte header + `actual` bytes of IN data:

| Off | Size | Field |
|---|---|---|
| 0 | 2 | magic |
| 2 | 1 | version |
| 3 | 1 | op |
| 4 | 2 | seq |
| 6 | 1 | status (below) |
| 7 | 1 | flags: bit 0 MORE, another completion for this request follows (STREAM) |
| 8 | 2 | actual: bytes transferred / payload length |
| 10 | 2 | reserved |

Ops:

| Op | Name | What the firmware does |
|---|---|---|
| 0 | PING | completes with status 0, payload `pzusb` + build info |
| 1 | PORT_STATUS | payload: connected (0/1), speed (0 none, 1 low, 2 full), feature bits (bit 0: STREAM for bulk IN; bit 1: STREAM for bulk OUT; bit 2: the interval field is honoured) |
| 2 | PORT_RESET | bus reset on the root port (drops every cached pipe), then PORT_STATUS payload |
| 3 | XFER | one transfer as described by the header |
| 4 | ABORT | cancels the in-flight request whose seq is in `length`; that request completes with status 15 |
| 5 | FORGET | drops the cached pipes of `device address` (after SET_ADDRESS, after a disconnect) |
| 6 | RESET_TOGGLE | drops the cached pipe of (`device address`, `endpoint`): next transfer starts at DATA0 (after ClearFeature(ENDPOINT_HALT)) |
| 7 | XFER_DATA | the next record of a streamed bulk OUT whose seq is in `seq` (below) |

Status values follow Poseidon's `UHIOERR_*` so the Amiga driver copies
them into `io_Error`: 0 ok, 1 USB offline, 3 host error, 4 stall, 6
timeout (no answer from the device), 7 overflow (more data than asked), 8
CRC / bad response, 10 NAK timeout, 11 bad parameters, 13 babble, 15
aborted. A short IN transfer is status 0 with `actual` < `length`; the
Amiga driver turns that into `UHIOERR_RUNTPACKET` unless allow-runt is set.

Status 6 and status 10 differ: a device that NAKs is there and keeps the
transfer going until its NAK timeout (10); a device that does not answer
at all (gone from its hub port, port disabled or suspended) ends it after
three attempts of the same packet in a row, within a few milliseconds
(6), whatever the NAK timeout, and the shared endpoint is free for the
other transfers again. This holds for every stage of a control transfer,
for bulk in both directions, and for low-speed devices behind a hub. A
stream ends with the record that failed.

### Streamed bulk IN

One request per 1 KiB costs a round trip to the requester per record; on
the bus that round trip (interrupt, driver task, the next request) takes
longer than the transfer itself. With flag STREAM (bulk IN only, when
PORT_STATUS reports the feature) one request covers the whole transfer:
bytes 18-21 hold the total length (32 bits), `length` the size of one
record (a multiple of the max packet size, <= 1024). The firmware reads
record after record and posts each as its own completion with the
request's `seq`; every completion but the last has MORE set. The stream
ends with the completion that completes the total, a short one (the
device sent a short packet), or one with a status other than 0. The NAK
timeout applies to each record. ABORT ends a stream like any request
(last completion: status 15). Completions of one stream arrive in order;
a full completion queue holds the stream back (the device is not asked
for more meanwhile).

### Streamed bulk OUT

The same for writes, when PORT_STATUS reports feature bit 1. The first
request is an XFER to a bulk OUT endpoint with flag STREAM: bytes 18-21
hold the total length, `length` the size of the data this record carries
(a multiple of the max packet size, <= 1024). The rest of the data
follows in XFER_DATA records (op 7) with the same `seq`, address and
endpoint, `length` = the data bytes in the record. Every record but the
last of a stream has the first one's size; the last brings the total.

The firmware writes the records in order and acknowledges each one when
it is on the device: a completion with the stream's `seq`, status 0,
`actual` = bytes written and no payload; every acknowledgement but the
last has MORE. The sender keeps at most two records unacknowledged (the
one being written and one waiting): it sends the first record and one
XFER_DATA, then one XFER_DATA per acknowledgement with MORE. The
completion without MORE ends the stream: status 0 after the last record,
otherwise the error.

- No short packet is sent between records. After the last one a
  zero-length packet goes out only if flag 2 (no short packet) of the
  first request is clear and the total is a multiple of the max packet
  size, as for one record.
- The NAK timeout applies to each record. When the next XFER_DATA does
  not arrive within 5 s the stream ends with status 6.
- ABORT ends a stream like any request (status 15). A root-port event or
  a bus reset ends it with status 15 (1 when the port is disconnected),
  a queue reset of the register window without a completion. After a
  PORT_RESET the stream's last completion follows the PORT_RESET's own,
  once the reset is done (about 60 ms).
- A record that breaks the rules above (size, address, endpoint) ends
  the stream with status 11. So does a sender that runs further ahead
  than two records: the record that has no room is dropped.
- An XFER_DATA whose `seq` has no stream in progress (it was on its way
  when the stream ended) is dropped without a completion; PING counts
  these in `data-dropped`, with the records of the previous case.

### Poll interval

Bytes 26-27 of an interrupt request set the pipe's poll interval in ms,
as the endpoint's bInterval gives it; the firmware clamps it to 1..255
(0 = 1). The request that opens the pipe sets it: an interrupt IN reader
already running for that endpoint, or a cached interrupt OUT pipe, keeps
its first interval. Without PORT_STATUS feature bit 2 the field is
ignored and every interrupt endpoint is polled at 1 ms. The Amiga driver
fills it from Poseidon's `iouh_Interval`.

## Queue reset

CTRL.RESET_QUEUES, /BUSRST and Autoconfig shut-up empty both queues and
void every request the firmware has taken: transfers in flight are
aborted and post no completion. /BUSRST and shut-up also clear
INT_ENABLE and acknowledge the latched bits. STATS survive.

## Sizes

16 request slots and 16 completion slots of 1052 bytes (33 KiB of
RP2350 RAM). 16 = the Amiga driver's in-flight limit (`SLOTS`, one per
waiting interrupt IN endpoint plus control and bulk).

## Not verified

- The 128 KiB decode on a real bus (`zbus.pio`; host tests and the
  RAM check only) and the bus-side cost of the data ports.
- A race of RESET_QUEUES with a completion being posted (one stale record
  can appear; the driver ignores unknown `seq`s). Host tests cover a reset
  between take and post, not the concurrent case.

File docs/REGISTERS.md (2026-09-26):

# PicoZorro register window, version 3 (network)

The contract between the RP2350 firmware (`firmware/pz-core`) and the
Amiga driver (`picozorro.device`). Implemented and host-tested in
`pz_core::nic` / `pz_core::window` (`make fw-test`).

## General

- The window is 256 bytes at the board base assigned by Autoconfig
  (manufacturer 2011, product $5A). The board is 128 KiB (er_Type $C2):
  this window at A16 = 0, the USB / MPEG / update window
  (`docs/REGISTERS-USB.md`) at A16 = 1. A8-A15 are not decoded, so each
  window repeats every 256 bytes across its 64 KiB. Amiga code uses only
  base + $00..$FF and base + $10000..$100FF.
- All registers are 16 bits at even offsets, big-endian as the 68000 sees
  them. Access them with `move.w`. A 68020+ `move.l` to Zorro II space is
  split into two word cycles, high word (lower address) first; that is
  allowed everywhere and is what the order rules below assume.
- **Strobes**: the card looks at /UDS only; /LDS has no effect on any
  board (the One TH does not wire it). /UDS low is a word access, so an
  even-byte access counts as a word access; /UDS high is an odd-byte
  access. No PicoZorro driver issues even-byte accesses; Autoconfig writes
  are /UDS-only.
- **Odd-byte access** on the network registers ($06 and $10-$7E) is an
  error: the write is ignored, the read returns the word without side
  effects, and both set BUS_ERROR. SCRATCH takes an odd-byte write into
  its low byte; an even-byte write to it writes the whole word.
- Unused offsets and write-only registers read $FFFF; writes to unused
  offsets are ignored.
- Data port byte order: word k of a frame carries byte 2k on D15-D8 and
  byte 2k+1 on D7-D0, which is memory order for `move.w (port),(a0)+`. On
  an odd length the last word carries the last byte on D15-D8; its low
  byte is ignored on TX and reads 0 on RX.

## Map

| Offset | Name | Access | Meaning |
|---|---|---|---|
| $00 | MAGIC | RO | $505A ("PZ") |
| $02 | VERSION | RO | $0003: version 2 plus the data alias at $C0-$FE (version 2 reads $0002, version 0 $0001) |
| $04 | SCRATCH | RW | free for tests, byte access allowed (see Strobes) |
| $06 | INT | R, W1C | interrupt status, bits below |
| $08, $0A | BOOT_US | RO | cold start to "slave armed", us, 32 bit |
| $0C, $0E | CYCLES | RO | bus cycles served, 32 bit |
| $10 | INT_ENABLE | RW | same bit layout as INT |
| $12 | CTRL | RW | control, bits below |
| $14 | STATUS | RO | status, bits below |
| $16, $18, $1A | MAC | RO | station address, bytes 0-1, 2-3, 4-5 |
| $20 | TX_LEN | WO | open a TX frame of this many bytes (14..1514, no FCS) |
| $22 | TX_DATA | WO | TX data port |
| $24 | TX_COMMIT | WO | any value: frame complete |
| $30 | RX_LEN | RO | length of the head RX frame, 0 = queue empty |
| $32 | RX_DATA | RO | RX data port |
| $34 | RX_DONE | WO | any value: drop the head RX frame |
| $40-$56 | STATS | RO | six 32-bit counters, table below |
| $60-$76 | MCAST | RW | four multicast addresses, three words each |
| $78 | MCAST_VALID | RW | bits 3-0: entry n is valid (entry n = $60 + 6n) |
| $80 | BOOT_CTRL | WO | 1 = start the boot stream, see Boot ROM and boot stream |
| $82, $84 | BOOT_ADDR | WO | address of the hunk just allocated, 32 bit |
| $86 | BOOT_STAT | RO | bit 15 BUSY: no stream word published yet |
| $88, $8A | BOOT_DATA | RO | the boot stream, one word per read |
| $C0-$FE | DATA | RW | data port alias: a word read anywhere here is an RX_DATA read, a word write a TX_DATA write (VERSION $0003 and later) |

### INT ($06) and INT_ENABLE ($10)

| Bit | Name | Kind | Set when |
|---|---|---|---|
| 0 | RX_AVAIL | level | the RX queue is not empty; writing 1 has no effect |
| 1 | TX_DONE | latched | a committed frame was handed to the NIC (a TX slot came free) |
| 2 | LINK_CHANGE | latched | LINK_UP changed |
| 3 | RX_OVERRUN | latched | a received frame was dropped because the RX queue was full |
| 4 | BUS_ERROR | latched | a rule of this contract was broken (list below) |

Latched bits clear when the driver writes 1 to them. /INT is asserted while
the board is configured and (INT & INT_ENABLE) != 0. The line is level
triggered and shared (/INT2 or /INT6, jumper).

Intended driver sequence: the interrupt server reads INT; if (INT &
enabled) is 0 it returns 0 in D0 (Z set) at once so the next server runs.
Otherwise it clears RX_AVAIL in INT_ENABLE if set, writes the latched bits
it saw back to INT, signals the driver task and returns non-zero. The task
reads frames until RX_LEN is 0, then sets RX_AVAIL in INT_ENABLE again; a
frame that arrived meanwhile raises /INT at once, so none is missed.

### CTRL ($12)

| Bit | Name | Meaning |
|---|---|---|
| 0 | ONLINE | 1: frames are received and sent. 0: RX frames are discarded (not counted), TX_COMMIT drops the frame and counts tx_errors |
| 1 | PROMISC | receive every frame |
| 2 | MULTICAST_ALL | receive every multicast frame |
| 14 | CLEAR_STATS | write 1: all STATS to 0; reads 0 |
| 15 | RESET_FIFOS | write 1: empty both queues, abort an open TX frame; reads 0 |

### STATUS ($14)

| Bits | Name | Meaning |
|---|---|---|
| 15 | LINK_UP | the PHY reports link |
| 14 | SPEED_100 | 100 Mbit/s (else 10) |
| 13 | FULL_DUPLEX | |
| 11-8 | TX_FREE | free TX slots, 0..4 |
| 7-0 | RX_QUEUED | frames in the RX queue, 0..16 |

## Sending a frame

1. Wait for TX_FREE > 0 (STATUS), or for TX_DONE.
2. Write the length to TX_LEN. Out of range (below 14, above 1514) or no
   free slot: BUS_ERROR, nothing opens.
3. Write ceil(len / 2) words to TX_DATA. Extra words are ignored and set
   BUS_ERROR.
4. Write TX_COMMIT. The firmware pads frames shorter than 60 bytes with
   zeros, and the NIC appends the FCS.

A commit with fewer words written than announced drops the frame and
counts tx_errors. TX_LEN while a frame is open drops the open one and
counts tx_errors. TX_DATA or TX_COMMIT without an open frame sets BUS_ERROR.

## Data port alias ($C0-$FE)

From VERSION $0003. Every word offset in $C0-$FE is the data port: a read
behaves exactly as an RX_DATA read, a write exactly as a TX_DATA write
(same frame bookkeeping, same BUS_ERROR rules, byte access is an error).
The alias exists so the driver can move a frame with long and multiple
moves, which only work on ascending addresses:

    movem.l (a1)+,d0-d7      ; 32 bytes from the frame in memory
    movem.l d0-d7,$C0(a0)    ; 16 word writes = 16 TX_DATA writes

    movem.l $C0(a0),d0-d7    ; 16 RX_DATA reads
    movem.l d0-d7,(a1)       ; 32 bytes into memory

A 68020+ splits each long into two word cycles, high word first, so the
word order on the bus is memory order. Measured on a TF536 (68030), a
`movem.l` burst runs back-to-back bus cycles; a word-at-a-time copy from
memory leaves a longer gap after each cycle. Frames are sent and
received in whole words: ceil(len / 2) words, the remainder through
RX_DATA / TX_DATA or the alias, as convenient.

## Receiving a frame

1. Read RX_LEN. 0 means the queue is empty.
2. Read ceil(len / 2) words from RX_DATA. Reads past the end, or with an
   empty queue, return $0000.
3. Write RX_DONE. It may come before all words were read; the rest of the
   frame is skipped. With an empty queue it does nothing.

RX_LEN does not change until RX_DONE. The queue holds 16 frames of up to
1514 bytes; when full, the newest frame is dropped (rx_overrun,
RX_OVERRUN).

Frames delivered: to the station address, broadcast, multicast whose
destination is a valid MCAST entry, every multicast with MULTICAST_ALL,
everything with PROMISC. Filtering is done in the firmware: the W5500's own
MAC filter (Sn_MR.MFEN) blocks all multicast, so the firmware turns it off
whenever PROMISC, MULTICAST_ALL or any MCAST entry is set.

The firmware reads the MCAST words while frames arrive, so the driver
changes an entry only while its MCAST_VALID bit is clear: clear the bit,
write the three words, set the bit.

## STATS ($40-$56)

| Offset | Counter |
|---|---|
| $40 | rx_ok: frames put into the RX queue |
| $44 | tx_ok: frames handed to the NIC |
| $48 | rx_dropped: frames the NIC delivered but the firmware could not take (too long, internal error) |
| $4C | tx_errors: frames dropped on the TX side (short commit, offline, NIC error) |
| $50 | rx_crc: CRC errors, if the NIC reports them (the W5500 datasheet shows no such counter: stays 0 there) |
| $54 | rx_overrun: frames dropped because the RX queue was full |

Each counter is high word at the lower offset. Reading the high word
snapshots the whole counter; the next read of its low word returns the
snapshot's low half, so a `move.l` never tears.

## Boot ROM and boot stream

With a boot ROM, Kickstart loads `picozorro.device`, `picozorrousb.device`
and `mpega.library` from the card at boot. Model: `pz_core::boot`, routed
by `pz_core::window`; stream side: `firmware/pz-app/src/boot_task.rs`;
68k side: `amiga/bootrom/boot.s`; image: `tools/mkboot.py` (`make boot`
writes `firmware/boot.img`, which the firmware embeds at build time,
`PZ_BOOT_IMG` overrides the path). A build without the image has no boot
ROM.

### Autoconfig and ROM mode

The boot ROM is offered when the image has one and it is not switched off
(below). The Autoconfig ROM then reads er_Type $D2 (DIAGVALID, bit 4, on
top of $C2) and er_InitDiagVec $0100; otherwise $C2 and $0000. The
firmware decides at start and again at every /BUSRST, never in between.
$0100 from the board base is window offset 0 through the 256-byte alias.

When the board is configured with the boot ROM offered, it is in **ROM
mode**:

- A read anywhere in the A16 = 0 window returns the ROM word at its
  offset (address & $FF), the whole word whatever the strobes, so a byte
  read finds its byte on the right lane. The registers, $80-$8A included,
  cannot be read. Reads at A16 = 1 are not affected.
- ROM mode ends with the read of the ROM's last word (or of any offset past
  it), with any write to the board in either window, and at /BUSRST or
  shut-up. It comes back at the next configuration.

Kickstart reads the start of the ROM three times, then copies the whole
ROM in ascending order, so its copy ends ROM mode. The drivers write
SCRATCH before they read MAGIC, so a ROM that was not copied does not hide
the registers from them.

### The boot ROM

`amiga/bootrom/boot.s`, at most 256 bytes (the window), an even length,
da_Size equal to that length (`mkboot.py` checks all three). It holds a
DiagArea (da_Config $90 = DAC_WORDWIDE | DAC_CONFIGTIME), a romtag, the
DiagPoint, the loader and the name "PicoZorro boot".

1. Kickstart copies da_Size bytes to RAM and calls DiagPoint (A0 = board
   base, A2 = the copy). DiagPoint adds the copy's address to rt_MatchTag,
   rt_EndSkip, rt_Name, rt_IdString and rt_Init, stores the board base in
   the copy and returns 1, so Kickstart keeps the copy. da_BootPoint points
   at the same `moveq #1,d0 / rts`; Kickstart wants it non-zero.
2. At romboot time Kickstart finds the romtag in the copy and
   InitResidents it. rt_Flags is 0, so InitResident calls rt_Init, the
   loader, with A6 = ExecBase.
3. The loader writes 1 to BOOT_CTRL, waits for BOOT_STAT not BUSY and
   checks the "PB" word. Per module it reads the hunk count; per hunk the
   size and MEMF flags, calls AllocMem and writes the result to BOOT_ADDR
   (`move.l`: $82, then $84). It waits for not BUSY again, then per hunk
   reads the address and the word count and copies that many words from
   BOOT_DATA to the address. It calls CacheClearU (exec V37 and up), reads
   the romtag address and calls InitResident(romtag, 0). A hunk count of 0
   ends the list; rt_Init returns 0.

The 68k side neither parses hunks nor relocates: the firmware does both.
There is no MakeResident: each module's own romtag is initialised with
InitResident, as Kickstart would a resident. The loader gives up on a
timeout (400000 polls of BOOT_STAT), a missing "PB" or an AllocMem that
returns 0 (written to BOOT_ADDR, then it stops). Modules already
initialised stay; hunks already allocated are not freed.

### Registers ($80-$8A)

Served while the board is configured and not in ROM mode. In the
`picozorro` firmware they are there with or without a boot image; without
one BOOT_STAT stays BUSY.

| Offset | Name | Access | Meaning |
|---|---|---|---|
| $80 | BOOT_CTRL | WO | 1 (START): the stream from word 0, the addresses forgotten, a new session. Other values do nothing (but end ROM mode, as any write) |
| $82 | BOOT_ADDR_HI | WO | high word of the next hunk address, latched |
| $84 | BOOT_ADDR_LO | WO | low word: the latched high word and this are the next hunk address, in allocation order; at most 32 per session, more are ignored |
| $86 | BOOT_STAT | RO | bit 15 BUSY: no word published at the read position; bits 14-0 read 0 |
| $88, $8A | BOOT_DATA | RO | the next stream word; a word read moves on by one word. Two offsets so that `move.l` reads two words |

- Write with /UDS high (odd byte): ignored. Odd-byte read of BOOT_DATA:
  the word, without moving on. Neither sets BUS_ERROR.
- BOOT_DATA while BUSY reads $0000 and does not move on: poll BOOT_STAT
  first. BOOT_CTRL and BOOT_ADDR read $FFFF; writes to $86-$8A are ignored.
- A START at any time begins a new session; the old session's addresses
  and stream no longer count (a second boot starts over).
- The stream comes from a 48 KiB buffer in RAM that the boot task on core
  0 fills; it looks for START and new addresses every 200 us.

### Stream format

Big-endian words:

```text
$5042 ("PB")
per module:
  n                         hunk count
  n x (bytes.l, MEMF.l)     the loader AllocMems each and writes the address
                            -- BUSY until all n addresses are in --
  n x (address.l, words.l, words x the hunk's words)
  romtag.l                  address of the module's romtag
0                           no more modules
```

- The firmware publishes "PB" and the first module's header after START;
  once a module's n addresses are in, its hunks, its romtag address and
  the next module's header (or the final 0) together. BUSY is set in
  between: after START and after the addresses.
- address.l repeats the address the loader wrote. The words are the hunk's
  data, relocated: for each RELOC32 entry (target hunk, offset) the
  firmware adds the target hunk's address to the long at that offset. The
  part of a hunk past its data (BSS) is not sent; every hunk's MEMF has
  MEMF_CLEAR, so AllocMem zeroes it.
- MEMF: MEMF_PUBLIC | MEMF_CLEAR, plus MEMF_CHIP or MEMF_FAST from the
  load file's hunk size bits, or its extended flags.
- romtag.l: the address of the romtag's hunk plus its offset there.
  `mkboot.py` takes the $4AFC whose rt_MatchTag is relocated to itself.
- A bad image (relocation outside its hunk, more than 32 hunks, more than
  48 KiB of stream) ends the session; BOOT_STAT stays BUSY and the loader
  times out.

### Boot image

`tools/mkboot.py -o firmware/boot.img boot.bin <modules>` reads the
modules' AmigaOS load files (code, data and BSS hunks; RELOC32,
RELOC32SHORT / DREL32; symbol and debug hunks are skipped) and writes,
big-endian:

```text
"PZB1", modules.w, rom_len.w, rom (rom_len bytes)
per module: hunks.w, romtag_hunk.w, romtag_offset.l
  per hunk: mem_bytes.l, memf.l, data_bytes.l (even), data,
            relocs.l, relocs x (target_hunk.l, offset.l)
```

It refuses a stream over 48 KiB or more than 32 hunks in all. Modules are
streamed in command-line order; `make boot` passes picozorro.device,
picozorrousb.device, mpega.library.

### Switching the boot ROM off

UPD_CTRL BOOTROM_OFF / BOOTROM_ON in the update registers
(`docs/UPDATE.md`; `pzflash BOOTROM OFF|ON`). The setting is kept in flash
and applies from the next /BUSRST; UPD_STATUS bit 11 shows it. Off, the
board configures without DIAGVALID, there is no ROM mode, and the drivers
come from disk.

## Reset

Amiga reset (/BUSRST) and Autoconfig shut-up empty both queues, abort an
open TX frame and clear INT (latched bits), INT_ENABLE, CTRL (offline),
MCAST and MCAST_VALID. STATS, BOOT_US and CYCLES survive; only a firmware
restart clears them.

## MAC address

`52:5a` followed by the low 32 bits of the RP2350 OTP chip ID
(`pz_core::mac`): locally administered, unicast. MAC reads the same
value in every state; there is no way to change it from the Amiga side
(S2_CONFIGINTERFACE with another address is the driver's business).

## Not verified

- Whether the W5500 pads short TX frames itself; the firmware pads anyway.
- Whether the W5500 reports CRC errors at all.

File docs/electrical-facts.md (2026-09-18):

# Electrical facts used by the design (with sources)

Only figures read from the named documents. "NOT FOUND" means the document
is silent; do not fill in.

## RP2350B (datasheet build 2025-07-29, d126e9e; HW design guide Release 3; PCN 28)

| Fact | Value | Where |
|---|---|---|
| 5 V tolerant (FT) pins | GPIO0-39, RUN, SWCLK, SWDIO | Tables 1427-1431, p.1335-1338 |
| NOT 5 V tolerant | GPIO40-47 (ADC), QSPI, USB, XIN/XOUT | same; ADC note p.442/p.1068 |
| FT pin abs max, IOVDD = 3.3 V | -0.5 .. 5.5 V, "IOVDD must be present" | Table 1433 p.1338 |
| FT pin abs max, IOVDD = 0 V | -0.5 .. **3.63 V** | Table 1433 |
| FT VIH operating max | 5.5 V (= abs max, zero margin) | Table 1436 p.1339 |
| VIH / VIL at 3.3 V | 2.0 V / 0.8 V, hysteresis >= 0.2 V | Table 1436 |
| VOH / VOL | >= 2.62 V / <= 0.5 V at the selected 2/4/8/12 mA | Table 1436 |
| Total GPIO source / sink | 100 mA / 100 mA | Table 1436 |
| Pad capacitance, slew numbers, per-pin abs max current | NOT FOUND | |
| Leakage specifically at 5 V | NOT FOUND (IIN <= 1 uA, no test voltage given) | |
| Reset state of GPIO pads | IE=0, ISO=1, pull-down enabled, 4 mA | Table 853 p.787 |
| Erratum E9 (input leakage) | A2 only; fixed in A3 silicon; A4 = production | App. E p.1366, App. C p.1354, PCN 28 |
| Stepping check | CHIP_ID.REVISION: A2=2, A3=3, A4=8; marking `RP2350B0A4` | App. C, 14.4 |
| PIO | 3 blocks x 4 SM, 32 instr/block, 1 instr per clk_sys | 11.2 p.876-879 |
| PIO pin window | 32 pins, GPIOBASE = 0 or 16 only, per block | p.877, p.956 |
| Input synchroniser | 2 clk_sys cycles; per-pin bypass INPUT_SYNC_BYPASS | 11.5.6.3 p.913 |
| Cross-block PIO IRQ flags | visible next cycle, no penalty | p.878 |
| clk_sys max officially supported | 150 MHz (nothing higher documented) | p.13, p.519 |
| Boot time to user code | NOT FOUND (no figure anywhere) | |

Raspberry Pi news post 2025-07-29: "keep IOVDD powered when 5V is applied to
any GPIO pad, otherwise the pad will be damaged."

## Logic parts (TI datasheets, VCC = 3.3 V +/- 0.3 V, -40..85 C)

| Part | Fact | Value |
|---|---|---|
| SN74LVC245A | I/O tolerate 5.5 V; Ioff at VCC = 0, VI/VO = 5.5 V | +/-10 uA max |
| SN74LVC245A | tpd A<->B | 1.5 / 3.8 typ / 6.3 ns |
| SN74LVC245A | ten / tdis (OE) | <= 8.5 / <= 7.5 ns |
| SN74LVC245A | VOH @ -24 mA (3 V) / VOL @ 24 mA | >= 2.2 V / <= 0.55 V |
| SN74LVC245A | "OE should be tied to VCC through a pullup" for Hi-Z at power up | section 8.3 |
| SN74LVC16245A | same family features, Ioff +/-10 uA | |
| SN74LVC1G07 (open drain) | I/O tolerate 5.5 V, Ioff +/-10 uA | |
| SN74LVC1G07 | tpd A->Y | 1.5 / 4.2 ns max |
| SN74LVC1G07 | VOL @ 16 mA / 24 mA (VCC 3 V) | <= 0.4 V / <= 0.55 V |

## Denise load figures (from the Denise schematic)

- XRDY pull-up 470 R to 5 V -> driver sinks 5/470 = 10.6 mA, idles at 5 V.
- /CFGOUT1 pull-down 1 k, receiver SN74LS32 (VIH 2.0 V).

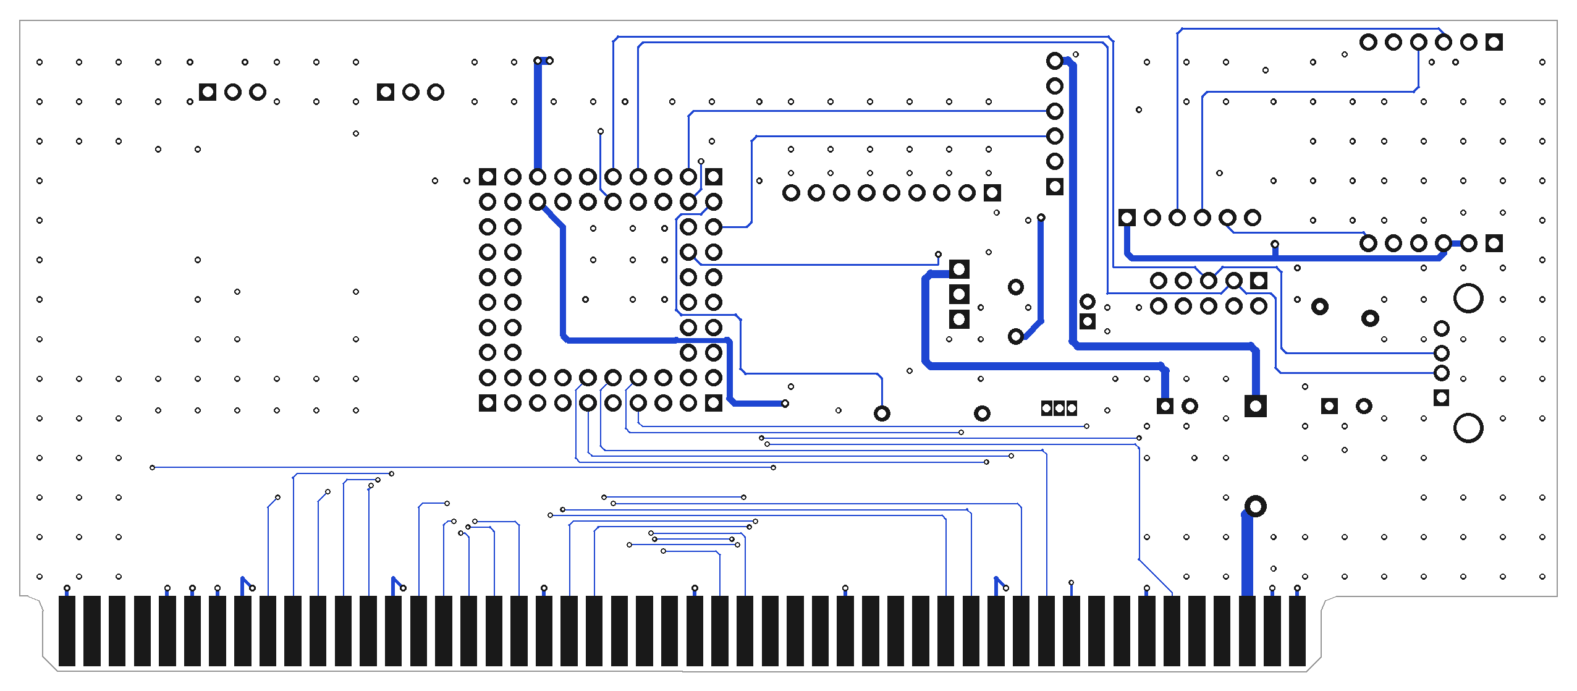
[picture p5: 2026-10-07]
hardware/picozorro-one-th/images/pcb-copper-b.png

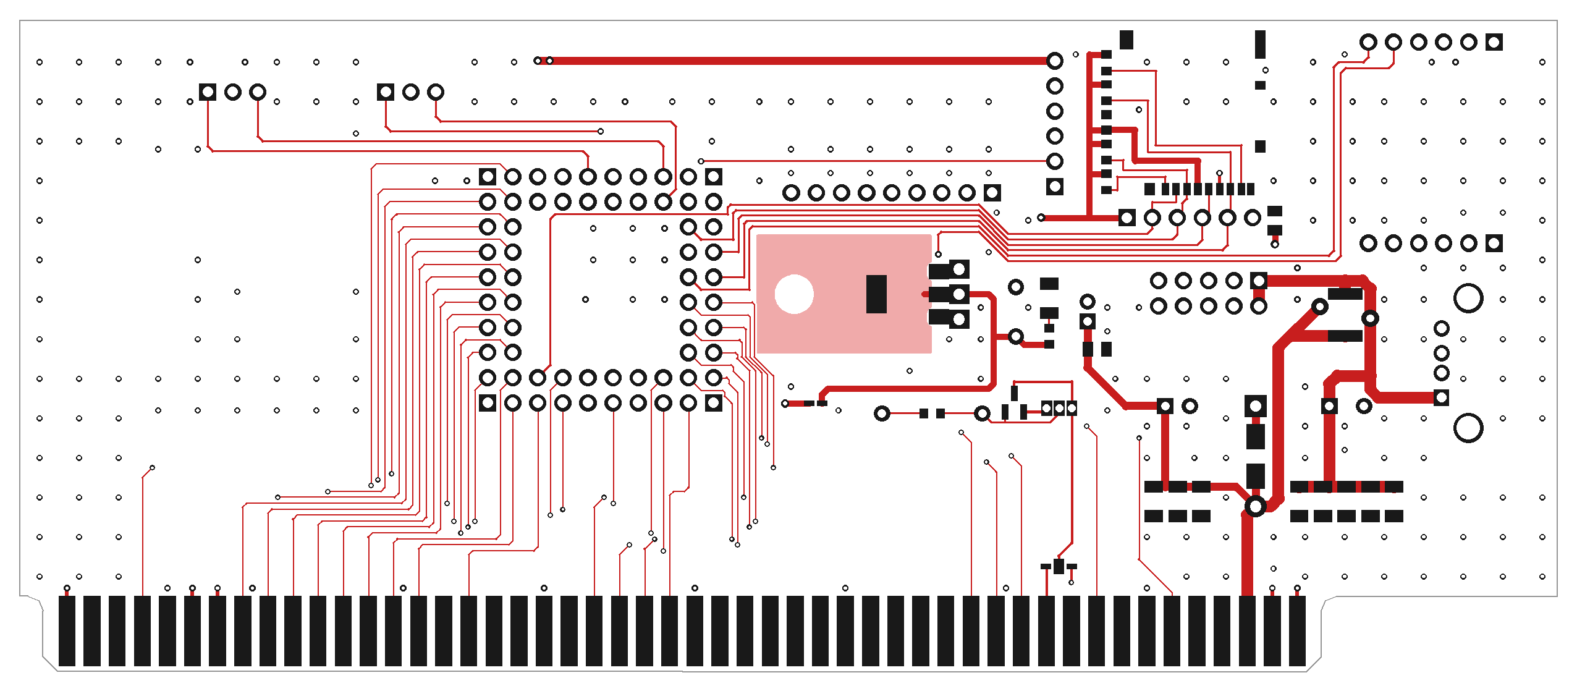
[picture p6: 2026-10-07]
hardware/picozorro-one-th/images/pcb-copper-f.png

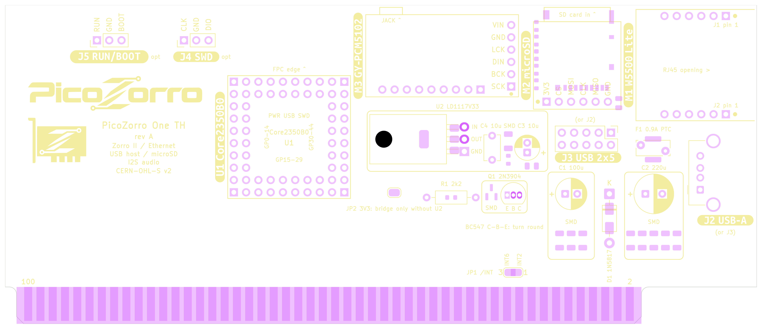
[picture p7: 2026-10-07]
hardware/picozorro-one-th/images/pcb-silk.png

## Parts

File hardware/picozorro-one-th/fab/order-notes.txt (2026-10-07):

PicoZorro One TH rev A - order options
- 2 layers, FR-4, 1.6 mm, 155.5 x 65.92 mm (tongue included)
- edge connector (Zorro II, 2 x 50 fingers at 2.54 mm, hardware/EDGE_CONNECTOR.md): gold fingers,
  0.5 x 45 degree bevel on the finger edge; finish ENIG recommended (README.md, Mechanical), HASL works
- the finger window is one open solder-mask area by design
- vias tented

One board, two builds. Fit one of them, never both parts of a pair (they share the footprint area).

DIY build (no assembly order; parts list picozorro-one-th-parts.csv, the rows without DNP)
  The builder solders everything, all through-hole:
  - D1 1N5817, F1 PTC 0.9 A, C1 100 uF, C2 220 uF, Q1 2N3904, R1 2.2 k
  - U2 LD1117V33 (TO-220, lying, 3V3_AUX regulator), C3 10 uF 25 V electrolytic (U2 input, mind the +),
    C4 10 uF (U2 output)
  - J2 USB-A (or J3, the 2x5 header)
  - U1 Core2350B on P1-P4, M1 W5500 Lite on M1J1 / M1J2; optional M2 microSD breakout, M3 GY-PCM5102 on
    M3J1 / M3J2
  - JP2 stays open (as delivered): U2 supplies 3V3_AUX. Bridge JP2 only on a board without U2 (and never
    with U2 fitted): the module's 3V3 then feeds M1 / M2
  - optional: J4 SWD, J5 RUN/BOOT; JP1 recut for /INT6
  - not fitted: the SMD footprints (D101, R101, F101, C301, Q101, U201, R6, C401, C101-C103, C201-C205, J6,
    R2-R5, C5, C6)

JLC build (PCBA order: jlc/picozorro-one-th-bom-jlc.csv + jlc/picozorro-one-th-cpl-jlc.csv, top side)
  JLC places the SMD set (KiCad variant JLC). Check the part rotations in JLC's DFM preview: the CPL carries
  the corrections of kicad-jlcpcb-tools for SOT-223 (+180) and SOT-23 (-90), none for the others.
  The builder then solders by hand, all through-hole:
  - the modules on their headers: U1 Core2350B (P1-P4), M1 W5500 Lite (M1J1 / M1J2), optional M3 GY-PCM5102
    (M3J1 / M3J2)
  - J2 USB-A (or J3, the 2x5 header)
  - nothing else: JP2 stays open (U201 AMS1117-3.3 with C301 / R6 / C401, fitted by JLC, supplies 3V3_AUX); no M2 (J6 is the microSD socket); the through-hole
    alternates (D1, R1, F1, C1, C2, C3, C4, Q1, U2, M2) stay empty; optional J4 / J5 as in the DIY build
  - Economic PCBA does not offer gold fingers: ENIG without bevel there, or
    Standard PCBA for hard-gold bevelled fingers

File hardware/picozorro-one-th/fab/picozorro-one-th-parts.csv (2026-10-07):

Comment | Designator | Qty | MPN | Manufacturer | Footprint | DNP | LCSC
100u | C1 | 1 |  |  | Capacitor_THT:CP_Radial_D6.3mm_P2.50mm
220u | C2 | 1 |  |  | Capacitor_THT:CP_Radial_D8.0mm_P3.50mm
10u | C3 | 1 |  |  | Capacitor_THT:CP_Radial_D5.0mm_P2.00mm
10u | C4 | 1 |  |  | Capacitor_THT:C_Disc_D5.1mm_W3.2mm_P5.00mm
100n | C5 | 1 | CC0603KRX7R9BB104 | YAGEO | Capacitor_SMD:C_0603_1608Metric | DNP | C14663
10u | C6,C301 | 2 | CL21A106KAYNNNE | Samsung Electro-Mechanics | Capacitor_SMD:C_0805_2012Metric | DNP | C15850
22u | C101,C102,C103,C201,C202,C203,C204,C205,C401 | 9 | CL31A226KAHNNNE | Samsung Electro-Mechanics | Capacitor_SMD:C_1206_3216Metric | DNP | C12891
1N5817 | D1 | 1 | 1N5817 |  | Diode_THT:D_DO-41_SOD81_P10.16mm_Horizontal
SS14 | D101 | 1 | SS14 | MDD (Microdiode Semiconductor) | Diode_SMD:D_SMA | DNP | C2480
PTC 0.9A hold | F1 | 1 | RUEF090 | Littelfuse | Fuse:Fuse_Bourns_MF-RHT070
PTC 1.1A hold | F101 | 1 | 1812L110/33MR | Littelfuse | Fuse:Fuse_1812_4532Metric | DNP | C142747
USB_A | J2 | 1 |  |  | Connector_USB:USB_A_Molex_67643_Horizontal
USB int | J3 | 1 |  |  | Connector_PinHeader_2.54mm:PinHeader_2x05_P2.54mm_Vertical
SWD | J4 | 1 |  |  | Connector_PinHeader_2.54mm:PinHeader_1x03_P2.54mm_Vertical | DNP
RUN/BOOT | J5 | 1 |  |  | Connector_PinHeader_2.54mm:PinHeader_1x03_P2.54mm_Vertical | DNP
DM3AT-SF-PEJM5 | J6 | 1 | DM3AT-SF-PEJM5 | Hirose | Connector_Card:microSD_HC_Hirose_DM3AT-SF-PEJM5 | DNP | C114218
W5500 Lite J1 | M1J1 | 1 |  |  | Connector_PinHeader_2.54mm:PinHeader_1x06_P2.54mm_Vertical
W5500 Lite J2 | M1J2 | 1 |  |  | Connector_PinHeader_2.54mm:PinHeader_1x06_P2.54mm_Vertical
microSD breakout | M2 | 1 |  |  | Connector_PinHeader_2.54mm:PinHeader_1x06_P2.54mm_Vertical
GY-PCM5102 6-pin | M3J1 | 1 |  |  | Connector_PinHeader_2.54mm:PinHeader_1x06_P2.54mm_Vertical
GY-PCM5102 9-pin | M3J2 | 1 |  |  | Connector_PinHeader_2.54mm:PinHeader_1x09_P2.54mm_Vertical
Core2350B P1 | P1 | 1 |  |  | Connector_PinHeader_2.54mm:PinHeader_2x08_P2.54mm_Vertical
Core2350B P2 | P2 | 1 |  |  | Connector_PinHeader_2.54mm:PinHeader_2x08_P2.54mm_Vertical
Core2350B P3 | P3 | 1 |  |  | Connector_PinHeader_2.54mm:PinHeader_2x08_P2.54mm_Vertical
Core2350B P4 | P4 | 1 |  |  | Connector_PinHeader_2.54mm:PinHeader_2x08_P2.54mm_Vertical
2N3904 | Q1 | 1 | 2N3904 |  | Package_TO_SOT_THT:TO-92_Inline
MMBT3904 | Q101 | 1 | MMBT3904 | CJ (Changjiang) | Package_TO_SOT_SMD:SOT-23 | DNP | C20526
2.2k | R1 | 1 |  |  | Resistor_THT:R_Axial_DIN0207_L6.3mm_D2.5mm_P10.16mm_Horizontal
10k | R2,R3,R4,R5 | 4 | 0603WAF1002T5E | UNI-ROYAL | Resistor_SMD:R_0603_1608Metric | DNP | C25804
1R0 | R6 | 1 | 0603WAF100KT5E | UNI-ROYAL | Resistor_SMD:R_0603_1608Metric | DNP | C22936
2.2k | R101 | 1 | 0603WAF2201T5E | UNI-ROYAL | Resistor_SMD:R_0603_1608Metric | DNP | C4190
LD1117V33 | U2 | 1 | LD1117V33 | STMicroelectronics | Package_TO_SOT_THT:TO-220-3_Horizontal_TabDown
AMS1117-3.3 | U201 | 1 | AMS1117-3.3 | Advanced Monolithic Systems | Package_TO_SOT_SMD:SOT-223-3_TabPin2 | DNP | C6186

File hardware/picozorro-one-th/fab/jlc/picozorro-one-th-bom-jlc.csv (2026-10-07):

Comment | Designator | Footprint | LCSC | Qty | MPN | Builder reference | DNP
100n | C5 | C_0603_1608Metric | C14663 | 1 | CC0603KRX7R9BB104 | C5 (JLC build only)
10u | C6,C301 | C_0805_2012Metric | C15850 | 2 | CL21A106KAYNNNE | C6 (JLC build only); C3 (SMD)
22u | C101,C102,C103,C201,C202,C203,C204,C205,C401 | C_1206_3216Metric | C12891 | 9 | CL31A226KAHNNNE | C1 (SMD); C1 (SMD); C1 (SMD); C2 (SMD); C2 (SMD); C2 (SMD); C2 (SMD); C2 (SMD); C401 (JLC build only)
SS14 | D101 | D_SMA | C2480 | 1 | SS14 | D1 (SMD)
PTC 1.1A hold | F101 | Fuse_1812_4532Metric | C142747 | 1 | 1812L110/33MR | F1 (SMD)
DM3AT-SF-PEJM5 | J6 | microSD_HC_Hirose_DM3AT-SF-PEJM5 | C114218 | 1 | DM3AT-SF-PEJM5 | M2 (SMD)
MMBT3904 | Q101 | SOT-23 | C20526 | 1 | MMBT3904 | Q1 (SMD)
10k | R2,R3,R4,R5 | R_0603_1608Metric | C25804 | 4 | 0603WAF1002T5E | R2 (JLC build only); R3 (JLC build only); R4 (JLC build only); R5 (JLC build only)
1R0 | R6 | R_0603_1608Metric | C22936 | 1 | 0603WAF100KT5E | R6 (JLC build only)
2.2k | R101 | R_0603_1608Metric | C4190 | 1 | 0603WAF2201T5E | R1 (SMD)
AMS1117-3.3 | U201 | SOT-223-3_TabPin2 | C6186 | 1 | AMS1117-3.3 | U2 (SMD)
1N5817 | D1 | D_DO-41_SOD81_P10.16mm_Horizontal |  | 1 | 1N5817 | D1 (through-hole, DIY build) | DNP
2.2k | R1 | R_Axial_DIN0207_L6.3mm_D2.5mm_P10.16mm_Horizontal |  | 1 |  | R1 (through-hole, DIY build) | DNP
PTC 0.9A hold | F1 | Fuse_Bourns_MF-RHT070 |  | 1 | RUEF090 | F1 (through-hole, DIY build) | DNP
2N3904 | Q1 | TO-92_Inline |  | 1 | 2N3904 | Q1 (through-hole, DIY build) | DNP
LD1117V33 | U2 | TO-220-3_Horizontal_TabDown |  | 1 | LD1117V33 | U2 (through-hole, DIY build) | DNP
10u | C4 | C_Disc_D5.1mm_W3.2mm_P5.00mm |  | 1 |  | C4 (through-hole, DIY build) | DNP
10u | C3 | CP_Radial_D5.0mm_P2.00mm |  | 1 |  | C3 (through-hole, DIY build) | DNP
100u | C1 | CP_Radial_D6.3mm_P2.50mm |  | 1 |  | C1 (through-hole, DIY build) | DNP
220u | C2 | CP_Radial_D8.0mm_P3.50mm |  | 1 |  | C2 (through-hole, DIY build) | DNP
microSD breakout | M2 | PinHeader_1x06_P2.54mm_Vertical |  | 1 |  | M2 (through-hole, DIY build) | DNP

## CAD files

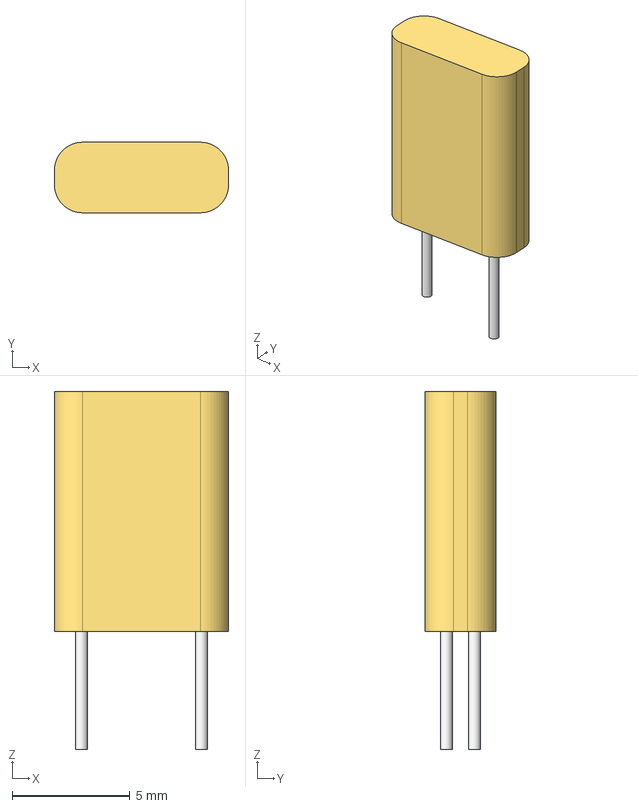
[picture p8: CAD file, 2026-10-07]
hardware/picozorro-one-th/3d/ptc-radial.step
7.40 x 3.00 x 15.2 mm
PTC body
lead x 2

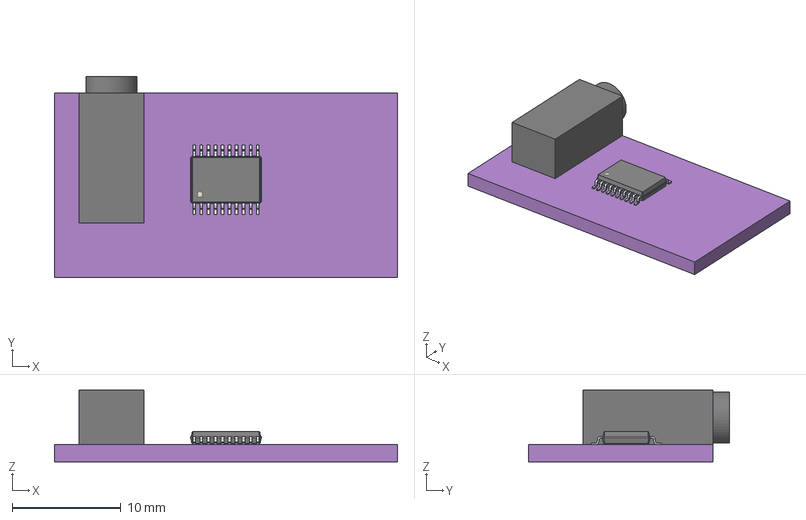
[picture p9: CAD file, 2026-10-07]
hardware/picozorro-one-th/3d/gy-pcm5102.step
31.6 x 18.5 x 6.60 mm
GY-PCM5102 PCB
TSSOP-20_4.4x6.5mm_P0.65mm
3.5 mm jack body
3.5 mm jack barrel

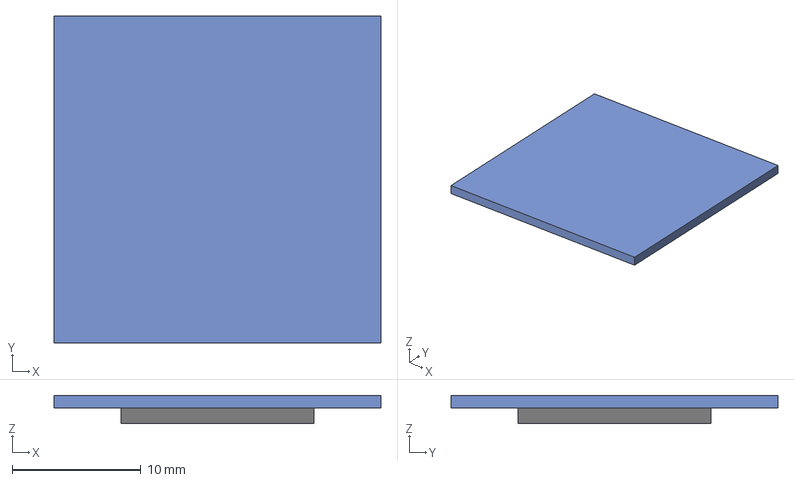
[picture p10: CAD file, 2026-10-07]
hardware/picozorro-one-th/3d/core2350b.step
25.4 x 25.4 x 2.20 mm
Core2350B PCB
parts on the underside

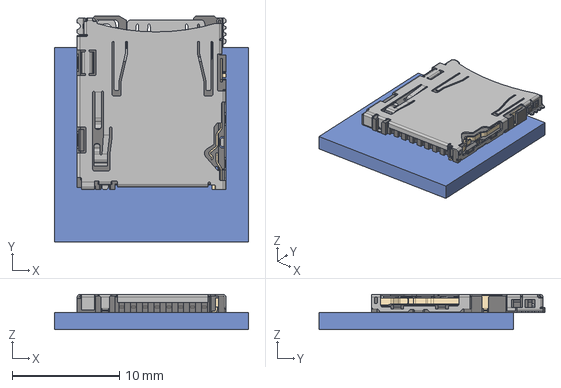
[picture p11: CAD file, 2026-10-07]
hardware/picozorro-one-th/3d/microsd-breakout.step
18.1 x 21.0 x 3.28 mm
microSD breakout PCB
microSD_HC_Hirose_DM3AT-SF-PEJM5

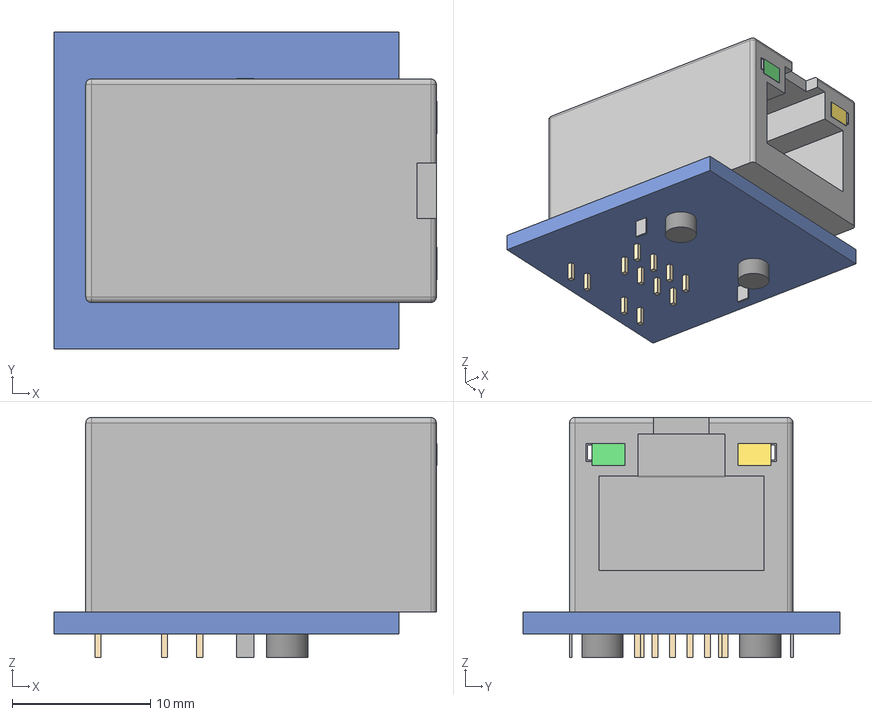
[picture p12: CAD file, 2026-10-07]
hardware/picozorro-one-th/3d/w5500-lite.step
27.8 x 23.0 x 17.4 mm
W5500 Lite PCB
RJ45_Molex_9346520x_Horizontal
LED green
LED yellow

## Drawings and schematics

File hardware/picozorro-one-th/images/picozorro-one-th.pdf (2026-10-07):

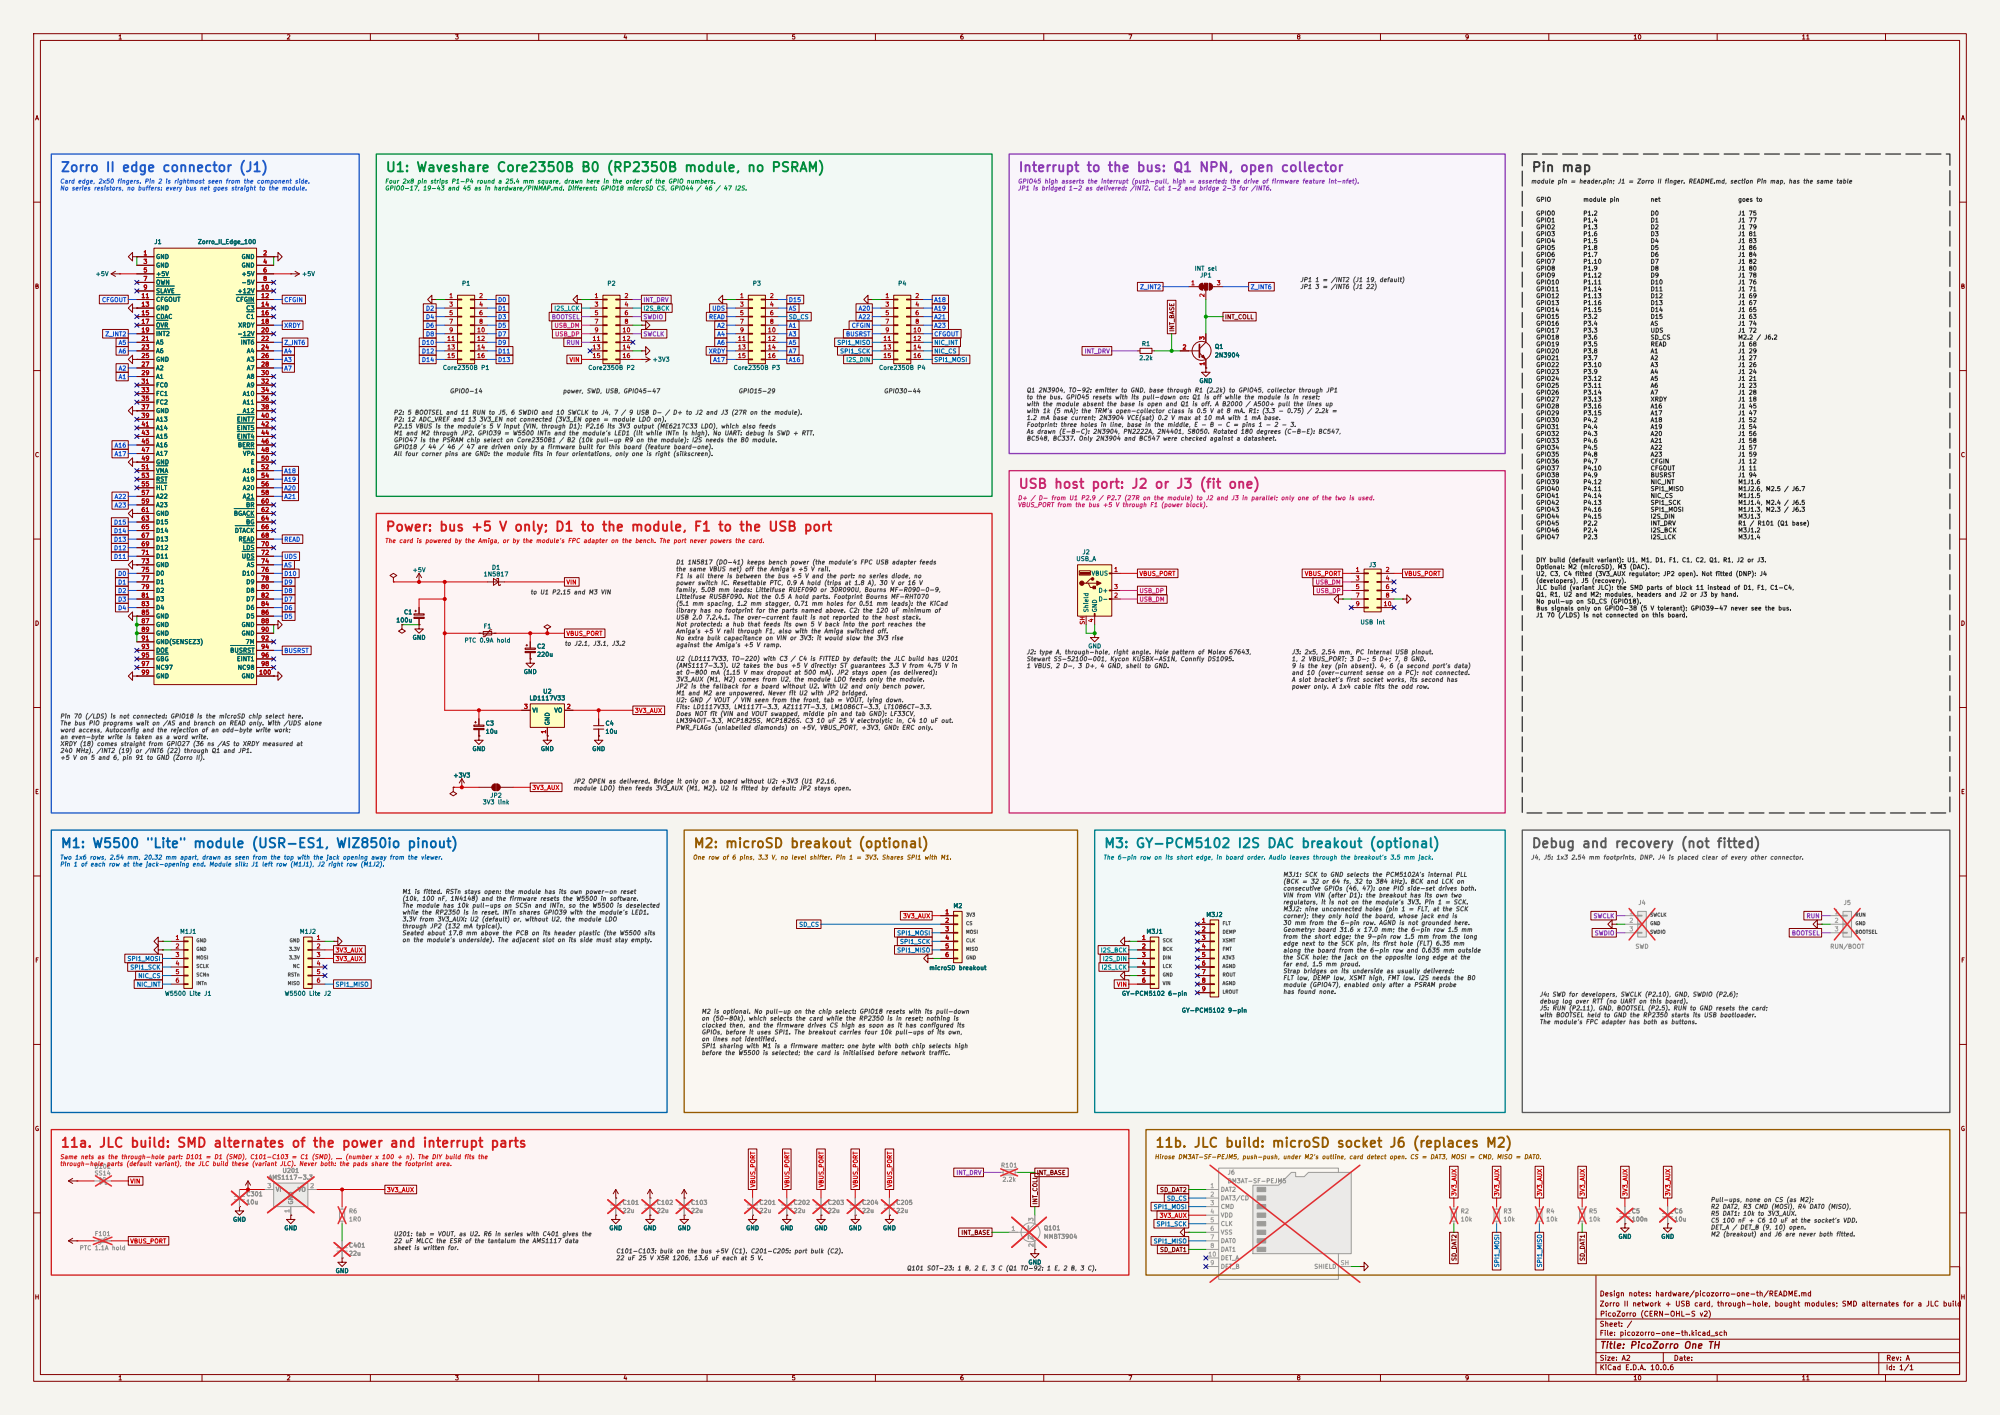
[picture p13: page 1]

Zorro II edge connector (J1)

The card is powered by the Amiga, or by the module's FPC adapter on the bench. The port never powers the card. U1: Waveshare Core2350B B0 (RP2350B module, no PSRAM)

Interrupt to the bus: Q1 NPN, open collector

Card edge, 2x50 fingers. Pin 2 is rightmost seen from the component side. No series resistors, no buffers: every bus net goes straight to the module.

Four 2x8 pin strips P1-P4 round a 25.4 mm square, drawn here in the order of the GPIO numbers. GPIO0-17, 19-43 and 45 as in hardware/PINMAP.md. Different: GPIO18 microSD CS, GPIO44 / 46 / 47 I2S.

BC548, BC337. Only 2N3904 and BC547 were checked against a datasheet. GPIO45 high asserts the interrupt (push-pull, high = asserted: the drive of firmware feature int-nfet). JP1 is bridged 1-2 as delivered: /INT2. Cut 1-2 and bridge 2-3 for /INT6.

module pin = header.pin; J1 = Zorro II finger. README.md, section Pin map, has the same table GPIO

Q1 2N3904, TO-92: emitter to GND, base through R1 (2.2k) to GPIO45, collector through JP1
to the bus. GPIO45 resets with its pull-down on: Q1 is off while the module is in reset; with the module absent the base is open and Q1 is off. A B2000 / A500+ pull the lines up with 1k (5 mA); the TRM's open-collector class is 0.5 V at 8 mA. R1: (3.3 - 0.75) / 2.2k =

P2: 5 BOOTSEL and 11 RUN to J5, 6 SWDIO and 10 SWCLK to J4, 7 / 9 USB D- / D+ to J2 and J3 (27R on the module). P2: 12 ADC_VREF and 13 3V3_EN not connected (3V3_EN open = module LDO on). P2.15 VBUS is the module's 5 V input (VIN, through D1); P2.16 its 3V3 output (ME6217C33 LDO), which also feeds M1 and M2 through JP2. GPIO39 = W5500 INTn and the module's LED1 (lit while INTn is high). No UART: debug is SWD + RTT. GPIO47 is the PSRAM chip select on Core2350B1 / B2 (10k pull-up R9 on the module): I2S needs the B0 module. GPIO18 / 44 / 46 / 47 are driven only by a firmware built for this board (feature board-one). All four corner pins are GND: the module fits in four orientations, only one is right (silkscreen).

1.2 mA base current; 2N3904 VCE(sat) 0.2 V max at 10 mA with 1 mA base. Footprint: three holes in line, base in the middle, E - B - C = pins 1 - 2 - 3. As drawn (E-B-C): 2N3904, PN2222A, 2N4401, S8050. Rotated 180 degrees (C-B-E): BC547,

J2: type A, through-hole, right angle. Hole pattern of Molex 67643, Stewart SS-52100-001, Kycon KUSBX-AS1N, Connfly DS1095. 1 VBUS, 2 D-, 3 D+, 4 GND, shell to GND. D+ / D- from U1 P2.9 / P2.7 (27R on the module) to J2 and J3 in parallel; only one of the two is used. VBUS_PORT from the bus +5 V through F1 (power block).

Power: bus +5 V only; D1 to the module, F1 to the USB port

D1 1N5817 (DO-41) keeps bench power (the module's FPC USB adapter feeds
the same VBUS net) off the Amiga's +5 V rail. F1 is all there is between the bus +5 V and the port: no series diode, no

J4, J5: 1x3 2.54 mm footprints, DNP. J4 is placed clear of every other connector. DIY build (default variant): U1, M1, D1, F1, C1, C2, Q1, R1, J2 or J3. Optional: M2 (microSD), M3 (DAC).

U2, C3, C4 fitted (3V3_AUX regulator; JP2 open). Not fitted (DNP): J4
(developers), J5 (recovery). JLC build (variant JLC): the SMD parts of block 11 instead of D1, F1, C1-C4,

power switch IC. Resettable PTC, 0.9 A hold (trips at 1.8 A), 30 V or 16 V
family, 5.08 mm leads: Littelfuse RUEF090 or 30R090U, Bourns MF-R090-0-9, Littelfuse RUSBF090. Not the 0.5 A hold parts. Footprint Bourns MF-RHT070

Q1, R1, U2 and M2; modules, headers and J2 or J3 by hand. No pull-up on SD_CS (GPIO18). Bus signals only on GPIO0-38 (5 V tolerant); GPIO39-47 never see the bus. J1 70 (/LDS) is not connected on this board.

(5.1 mm spacing, 1.2 mm stagger, 0.71 mm holes for 0.51 mm leads): the KiCad
library has no footprint for the parts named above. C2: the 120 uF minimum of USB 2.0 7.2.4.1. The over-current fault is not reported to the host stack. Not protected: a hub that feeds its own 5 V back into the port reaches the

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

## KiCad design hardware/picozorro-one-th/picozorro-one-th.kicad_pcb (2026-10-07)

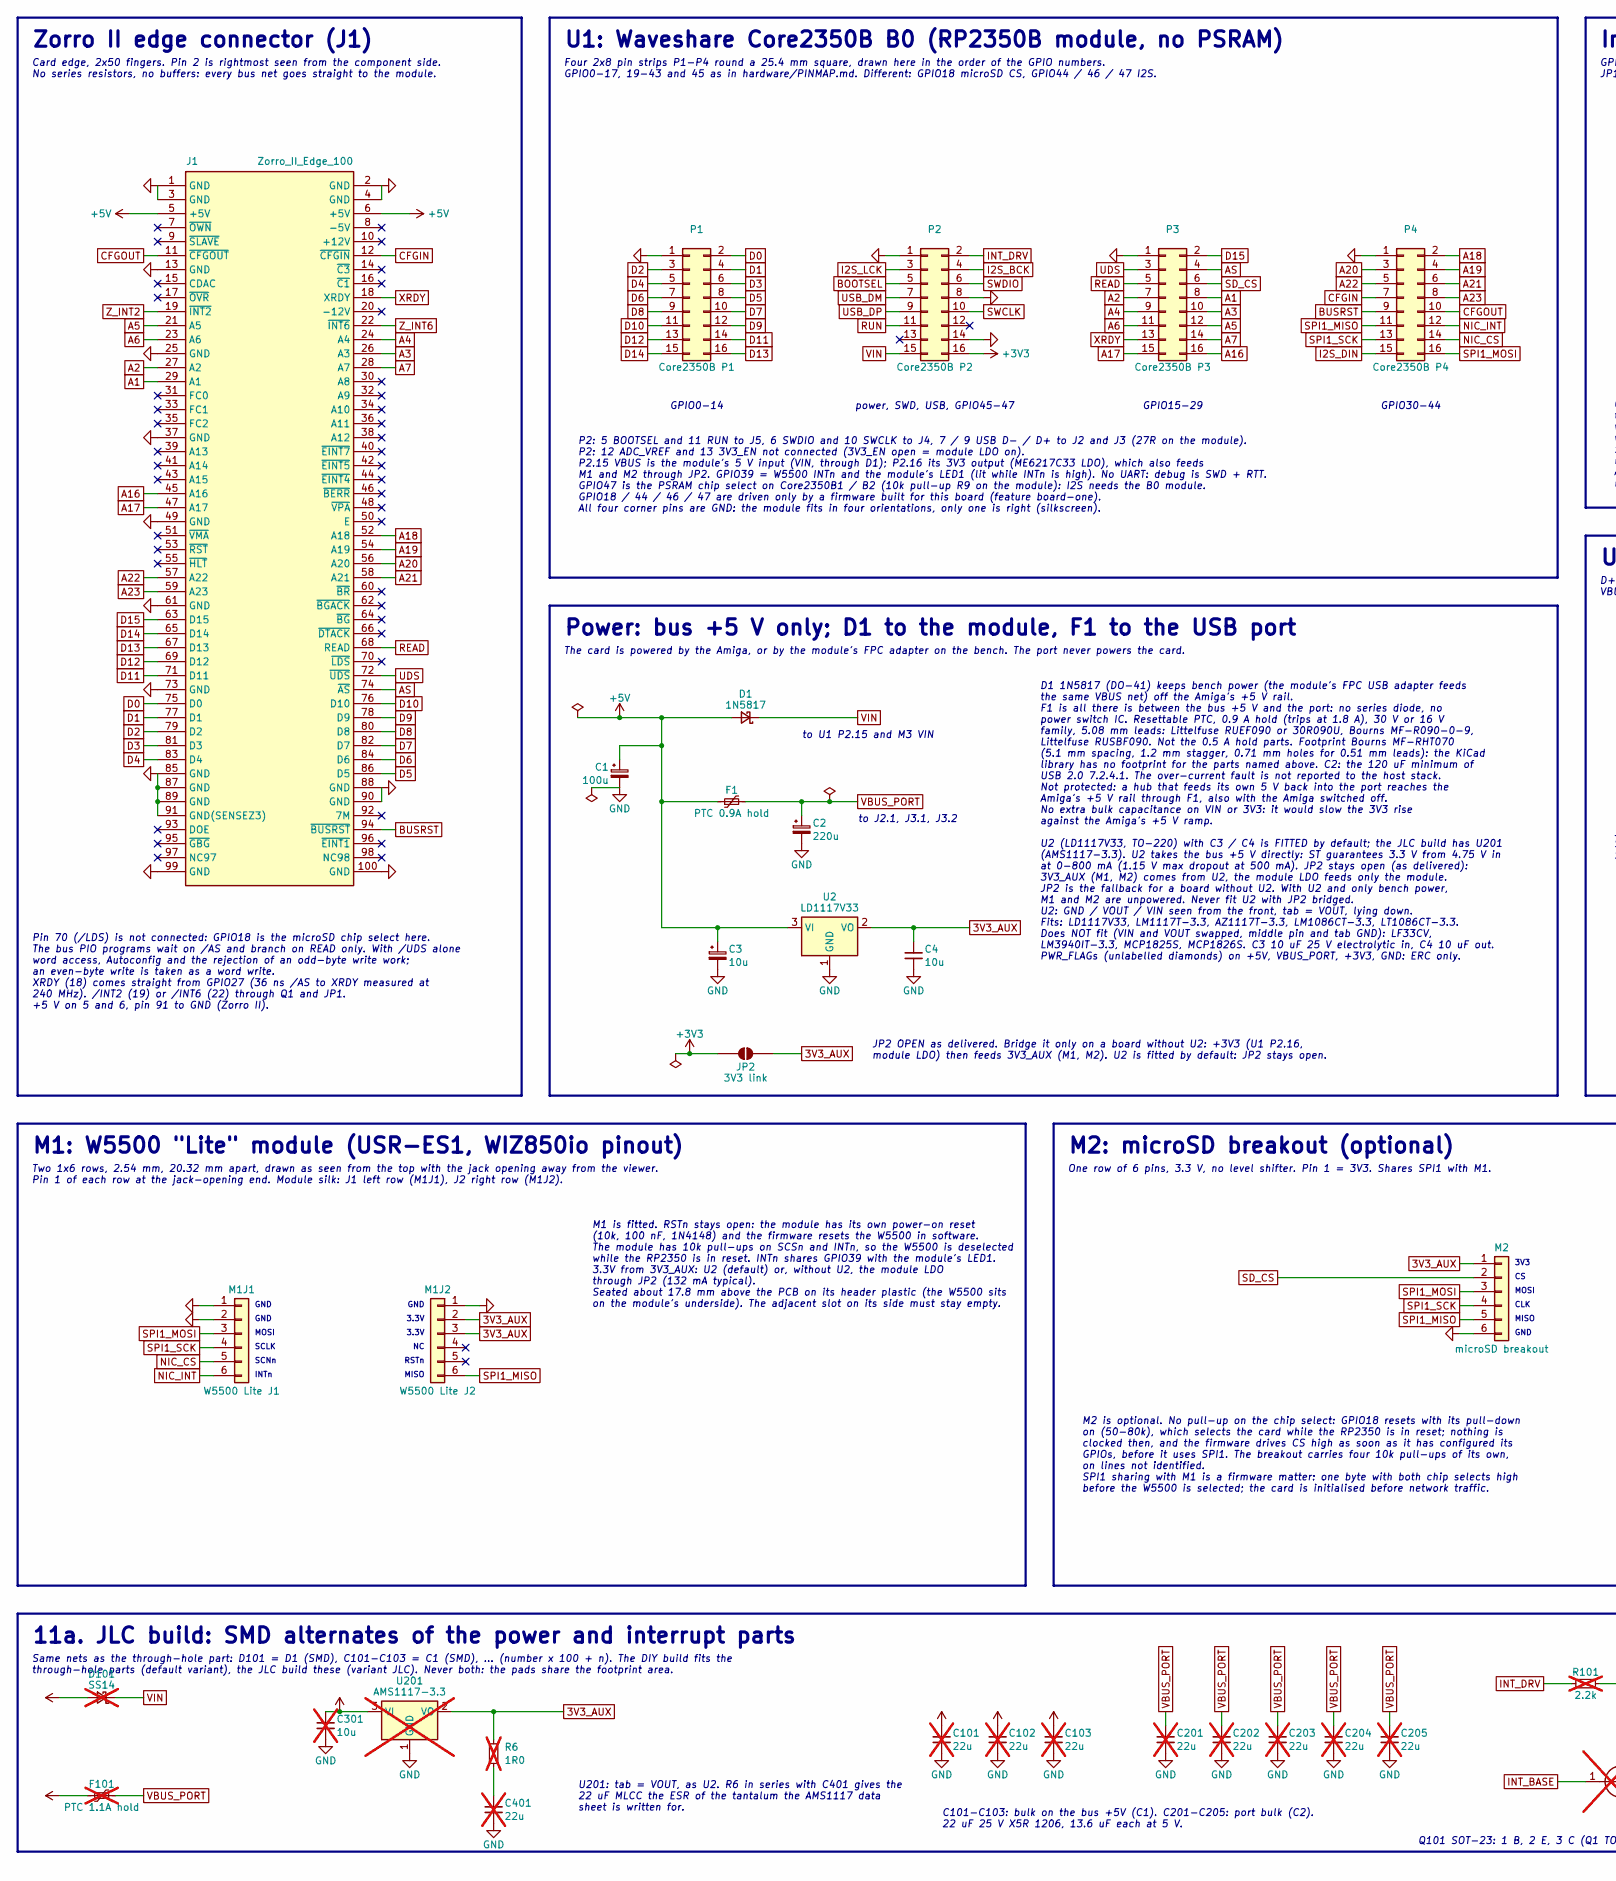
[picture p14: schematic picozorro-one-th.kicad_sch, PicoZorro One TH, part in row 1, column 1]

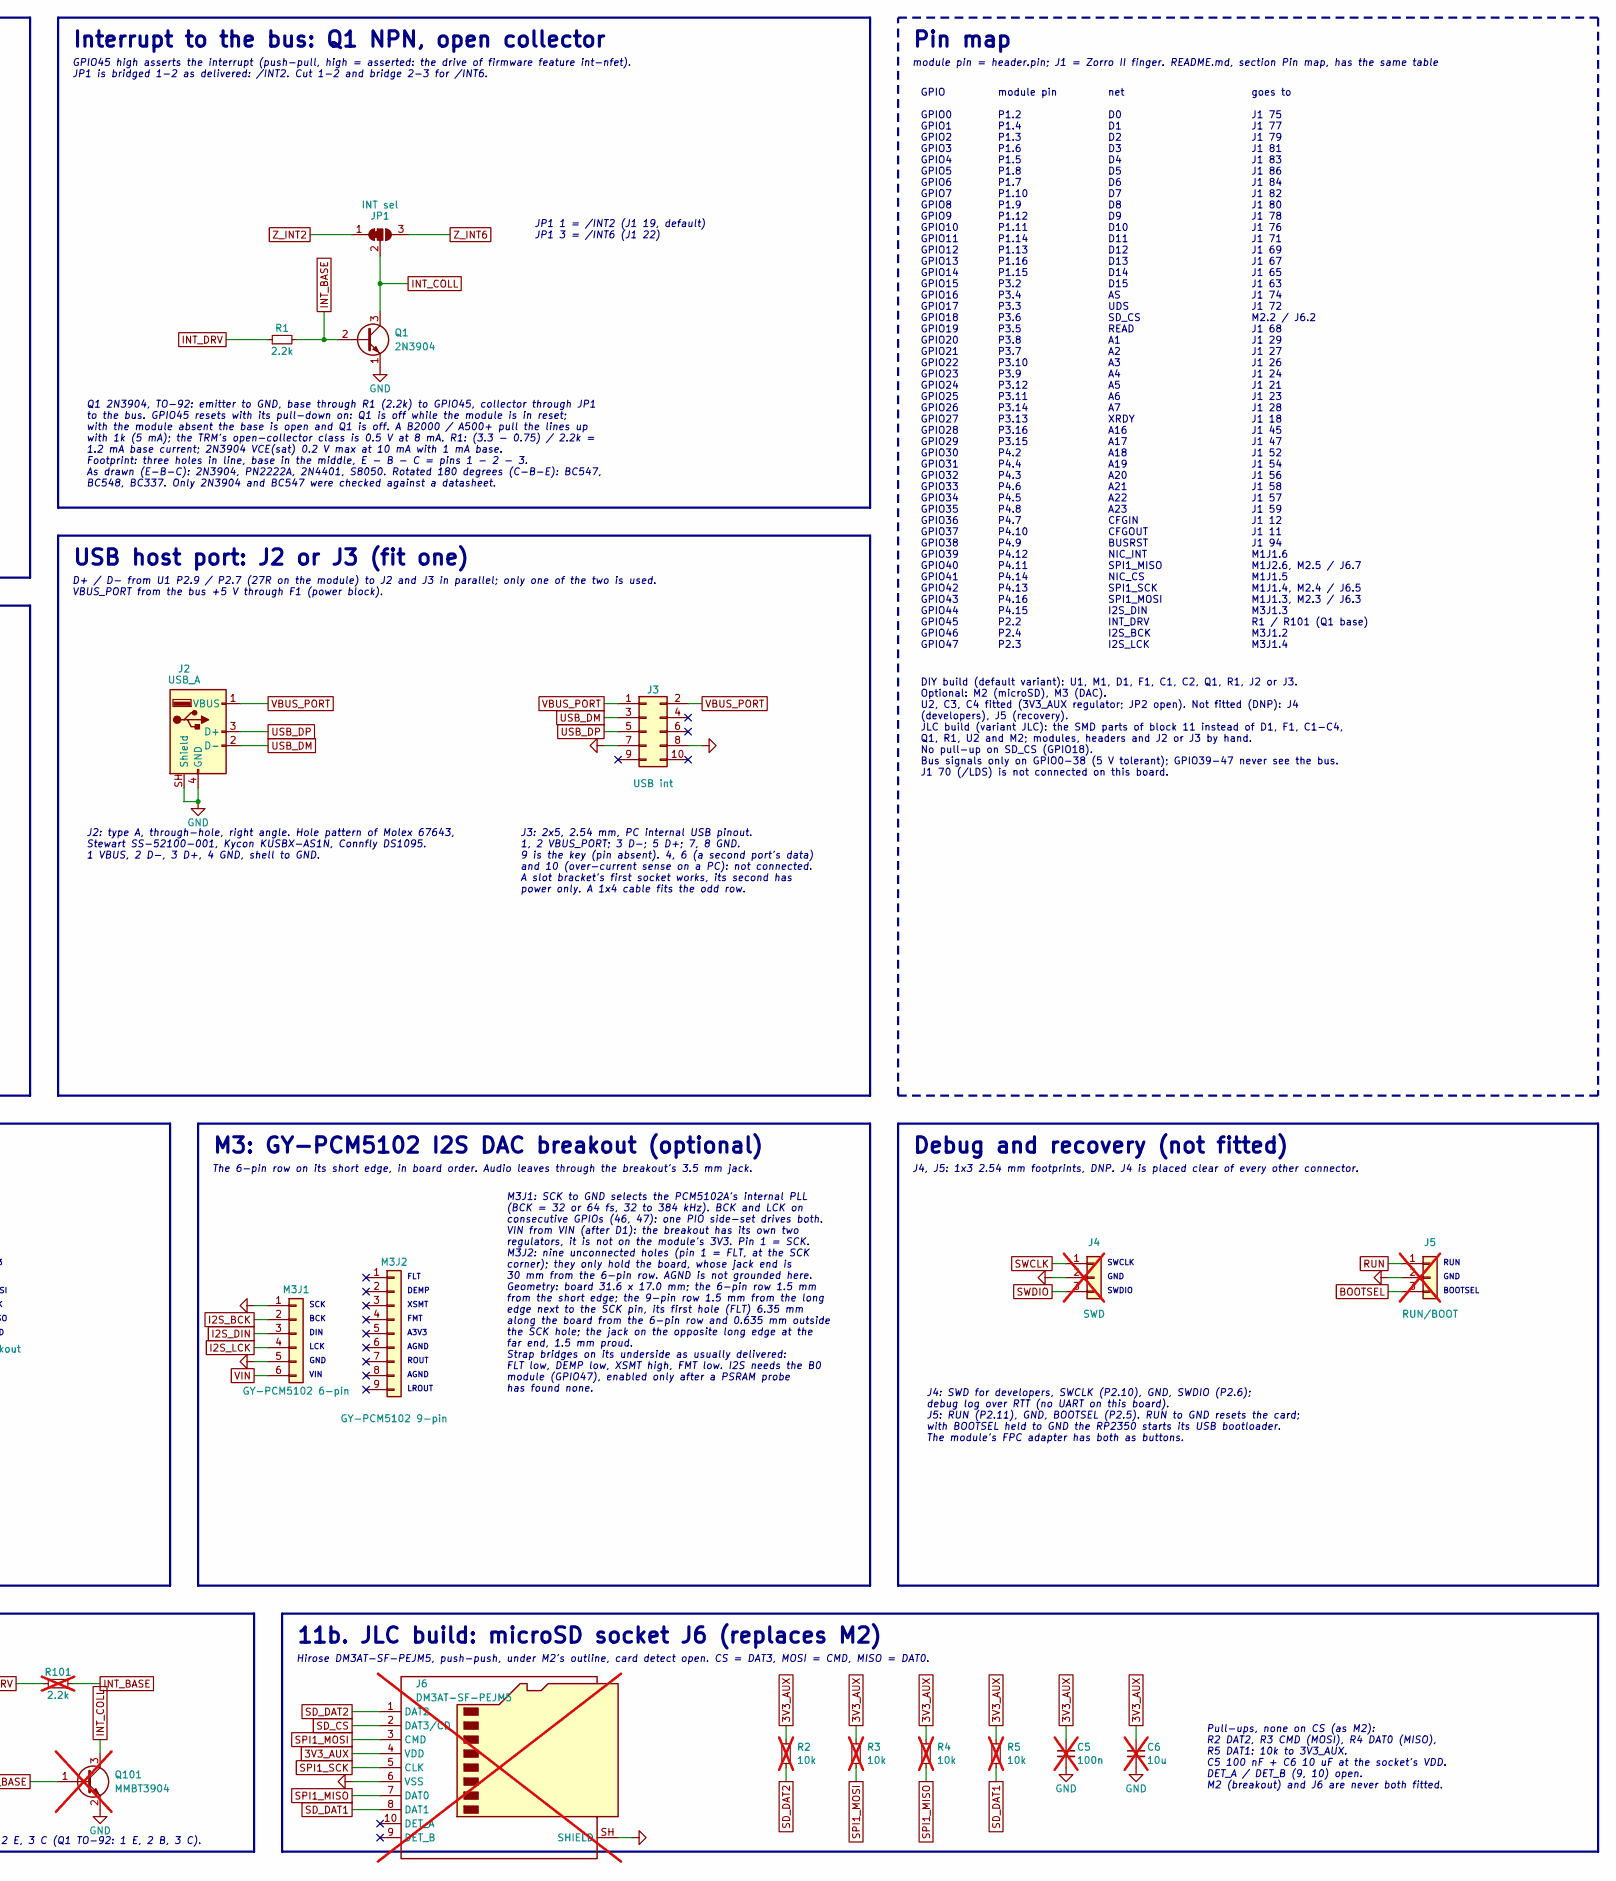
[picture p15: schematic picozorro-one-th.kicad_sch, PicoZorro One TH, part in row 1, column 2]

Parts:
C1: 100u; CP_Radial_D6.3mm_P2.50mm
C2: 220u; CP_Radial_D8.0mm_P3.50mm
C3: 10u; CP_Radial_D5.0mm_P2.00mm
C4: 10u; C_Disc_D5.1mm_W3.2mm_P5.00mm
C5: 100n; C_0603_1608Metric; MPN CC0603KRX7R9BB104; LCSC C14663; not fitted
C6, C301: 10u; C_0805_2012Metric; MPN CL21A106KAYNNNE; LCSC C15850; not fitted
C101, C102, C103, C201, C202, C203, C204, C205, C401: 22u; C_1206_3216Metric; MPN CL31A226KAHNNNE; LCSC C12891; not fitted
D1: 1N5817; D_DO-41_SOD81_P10.16mm_Horizontal; MPN 1N5817
D101: SS14; D_SMA; MPN SS14; LCSC C2480; not fitted
F1: PTC 0.9A hold; Fuse_Bourns_MF-RHT070; MPN RUEF090
F101: PTC 1.1A hold; Fuse_1812_4532Metric; MPN 1812L110/33MR; LCSC C142747; not fitted
J1: Zorro_II_Edge_100
J2: USB_A; USB_A_Molex_67643_Horizontal
J3: USB int; PinHeader_2x05_P2.54mm_Vertical
J4: SWD; PinHeader_1x03_P2.54mm_Vertical; not fitted
J5: RUN/BOOT; PinHeader_1x03_P2.54mm_Vertical; not fitted
J6: DM3AT-SF-PEJM5; microSD_HC_Hirose_DM3AT-SF-PEJM5; MPN DM3AT-SF-PEJM5; LCSC C114218; not fitted
JP1: INT sel; SolderJumper-3_P1.3mm_Bridged12_RoundedPad1.0x1.5mm_NumberL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
JP2: 3V3 link; SolderJumper-2_P1.3mm_Open_RoundedPad1.0x1.5mm
M1J1: W5500 Lite J1; PinHeader_1x06_P2.54mm_Vertical
M1J2: W5500 Lite J2; PinHeader_1x06_P2.54mm_Vertical
M2: microSD breakout; PinHeader_1x06_P2.54mm_Vertical
M3J1: GY-PCM5102 6-pin; PinHeader_1x06_P2.54mm_Vertical
M3J2: GY-PCM5102 9-pin; PinHeader_1x09_P2.54mm_Vertical
P1: Core2350B P1; PinHeader_2x08_P2.54mm_Vertical
P2: Core2350B P2; PinHeader_2x08_P2.54mm_Vertical
P3: Core2350B P3; PinHeader_2x08_P2.54mm_Vertical
P4: Core2350B P4; PinHeader_2x08_P2.54mm_Vertical
Q1: 2N3904; TO-92_Inline; MPN 2N3904
Q101: MMBT3904; SOT-23; MPN MMBT3904; LCSC C20526; not fitted
R1: 2.2k; R_Axial_DIN0207_L6.3mm_D2.5mm_P10.16mm_Horizontal
R2, R3, R4, R5: 10k; R_0603_1608Metric; MPN 0603WAF1002T5E; LCSC C25804; not fitted
R6: 1R0; R_0603_1608Metric; MPN 0603WAF100KT5E; LCSC C22936; not fitted
R101: 2.2k; R_0603_1608Metric; MPN 0603WAF2201T5E; LCSC C4190; not fitted
U2: LD1117V33; TO-220-3_Horizontal_TabDown; MPN LD1117V33
U201: AMS1117-3.3; SOT-223-3_TabPin2; MPN AMS1117-3.3; LCSC C6186; not fitted

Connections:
3V3_AUX: C4.1, C5.1, C6.1, J6.4 (VDD), JP2.2 (B), M1J2.2, M1J2.3, M2.1, R2.1, R3.1, R4.1, R5.1, R6.1, U2.2 (VO), U201.2 (VO)
+3V3: JP2.1 (A), P2.16
+5V: C1.1, C3.1, C101.1, C102.1, C103.1, C301.1, D1.2 (A), D101.2 (A), F1.1, F101.1, J1.5 (+5V), J1.6 (+5V), U2.3 (VI), U201.3 (VI)
A1: J1.29 (A1), P3.8
A2: J1.27 (A2), P3.7
A3: J1.26 (A3), P3.10
A4: J1.24 (A4), P3.9
A5: J1.21 (A5), P3.12
A6: J1.23 (A6), P3.11
A7: J1.28 (A7), P3.14
A16: J1.45 (A16), P3.16
A17: J1.47 (A17), P3.15
A18: J1.52 (A18), P4.2
A19: J1.54 (A19), P4.4
A20: J1.56 (A20), P4.3
A21: J1.58 (A21), P4.6
A22: J1.57 (A22), P4.5
A23: J1.59 (A23), P4.8
AS: J1.74 (~AS), P3.4
BOOTSEL: J5.3, P2.5
BUSRST: J1.94 (~BUSRST), P4.9
CFGIN: J1.12 (~CFGIN), P4.7
CFGOUT: J1.11 (~CFGOUT), P4.10
D0: J1.75 (D0), P1.2
D1: J1.77 (D1), P1.4
D2: J1.79 (D2), P1.3
D3: J1.81 (D3), P1.6
D4: J1.83 (D4), P1.5
D5: J1.86 (D5), P1.8
D6: J1.84 (D6), P1.7
D7: J1.82 (D7), P1.10
D8: J1.80 (D8), P1.9
D9: J1.78 (D9), P1.12
D10: J1.76 (D10), P1.11
D11: J1.71 (D11), P1.14
D12: J1.69 (D12), P1.13
D13: J1.67 (D13), P1.16
D14: J1.65 (D14), P1.15
D15: J1.63 (D15), P3.2
GND: C1.2, C2.2, C3.2, C4.2, C5.2, C6.2, C101.2, C102.2, C103.2, C201.2, C202.2, C203.2, C204.2, C205.2, C301.2, C401.2, J1.1 (GND), J1.2 (GND), J1.3 (GND), J1.4 (GND), J1.13 (GND), J1.25 (GND), J1.37 (GND), J1.49 (GND), J1.61 (GND), J1.73 (GND), J1.85 (GND), J1.87 (GND), J1.88 (GND), J1.89 (GND), J1.90 (GND), J1.91 (GND(SENSEZ3)), J1.99 (GND), J1.100 (GND), J2.4 (GND), J2.SH (Shield), J3.7, J3.8, J4.2, J5.2, J6.6 (VSS), J6.SH (SHIELD), M1J1.1, M1J1.2, M1J2.1, M2.6, M3J1.1, M3J1.5, P1.1, P2.1, P2.8, P2.14, P3.1, P4.1, Q1.1 (E), Q101.2 (E), U2.1 (GND), U201.1 (GND)
I2S_BCK: M3J1.2, P2.4
I2S_DIN: M3J1.3, P4.15
I2S_LCK: M3J1.4, P2.3
INT_BASE: Q1.2 (B), Q101.1 (B), R1.2, R101.2
INT_COLL: JP1.2 (C), Q1.3 (C), Q101.3 (C)
INT_DRV: P2.2, R1.1, R101.1
NIC_CS: M1J1.5, P4.14
NIC_INT: M1J1.6, P4.12
unnamed: C401.1, R6.2
READ: J1.68 (READ), P3.5
RUN: J5.1, P2.11
SD_CS: J6.2 (DAT3/CD), M2.2, P3.6
SD_DAT1: J6.8 (DAT1), R5.2
SD_DAT2: J6.1 (DAT2), R2.2
SPI1_MISO: J6.7 (DAT0), M1J2.6, M2.5, P4.11, R4.2
SPI1_MOSI: J6.3 (CMD), M1J1.3, M2.3, P4.16, R3.2
SPI1_SCK: J6.5 (CLK), M1J1.4, M2.4, P4.13
SWCLK: J4.1, P2.10
SWDIO: J4.3, P2.6
UDS: J1.72 (~UDS), P3.3
USB_DM: J2.2 (D-), J3.3, P2.7
USB_DP: J2.3 (D+), J3.5, P2.9
VBUS_PORT: C2.1, C201.1, C202.1, C203.1, C204.1, C205.1, F1.2, F101.2, J2.1 (VBUS), J3.1, J3.2
VIN: D1.1 (K), D101.1 (K), M3J1.6, P2.15
XRDY: J1.18 (XRDY), P3.13
Z_INT2: J1.19 (~INT2), JP1.1 (A)
Z_INT6: J1.22 (~INT6), JP1.3 (B)

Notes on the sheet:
Zorro II edge connector (J1)
Card edge, 2x50 fingers. Pin 2 is rightmost seen from the component side. No series resistors, no buffers: every bus net goes straight to the module.
Pin 70 (/LDS) is not connected: GPIO18 is the microSD chip select here. The bus PIO programs wait on /AS and branch on READ only. With /UDS alone word access, Autoconfig and the rejection of an odd-byte write work; an even-byte write is taken as a word write. XRDY (18) comes straight from GPIO27 (3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
U1: Waveshare Core2350B B0 (RP2350B module, no PSRAM)
Four 2x8 pin strips P1-P4 round a 25.4 mm square, drawn here in the order of the GPIO numbers. GPIO0-17, 19-43 and 45 as in hardware/PINMAP.md. Different: GPIO18 microSD CS, GPIO44 / 46 / 47 I2S.
GPIO0-14
power, SWD, USB, GPIO45-47
GPIO15-29
GPIO30-44
P2: 5 BOOTSEL and 11 RUN to J5, 6 SWDIO and 10 SWCLK to J4, 7 / 9 USB D- / D+ to J2 and J3 (27R on the module). P2: 12 ADC_VREF and 13 3V3_EN not connected (3V3_EN open = module LDO on). P2.15 VBUS is the module's 5 V input (VIN, through D1); P2.16 its 3V3 output (ME6217C33 LDO), which also feeds M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
Power: bus +5 V only; D1 to the module, F1 to the USB port
The card is powered by the Amiga, or by the module's FPC adapter on the bench. The port never powers the card.
to U1 P2.15 and M3 VIN
to J2.1, J3.1, J3.2
JP2 OPEN as delivered. Bridge it only on a board without U2: +3V3 (U1 P2.16, module LDO) then feeds 3V3_AUX (M1, M2). U2 is fitted by default: JP2 stays open.
D1 1N5817 (DO-41) keeps bench power (the module's FPC USB adapter feeds the same VBUS net) off the Amiga's +5 V rail. F1 is all there is between the bus +5 V and the port: no series diode, no power switch IC. Resettable PTC, 0.9 A hold (trips at 1.8 A), 30 V or 16 V family, 5.08 mm leads: Littelfus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
Interrupt to the bus: Q1 NPN, open collector
GPIO45 high asserts the interrupt (push-pull, high = asserted: the drive of firmware feature int-nfet). JP1 is bridged 1-2 as delivered: /INT2. Cut 1-2 and bridge 2-3 for /INT6.
JP1 1 = /INT2 (J1 19, default) JP1 3 = /INT6 (J1 22)
Q1 2N3904, TO-92: emitter to GND, base through R1 (2.2k) to GPIO45, collector through JP1 to the bus. GPIO45 resets with its pull-down on: Q1 is off while the module is in reset; with the module absent the base is open and Q1 is off. A B2000 / A500+ pull the lines up with 1k (5 mA); the TRM's open-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
USB host port: J2 or J3 (fit one)
D+ / D- from U1 P2.9 / P2.7 (27R on the module) to J2 and J3 in parallel; only one of the two is used. VBUS_PORT from the bus +5 V through F1 (power block).
J2: type A, through-hole, right angle. Hole pattern of Molex 67643, Stewart SS-52100-001, Kycon KUSBX-AS1N, Connfly DS1095. 1 VBUS, 2 D-, 3 D+, 4 GND, shell to GND.
J3: 2x5, 2.54 mm, PC internal USB pinout. 1, 2 VBUS_PORT; 3 D-; 5 D+; 7, 8 GND. 9 is the key (pin absent). 4, 6 (a second port's data) and 10 (over-current sense on a PC): not connected. A slot bracket's first socket works, its second has power only. A 1x4 cable fits the odd row.
Pin map
module pin = header.pin; J1 = Zorro II finger. README.md, section Pin map, has the same table
GPIO GPIO0 GPIO1 GPIO2 GPIO3 GPIO4 GPIO5 GPIO6 GPIO7 GPIO8 GPIO9 GPIO10 GPIO11 GPIO12 GPIO13 GPIO14 GPIO15 GPIO16 GPIO17 GPIO18 GPIO19 GPIO20 GPIO21 GPIO22 GPIO23 GPIO24 GPIO25 GPIO26 GPIO27 GPIO28 GPIO29 GPIO30 GPIO31 GPIO32 GPIO33 GPIO34 GPIO35 GPIO36 GPIO37 GPIO38 GPIO39 GPIO40 GPIO41 GPIO42 GPI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
module pin P1.2 P1.4 P1.3 P1.6 P1.5 P1.8 P1.7 P1.10 P1.9 P1.12 P1.11 P1.14 P1.13 P1.16 P1.15 P3.2 P3.4 P3.3 P3.6 P3.5 P3.8 P3.7 P3.10 P3.9 P3.12 P3.11 P3.14 P3.13 P3.16 P3.15 P4.2 P4.4 P4.3 P4.6 P4.5 P4.8 P4.7 P4.10 P4.9 P4.12 P4.11 P4.14 P4.13 P4.16 P4.15 P2.2 P2.4 P2.3
net D0 D1 D2 D3 D4 D5 D6 D7 D8 D9 D10 D11 D12 D13 D14 D15 AS UDS SD_CS READ A1 A2 A3 A4 A5 A6 A7 XRDY A16 A17 A18 A19 A20 A21 A22 A23 CFGIN CFGOUT BUSRST NIC_INT SPI1_MISO NIC_CS SPI1_SCK SPI1_MOSI I2S_DIN INT_DRV I2S_BCK I2S_LCK
goes to J1 75 J1 77 J1 79 J1 81 J1 83 J1 86 J1 84 J1 82 J1 80 J1 78 J1 76 J1 71 J1 69 J1 67 J1 65 J1 63 J1 74 J1 72 M2.2 / J6.2 J1 68 J1 29 J1 27 J1 26 J1 24 J1 21 J1 23 J1 28 J1 18 J1 45 J1 47 J1 52 J1 54 J1 56 J1 58 J1 57 J1 59 J1 12 J1 11 J1 94 M1J1.6 M1J2.6, M2.5 / J6.7 M1J1.5 M1J1.4, M2.4 / J6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
DIY build (default variant): U1, M1, D1, F1, C1, C2, Q1, R1, J2 or J3. Optional: M2 (microSD), M3 (DAC). U2, C3, C4 fitted (3V3_AUX regulator; JP2 open). Not fitted (DNP): J4 (developers), J5 (recovery). JLC build (variant JLC): the SMD parts of block 11 instead of D1, F1, C1-C4, Q1, R1, U2 and M2;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
M1: W5500 "Lite" module (USR-ES1, WIZ850io pinout)
Two 1x6 rows, 2.54 mm, 20.32 mm apart, drawn as seen from the top with the jack opening away from the viewer. Pin 1 of each row at the jack-opening end. Module silk: J1 left row (M1J1), J2 right row (M1J2).
GND
MOSI
SCLK
SCNn
INTn
3.3V
RSTn

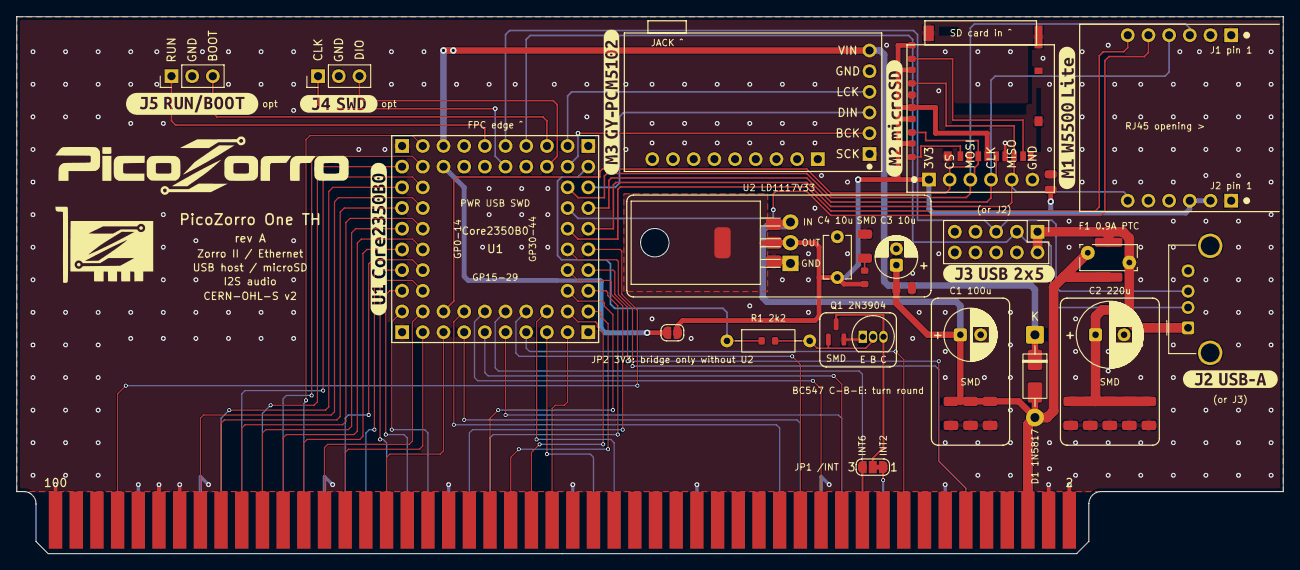
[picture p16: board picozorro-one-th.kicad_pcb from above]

Board: 2 copper layers, 155.5 x 65.9 mm, 48 parts (0 on the bottom side), 67 nets.

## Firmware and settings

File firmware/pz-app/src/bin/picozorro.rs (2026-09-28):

//! PicoZorro firmware: the Zorro II bus slave (Autoconfig, register window of
//! `docs/REGISTERS.md`) and the network path, one image for every board.
//!
//! Core 1: the bus service loop (`zbus.rs`), alone, from RAM.
//! Core 0: set-up first (the slave stays silent until an Amiga reset), then
//! the Ethernet chip on SPI1 if one answers (`pz_hal::chip`, `nic_task.rs`; none:
//! bus slave only, link down, TX frames dropped), and housekeeping: a text log
//! on the UART (GPIO46, 115200 8N1, TX only) and, with `usb-log` instead of
//! `usb-host`, on USB CDC ACM (`/dev/serial/by-id/usb-PicoZorro_picozorro-if00`, with the
//! picotool reset interface), defmt over RTT when a probe is attached, the
//! activity LED on GPIO39 when no W5500 owns that pin.
//!
//! `--features bench-host`: core 1 plays the Amiga driver instead
//! (`bench_host.rs`), for network tests from a PC; bus pins untouched.
//! `--features uart-backplane`: no bus slave; register cycles arrive over
//! UART0 on GPIO0/1 (`backplane.rs`), e.g. from FS-UAE through a serial
//! relay; the text log travels on that link.
//!
//! Build: `cargo run --release --bin picozorro` (the PicoZorro One: XRDY and
//! /INT from the GPIOs, USB host); without `xrdy-direct` / `int-nfet` for a
//! board with an XRDY gate and an open-drain /INT buffer.
#![no_std]
#![no_main]

#[cfg(all(feature = "bench-host", feature = "uart-backplane"))]
compile_error!("bench-host and uart-backplane both replace the bus slave: pick one");
#[cfg(all(feature = "usb-host", feature = "usb-log"))]
compile_error!("usb-host and usb-log both want the USB port: pick one (--no-default-features)");

#[cfg(feature = "uart-backplane")]
#[path = "../backplane.rs"]
mod backplane;
#[cfg(feature = "bench-host")]
#[path = "../bench_host.rs"]
mod bench_host;
#[path = "../nic_task.rs"]
mod nic_task;
#[path = "../update_task.rs"]
mod update_task;
#[path = "../boot_task.rs"]
mod boot_task;
#[cfg(feature = "mpeg")]
#[path = "../minimp3.rs"]
mod minimp3;
#[cfg(feature = "mpeg")]
#[path = "../mpeg_task.rs"]
mod mpeg_task;
#[allow(dead_code)] // bench-host and backplane builds only read its STATS
#[path = "../zbus.rs"]
mod zbus;

use core::fmt::Write as _;
#[cfg(not(feature = "uart-backplane"))]
use core::ptr::addr_of_mut;
use core::sync::atomic::Ordering::Relaxed;

use defmt::{info, unwrap};
use embassy_executor::Spawner;
use embassy_rp::bind_interrupts;
use embassy_rp::gpio::{Level, Output};
#[cfg(not(feature = "uart-backplane"))]
use embassy_rp::multicore::{spawn_core1, Stack};
use embassy_rp::peripherals::{PIO0, PIO1};
use embassy_rp::pio::InterruptHandler;
use embassy_rp::uart::Config as UartConfig;
#[cfg(not(feature = "uart-backplane"))]
use embassy_rp::uart::UartTx;
use embassy_time::Timer;
use pz_core::nic::Shared;
use pz_hal::{chip, chip_pins};
use static_cell::StaticCell;
use {defmt_rtt as _, panic_probe as _};

bind_interrupts!(struct Irqs {
    PIO0_IRQ_0 => InterruptHandler<PIO0>;
    PIO1_IRQ_0 => InterruptHandler<PIO1>;
});
#[cfg(feature = "usb-host")]
bind_interrupts!(struct UsbIrqs {
    USBCTRL_IRQ => embassy_rp::usb::host::InterruptHandler<embassy_rp::peripherals::USB>;
});
#[cfg(feature = "usb-log")]
bind_interrupts!(struct UsbIrqs {
    USBCTRL_IRQ => embassy_rp::usb::InterruptHandler<embassy_rp::peripherals::USB>;
});
#[cfg(feature = "uart-backplane")]
bind_interrupts!(struct UartIrqs {
    UART0_IRQ => embassy_rp::uart::BufferedInterruptHandler<embassy_rp::peripherals::UART0>;
});

static SHARED: StaticCell<Shared> = StaticCell::new();
static UPDATE: StaticCell<pz_core::update::Shared> = StaticCell::new();
static BOOT: StaticCell<pz_core::boot::Shared> = StaticCell::new();
#[cfg(feature = "mpeg")]
static MPEG: StaticCell<pz_core::mpeg::Shared> = StaticCell::new();
#[cfg(feature = "usb-host")]
static USB_WIN: StaticCell<pz_core::usb::Shared> = StaticCell::new();

/// The USB device (`usb-log`): CDC ACM carrying the text log (each finished
/// `Log` line, through embassy-usb-logger) and the picotool reset interface.
#[cfg(feature = "usb-log")]
#[embassy_executor::task]
async fn usb_log_task(usb: embassy_rp::Peri<'static, embassy_rp::peripherals::USB>) -> ! {
    // SAFETY: update_task owns the watchdog for feeding and its scratch
    // words; the reset interface only uses it for `trigger_reset` on
    // picotool's RESET_REQUEST_FLASH, after which nothing runs.
    let wd = embassy_rp::watchdog::Watchdog::new(unsafe { embassy_rp::peripherals::WATCHDOG::steal() });
    let driver = embassy_rp::usb::Driver::new(usb, UsbIrqs);
    let (mut device, class) = pz_hal::usb::cdc_with_reset(driver, wd, "picozorro");
    let log_fut = embassy_usb_logger::with_class!(1024, log::LevelFilter::Info, class);
    embassy_futures::join::join(device.run(), log_fut).await;
    unreachable!()
}

// The latency-sensitive tasks (network, backplane) run on this executor,
// which preempts the thread-mode one; the MPEG decoder and the update task
// stay in thread mode. The decoder holds core 0 for ~3 ms per frame: next
// to it in thread mode the backplane would fall behind, the UART's RX buffer
// fill and the hardware FIFO overrun.
static EXECUTOR_HIGH: embassy_executor::InterruptExecutor = embassy_executor::InterruptExecutor::new();

use embassy_rp::interrupt;

#[interrupt]
unsafe fn SWI_IRQ_1() {
    // SAFETY: the executor's own interrupt, started once in main.
    unsafe { EXECUTOR_HIGH.on_interrupt() }
}

/// Whether the Ethernet chip answered (net_init to main).
static NET_UP: embassy_sync::signal::Signal<embassy_sync::blocking_mutex::raw::CriticalSectionRawMutex, bool> =
    embassy_sync::signal::Signal::new();

/// Runs on EXECUTOR_HIGH: gets that executor's own Spawner and hands the
/// bring-up to `net_init` there. The network driver's state is not Send
/// (embassy-net's channel uses a NoopRawMutex), so its tasks can only be
/// spawned from inside the executor they run on; this task's arguments are.
#[embassy_executor::task]
async fn net_start(pins: chip::Pins, nic: pz_core::nic::NicPort<'static>, mac: [u8; 6]) {
    // SAFETY: polled by the Embassy InterruptExecutor, as the method needs.
    let spawner = unsafe { Spawner::for_current_executor() }.await;
    spawner.spawn(unwrap!(net_init(spawner, pins, nic, mac)));
}

/// Runs on EXECUTOR_HIGH, next to the network: the USB host (workers,
/// root port, interrupt readers; pz_hal::usb_host) and the USB window's
/// host side. Its tasks are not Send either, so they start from here.
#[cfg(feature = "usb-host")]
#[embassy_executor::task]
async fn usb_start(usb: embassy_rp::Peri<'static, embassy_rp::peripherals::USB>, host: pz_core::usb::HostPort<'static>) {
    use pz_hal::usb_host;
    // SAFETY: polled by the Embassy InterruptExecutor, as the method needs.
    let spawner = unsafe { Spawner::for_current_executor() }.await;
    usb_host::start(spawner, embassy_rp::usb::host::Driver::new(usb, UsbIrqs), "picozorro");
    info!("usb: host up, USB window at A16 = 1");
    // The request queue is looked at every 250 us (nothing on the bus side
    // wakes this task) and at once when a transfer finishes.
    usb_host::WindowHost::new(host).run(embassy_time::Duration::from_micros(250)).await
}

#[embassy_executor::task]
async fn net_init(spawner: Spawner, pins: chip::Pins, nic: pz_core::nic::NicPort<'static>, mac: [u8; 6]) {
    // The Ethernet chip, if one is fitted (~100 ms either way).
    match chip::bring_up(&spawner, pins, mac).await {
        Some(dev) => {
            spawner.spawn(unwrap!(nic_task::nic_task(dev, nic, mac)));
            NET_UP.signal(true);
        }
        None => {
            spawner.spawn(unwrap!(nic_task::drain_task(nic)));
            NET_UP.signal(false);
        }
    }
}
#[cfg(not(any(feature = "bench-host", feature = "uart-backplane")))]
static mut CORE1_STACK: Stack<8192> = Stack::new();
#[cfg(feature = "bench-host")]
static mut CORE1_STACK: Stack<32768> = Stack::new();

#[embassy_executor::main]
async fn main(spawner: Spawner) {
    let p = embassy_rp::init(clock_config());
    let high = {
        use embassy_rp::interrupt::{InterruptExt, Priority};
        interrupt::SWI_IRQ_1.set_priority(Priority::P2);
        // The GPIO and DMA interrupts wake tasks on this executor; embassy-rp
        // leaves them at P3, below it. embassy-sync's lockless AtomicWaker
        // (git main) sets WAKING, wakes, then clears WAKING: an executor that
        // preempts the interrupt in between finds WAKING when its task
        // registers again, is woken again at once, and never lets the
        // interrupt finish (seen with the W5500 /INT wait: every thread-mode
        // task starved). Above the executor, their short handlers always
        // finish first.
        interrupt::IO_IRQ_BANK0.set_priority(Priority::P1);
        interrupt::DMA_IRQ_0.set_priority(Priority::P1);
        EXECUTOR_HIGH.start(interrupt::SWI_IRQ_1)
    };

    let chip_id = embassy_rp::otp::get_chipid().unwrap_or(0);
    let mac = pz_core::mac::from_chip_id(chip_id);
    let shared = SHARED.init_with(|| Shared::new(mac));
    let (bus, nic) = shared.split();
    // Firmware update (docs/UPDATE.md): the registers in the window, the
    // flash side as a task. Every image carries it: one that boots on trial
    // after an update keeps the watchdog fed and takes CONFIRM here.
    let (upd_bus, upd_host) = UPDATE.init_with(pz_core::update::Shared::new).split();
    let layout = update_task::probe();
    let mut wd = embassy_rp::watchdog::Watchdog::new(p.WATCHDOG);
    let resume_base = update_task::take_stash(&mut wd);
    // Boot ROM: the ROM goes in before the bus side runs;
    // the stream is a task. No image in the build: no boot ROM.
    #[cfg_attr(feature = "bench-host", allow(unused_variables))]
    let boot_bus = {
        let (b, mut h) = BOOT.init_with(pz_core::boot::Shared::new).split();
        b.shared().set_enabled(!update_task::bootrom_off());
        if let Some(img) = boot_task::image() {
            h.set_rom(unwrap!(img.rom().ok()));
            spawner.spawn(unwrap!(boot_task::run(h, img)));
        }
        b
    };
    spawner.spawn(unwrap!(update_task::run(upd_host, layout, wd, boot_bus.shared())));
    // MPEG audio decoder (docs/REGISTERS-MPEG.md): registers at A16 = 1,
    // minimp3 as a task.
    #[cfg(feature = "mpeg")]
    #[cfg_attr(feature = "bench-host", allow(unused_variables))]
    let mpeg_bus = {
        let (b, h) = MPEG.init_with(pz_core::mpeg::Shared::new).split();
        spawner.spawn(unwrap!(mpeg_task::run(h)));
        b
    };
    // USB host (docs/REGISTERS-USB.md): the window at A16 = 1; its host
    // side starts on the high-priority executor below, after the bus.
    #[cfg(feature = "usb-host")]
    #[cfg_attr(feature = "bench-host", allow(unused_variables))]
    let (usb_bus, usb_host_port) = USB_WIN.init_with(pz_core::usb::Shared::new).split();
    // SAFETY: the only reference to the core-1 stack, taken once.
    #[cfg(not(feature = "uart-backplane"))]
    let stack = unsafe { &mut *addr_of_mut!(CORE1_STACK) };

    // Core 1 first: the bus pins are set up and silent before anything else;
    // the Ethernet chip comes after.
    #[cfg(not(any(feature = "bench-host", feature = "uart-backplane")))]
    {
        use embassy_rp::pio::Pio;
        macro_rules! any {
            ($($p:expr),* $(,)?) => { [$($p.into()),*] };
        }
        let window = pz_core::window::Window::new(bus).with_update(upd_bus).with_boot(boot_bus);
        #[cfg(feature = "mpeg")]
        let window = window.with_mpeg(mpeg_bus);
        #[cfg(feature = "usb-host")]
        let window = window.with_usb_window(usb_bus);
        let mut window = window;
        if let Some(base) = resume_base {
            // Rebooted into a new image by an update: `Zbus::new` answers at
            // this base again if the Amiga is not in reset.
            window.slave.state = pz_core::slave::State::Configured;
            window.slave.base = base;
        }
        let Pio { common: mut c0, sm0: data, .. } = Pio::new(p.PIO0, Irqs);
        let Pio { common: mut c1, sm0: decode, .. } = Pio::new(p.PIO1, Irqs);
        macro_rules! pio_pins {
            ($c:ident; $($p:expr),* $(,)?) => { [$($c.make_pio_pin($p)),*] };
        }
        let pins = zbus::BusPins {
            d: pio_pins![c0; p.PIN_0, p.PIN_1, p.PIN_2, p.PIN_3, p.PIN_4, p.PIN_5, p.PIN_6, p.PIN_7, p.PIN_8,
                p.PIN_9, p.PIN_10, p.PIN_11, p.PIN_12, p.PIN_13, p.PIN_14, p.PIN_15],
            strobes_a1_a7: any![
                p.PIN_16, p.PIN_17, p.PIN_18, p.PIN_19, p.PIN_20, p.PIN_21, p.PIN_22, p.PIN_23, p.PIN_24, p.PIN_25,
                p.PIN_26
            ],
            match_field: pio_pins![c1; p.PIN_28, p.PIN_29, p.PIN_30, p.PIN_31, p.PIN_32, p.PIN_33, p.PIN_34,
                p.PIN_35, p.PIN_36],
            #[cfg(not(feature = "xrdy-direct"))]
            xrdy: p.PIN_27.into(),
            #[cfg(not(feature = "xrdy-direct"))]
            arm: c1.make_pio_pin(p.PIN_44),
            #[cfg(feature = "xrdy-direct")]
            xrdy: c1.make_pio_pin(p.PIN_27),
            #[cfg(feature = "xrdy-direct")]
            arm: p.PIN_44.into(),
            cfgout: p.PIN_37.into(),
            busrst: p.PIN_38.into(),
            int: p.PIN_45.into(),
        };
        let slave = zbus::Zbus::new(&mut c0, data, &mut c1, decode, pins, window);
        // The programs stay loaded: the PIO blocks are never handed back.
        core::mem::forget(c0);
        core::mem::forget(c1);
        spawn_core1(p.CORE1, stack, move || slave.serve_forever());
    }
    #[cfg(feature = "bench-host")]
    {
        let _ = (resume_base, upd_bus);
        spawn_core1(p.CORE1, stack, move || bench_host::run(bus, mac));
    }

    // Backplane: the window lives on core 0, served from the UART; core 1
    // stays off.
    #[cfg(feature = "uart-backplane")]
    let mut log = {
        static TX_BUF: StaticCell<[u8; 4096]> = StaticCell::new();
        static RX_BUF: StaticCell<[u8; 4096]> = StaticCell::new();
        let mut cfg = UartConfig::default();
        cfg.baudrate = backplane::BAUD;
        let uart = embassy_rp::uart::BufferedUart::new(
            p.UART0,
            p.PIN_0,
            p.PIN_1,
            UartIrqs,
            TX_BUF.init([0; 4096]),
            RX_BUF.init([0; 4096]),
            cfg,
        );
        let window = pz_core::window::Window::new(bus).with_update(upd_bus).with_boot(boot_bus);
        #[cfg(feature = "mpeg")]
        let window = window.with_mpeg(mpeg_bus);
        #[cfg(feature = "usb-host")]
        let window = window.with_usb_window(usb_bus);
        let mut window = window;
        if let Some(base) = resume_base {
            // Rebooted into a new image by an update: the Amiga still has
            // the board at this base, so carry on configured there.
            window.slave.state = pz_core::slave::State::Configured;
            window.slave.base = base;
            info!("update: resuming configured at base {:x}", base);
        }
        high.spawn(unwrap!(backplane::run(window, uart)));
        Log(core::marker::PhantomData)
    };
    #[cfg(not(feature = "uart-backplane"))]
    let mut log = Log { uart: UartTx::new_blocking(p.UART0, p.PIN_46, UartConfig::default()), line: [0; 200], len: 0 };
    banner(&mut log, &mac);

    // The Ethernet chip, if one is fitted (~100 ms either way), brought up
    // on the high-priority executor, where the network tasks run (above
    // the MPEG decoder).
    // The USB host, next to the network (no USB host behind bench-host).
    #[cfg(all(feature = "usb-host", not(feature = "bench-host")))]
    high.spawn(unwrap!(usb_start(p.USB, usb_host_port)));
    #[cfg(feature = "usb-log")]
    spawner.spawn(unwrap!(usb_log_task(p.USB)));
    high.spawn(unwrap!(net_start(chip_pins!(p), nic, mac)));
    let led = match NET_UP.wait().await {
        true => {
            let _ = writeln!(log, "{} up, SCK {} kHz, network registers live", chip::NAME, chip::spi_sck_hz() / 1000);
            None // GPIO39 is the chip's /INT now; the chip drives the LED
        }
        false => {
            let _ = writeln!(log, "no {}: bus slave only (link down, TX frames dropped)", chip::NAME);
            info!("no {}: bus slave only", chip::NAME);
            // SAFETY: bring_up has dropped its GPIO39 input on the way out;
            // nothing else owns the pin.
            Some(Output::new(unsafe { embassy_rp::peripherals::PIN_39::steal() }, Level::Low))
        }
    };
    #[cfg(feature = "bench-host")]
    let _ = writeln!(log, "bench host on core 1, answering at 10.42.0.2 (not for use in an Amiga)");
    #[cfg(feature = "uart-backplane")]
    let _ = writeln!(log, "UART backplane on GPIO0/1, {} baud (not for use in an Amiga)", backplane::BAUD);

    housekeeping(log, led).await
}

#[cfg(feature = "uart-backplane")]
struct Log<'d>(core::marker::PhantomData<&'d ()>);

#[cfg(feature = "uart-backplane")]
impl core::fmt::Write for Log<'_> {
    fn write_str(&mut self, s: &str) -> core::fmt::Result {
        let _ = backplane::LOG.try_write(s.as_bytes()); // full: dropped
        Ok(())
    }
}

/// Text to the UART; with `usb-log` each finished line also to USB CDC.
#[cfg(not(feature = "uart-backplane"))]
struct Log<'d> {
    uart: UartTx<'d, embassy_rp::mode::Blocking>,
    line: [u8; 200],
    len: usize,
}

#[cfg(not(feature = "uart-backplane"))]
impl core::fmt::Write for Log<'_> {
    fn write_str(&mut self, s: &str) -> core::fmt::Result {
        for chunk in s.as_bytes().split_inclusive(|&b| b == b'\n') {
            let (body, eol) = match chunk.split_last() {
                Some((&b'\n', body)) => (body, true),
                _ => (chunk, false),
            };
            let _ = self.uart.blocking_write(body);
            let n = body.len().min(self.line.len() - self.len);
            self.line[self.len..self.len + n].copy_from_slice(&body[..n]);
            self.len += n;
            if eol {
                let _ = self.uart.blocking_write(b"\r\n");
                #[cfg(feature = "usb-log")]
                if let Ok(t) = core::str::from_utf8(&self.line[..self.len]) {
                    log::info!("{}", t);
                }
                self.len = 0;
            }
        }
        Ok(())
    }
}

/// clk_sys: embassy's 150 MHz, or pll_sys from the 12 MHz crystal with the
/// `oc240` / `oc300` features (VCO 1440 / 6 = 240, VCO 1500 / 5 = 300). The
/// bus loop's settle delay is computed from the clock at run time; the UART,
/// SPI and USB take their divisors from embassy's clock record. Overclocked,
/// clk_peri moves off clk_sys (`crystal()` puts it there; the datasheet rates
/// clk_peri at 150 MHz at most) onto pll_usb, raised to 144 MHz (VCO 1440 /
/// 5 / 2) with clk_usb and clk_adc at 144 / 3 = 48 MHz. SPI can then run at
/// 144 / 2 / n: 72, 36, 24 MHz (`PZ_SPI_HZ`, pz_hal::chip).
fn clock_config() -> embassy_rp::config::Config {
    #[allow(unused_mut)]
    let mut c = embassy_rp::config::Config::default();
    #[cfg(any(feature = "oc240", feature = "oc300"))]
    {
        use embassy_rp::clocks::{ClockConfig, CoreVoltage, PeriClkSrc, PllConfig};
        let mut clocks = ClockConfig::crystal(12_000_000);
        let (fbdiv, post_div1, mv) = if cfg!(feature = "oc300") {
            (125, 5, CoreVoltage::V1_25)
        } else {
            (120, 6, CoreVoltage::V1_15)
        };
        if let Some(x) = clocks.xosc.as_mut() {
            x.sys_pll = Some(PllConfig { refdiv: 1, fbdiv, post_div1, post_div2: 1 });
        }
        clocks.core_voltage = mv;
        if let Some(x) = clocks.xosc.as_mut() {
            x.usb_pll = Some(PllConfig { refdiv: 1, fbdiv: 120, post_div1: 5, post_div2: 2 });
        }
        if let Some(u) = clocks.usb_clk.as_mut() {
            u.div = 3;
        }
        if let Some(a) = clocks.adc_clk.as_mut() {
            a.div = 3;
        }
        clocks.peri_clk_src = Some(PeriClkSrc::PllUsb);
        c.clocks = clocks;
    }
    c
}

/// The stepping from the bootrom version byte: 2 = A2, 3 = A3, 4 = A4.
fn stepping() -> (&'static str, bool) {
    match embassy_rp::rom_data::rom_version_number() {
        2 => ("A2", true),
        3 => ("A3", false),
        4 => ("A4", false),
        _ => ("unknown", false),
    }
}

/// One line per PIO block for the log: GPIOBASE, program counter, jump pin,
/// wrap, pin bases, IN_COUNT, FIFO levels. What the state machines look like
/// on real silicon, e.g. both idle at their first instructions with no bus.
fn pio_report(log: &mut Log<'_>) {
    use embassy_rp::pac;
    for (name, pio) in [("PIO0 data  ", pac::PIO0), ("PIO1 decode", pac::PIO1)] {
        let sm = pio.sm(0);
        let e = sm.execctrl().read();
        let pc = sm.pinctrl().read();
        let sh = sm.shiftctrl().read();
        let base = if pio.gpiobase().read().gpiobase() { 16 } else { 0 };
        let pcv = sm.addr().read().addr();
        let en = pio.ctrl().read().sm_enable();
        let lvl = pio.flevel().read().0;
        let _ = write!(
            log,
            "{}: enabled {:x} gpiobase {} pc {} jmp_pin {} wrap {}..{} in_base {} in_count {} out_base {} set_base {} side_base {} flevel {:08x}\n",
            name,
            en,
            base,
            pcv,
            e.jmp_pin(),
            e.wrap_bottom(),
            e.wrap_top(),
            pc.in_base(),
            sh.in_count(),
            pc.out_base(),
            pc.set_base(),
            pc.sideset_base(),
            lvl
        );
        info!(
            "{}: en {:x} gpiobase {} pc {} jmp_pin {} wrap {}..{} in_base {} in_count {} out_base {} set_base {} side_base {} flevel {:08x}",
            name,
            en,
            base,
            pcv,
            e.jmp_pin(),
            e.wrap_bottom(),
            e.wrap_top(),
            pc.in_base(),
            sh.in_count(),
            pc.out_base(),
            pc.set_base(),
            pc.sideset_base(),
            lvl
        );
    }
}
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

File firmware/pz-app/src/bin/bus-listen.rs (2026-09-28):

//! Passive bus listener for a card's first hours in an Amiga: nothing on
//! the Zorro bus is ever driven. Every bus GPIO (0-38) is a plain input with
//! no pull, the XRDY gate is held disarmed (/ARM, GPIO44, pulled up), /CFGOUT
//! is never driven (the slot's pull-down passes the config chain on, so the
//! Amiga boots as if the slot were empty), /INT (GPIO45) and GPIO47 are not
//! touched.
//!
//! What it shows, as text on the UART (GPIO46, 115200 8N1, TX only, as
//! `picozorro`) and on USB CDC (with the picotool reset interface so
//! `picotool load -f` re-flashes without BOOTSEL):
//! - a banner: stepping, chip ID (OTP unique ID), VREG voltage, clk_sys;
//! - once per second: the bus pins now, which of them moved during the
//!   second (bus alive, no open finger), and the /AS statistics below.
//!
//! /AS statistics come from PIO1 (GPIOBASE 16, so it sees GPIO16-36):
//! per /AS falling edge the state machine captures GPIO16-36 (strobes, R/W,
//! A1-A7, XRDY, A16-A23, /CFGIN) one clk_sys after the edge came through
//! the input synchroniser, then counts /AS low in a two-instruction loop.
//! Resolution: 2 clk_sys = 13.3 ns at 150 MHz; both edges pass the same
//! two-flop synchroniser, so its delay cancels, and the reported time is
//! (2 n + 3) clk_sys, within +-1 clk_sys of the truth. Core 1 drains the
//! joined 8-deep RX FIFO and samples SIO GPIO_IN in the same loop (a few
//! tens of ns per pass) for the "moved" masks. A full FIFO stalls the
//! state machine (`push block`): that second's numbers then miss cycles
//! and the line says so (stalls).
//!
//! Build matches the board: `--features xrdy-direct` when GPIO27 is on the
//! bus XRDY (the XRDY column is the bus line); the default keeps GPIO27
//! pulled down, as `picozorro` does on a board with the XRDY gate.
//!
//! Flash: `cargo run --release --bin bus-listen [--features xrdy-direct]`
//! (SWD probe) or `picotool load -f -x` on the ELF (USB).
#![no_std]
#![no_main]

use core::fmt::Write as _;
use core::ptr::addr_of_mut;
use core::sync::atomic::{AtomicU32, Ordering};

use embassy_executor::Spawner;
use embassy_futures::join::join;
use embassy_rp::bind_interrupts;
use embassy_rp::gpio::{AnyPin, Input, Level, Output, Pull};
use embassy_rp::multicore::{spawn_core1, Stack};
use embassy_rp::pac;
use embassy_rp::peripherals::{PIO1, USB};
use embassy_rp::pio::{Config, ExecConfig, FifoJoin, InterruptHandler, Pio, PinConfig, ShiftConfig, ShiftDirection};
use embassy_rp::uart::{Config as UartConfig, UartTx};
use embassy_rp::usb::{Driver, InterruptHandler as UsbInterruptHandler};
use embassy_rp::watchdog::Watchdog;
use embassy_rp::Peri;
use embassy_time::{Instant, Timer};
use pz_core::pins;
use {defmt_rtt as _, panic_probe as _};

bind_interrupts!(struct Irqs {
    PIO1_IRQ_0 => InterruptHandler<PIO1>;
    USBCTRL_IRQ => UsbInterruptHandler<USB>;
});

/// Bits of the word the PIO captures at /AS falling: GPIO16-36, bit 0 = GPIO16.
mod snap {
    pub const READ: u32 = 1 << 3;
    pub const CFGIN: u32 = 1 << 20;
    pub fn a1_a7(w: u32) -> u32 {
        (w >> 4) & 0x7f
    }
    pub fn a16_a23(w: u32) -> u32 {
        (w >> 12) & 0xff
    }
}

/// One second of statistics, published by core 1 under a sequence count
/// (odd while it writes), read by core 0.
struct Published {
    seq: AtomicU32,
    edges: AtomicU32,
    reads: AtomicU32,
    cfgin_low: AtomicU32,
    e8: AtomicU32,
    e8_cfgin_low: AtomicU32,
    low_min: AtomicU32,
    low_max: AtomicU32,
    low_sum_lo: AtomicU32,
    last_e8: AtomicU32,
    stalls: AtomicU32,
    seen_low0: AtomicU32,
    seen_high0: AtomicU32,
    seen_low1: AtomicU32,
    seen_high1: AtomicU32,
}

#[allow(clippy::declare_interior_mutable_const)]
const Z: AtomicU32 = AtomicU32::new(0);
static PUB: Published = Published {
    seq: Z,
    edges: Z,
    reads: Z,
    cfgin_low: Z,
    e8: Z,
    e8_cfgin_low: Z,
    low_min: Z,
    low_max: Z,
    low_sum_lo: Z,
    last_e8: Z,
    stalls: Z,
    seen_low0: Z,
    seen_high0: Z,
    seen_low1: Z,
    seen_high1: Z,
};

/// Core 1's running second.
#[derive(Clone, Copy)]
struct Acc {
    edges: u32,
    reads: u32,
    cfgin_low: u32,
    e8: u32,
    e8_cfgin_low: u32,
    /// /AS low, in loop passes of the PIO counter (2 clk_sys each)
    low_min: u32,
    low_max: u32,
    low_sum: u64,
    last_e8: u32,
    seen_low: [u32; 2],
    seen_high: [u32; 2],
}

impl Acc {
    const fn new() -> Self {
        Acc {
            edges: 0,
            reads: 0,
            cfgin_low: 0,
            e8: 0,
            e8_cfgin_low: 0,
            low_min: u32::MAX,
            low_max: 0,
            low_sum: 0,
            last_e8: u32::MAX,
            seen_low: [0; 2],
            seen_high: [0; 2],
        }
    }

    #[inline(always)]
    fn cycle(&mut self, w: u32, passes: u32) {
        self.edges += 1;
        if w & snap::READ != 0 {
            self.reads += 1;
        }
        let cfg = w & snap::CFGIN == 0;
        if cfg {
            self.cfgin_low += 1;
        }
        if snap::a16_a23(w) == 0xe8 {
            self.e8 += 1;
            if cfg {
                self.e8_cfgin_low += 1;
            }
            self.last_e8 = w;
        }
        self.low_min = self.low_min.min(passes);
        self.low_max = self.low_max.max(passes);
        self.low_sum += u64::from(passes);
    }

    fn publish(&self, stalls: u32) {
        use Ordering::{Relaxed, Release};
        let p = &PUB;
        let s = p.seq.load(Relaxed);
        p.seq.store(s.wrapping_add(1), Release);
        p.edges.store(self.edges, Relaxed);
        p.reads.store(self.reads, Relaxed);
        p.cfgin_low.store(self.cfgin_low, Relaxed);
        p.e8.store(self.e8, Relaxed);
        p.e8_cfgin_low.store(self.e8_cfgin_low, Relaxed);
        p.low_min.store(self.low_min, Relaxed);
        p.low_max.store(self.low_max, Relaxed);
        // a second holds < 2^24 cycles of < 2^8 passes typical: the low
        // 32 bits of the sum are enough for the average
        p.low_sum_lo.store(self.low_sum as u32, Relaxed);
        p.last_e8.store(self.last_e8, Relaxed);
        p.stalls.store(stalls, Relaxed);
        p.seen_low0.store(self.seen_low[0], Relaxed);
        p.seen_high0.store(self.seen_high[0], Relaxed);
        p.seen_low1.store(self.seen_low[1], Relaxed);
        p.seen_high1.store(self.seen_high[1], Relaxed);
        p.seq.store(s.wrapping_add(2), Release);
    }
}
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

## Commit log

2026-09-18 docs: Zorro II electrical facts, edge-connector orientation, GPIO map
2026-09-19 hardware: KiCad library with the Zorro II edge connector
2026-09-24 firmware: pz-core and the vendored crates
    pz-core is the no_std model of the card: Autoconfig, the register window,
    the network rings, the USB and MPEG windows, the boot stream and the
    firmware update registers, with host tests. vendor/ holds the W5500 driver
    (embassy-net-wiznet with the MAC filter and PHY additions) and minimp3.
2026-09-25 amiga: picozorro.device, the SANA-II driver
2026-09-28 amiga: picozorrousb.device, the USB host driver for Poseidon
2026-10-06 hardware: PicoZorro One TH, rev A
    Through-hole Zorro II card from a Waveshare Core2350B module, a W5500
    module and a handful of through-hole parts. Schematic, routed board and
    fabrication files. Not built yet.
    [PCM5102-I2S.step, core2350b.step, microsd-breakout.step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]
2026-10-06 One TH: isometric render of the board
2026-10-07 picozorrousb.device: a 10 ms floor for interrupt polling, PROF=1 timing
    The poll interval the driver asks of the card for an interrupt IN endpoint
    is now at least 10 ms; minpoll=N in ENV:PZUSB sets another floor, 0 none.
    On a 68030 a delivered HID report costs about 3.5 ms across the driver,
    hid.class, input.device and Intuition, so a mouse polled at its own 2 ms
    interval kept the CPU busy: 313 reports/s, and 16 KiB stick reads fell to
    123 KB/s while it moved. With the floor: 74 reports/s, reads at 166 KB/s.
    make PROF=1 builds the driver with E-clock timestamps around each
    interrupt IN report; pzusbprof prints or resets them.
    [device.h]
2026-10-07 One TH: SMD alternates for a JLC-assembled build, power block reworked
    One board, two builds. The default build stays all through-hole; the
    KiCad variant JLC fits an SMD alternate on the same nets for every
    through-hole part: SS14, 1812 PTC, MMBT3904, 0603 resistors, an
    AMS1117-3.3 under the TO-220, 22 uF MLCC banks under the electrolytics
    and a Hirose microSD socket in place of the breakout. The silk frames
    each pair with one label.
    Power: U2 supplies 3V3_AUX in both builds, JP2 is the fallback without
    it, C3 is 10 uF. Bus routing unchanged.
    The 3D models carry KiCad's own sockets and jack; the DAC model is the
    project's own, which drops the GPL zynthian STEP. Fab files add the JLC
    BOM an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
    [PCM5102-I2S.step, core2350b.step, gy-pcm5102.step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]
2026-10-07 CI: build firmware and Amiga software, draft release on tag
    The amiga job builds the drivers, mpega.library, pzflash and the tools
    with the pinned bebbo image, and the boot image. The firmware job embeds
    that boot.img, runs the host tests and makes picozorro-install.uf2 and
    picozorro.pzf with a prebuilt picotool 2.3.1. A v* tag creates a draft
    release carrying both, with SHA256SUMS; the image reports the tag as
    its version.
    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

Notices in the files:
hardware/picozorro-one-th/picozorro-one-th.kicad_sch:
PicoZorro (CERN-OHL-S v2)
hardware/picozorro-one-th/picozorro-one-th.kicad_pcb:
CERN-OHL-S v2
